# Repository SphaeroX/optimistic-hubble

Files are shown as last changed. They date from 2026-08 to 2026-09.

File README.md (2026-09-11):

# Audio Vault ESP32-C3 - Ultra-Low-Power Voice Assistant & Companion Monorepo

An embedded voice recording, signal processing, and companion application monorepo built for the **ESP32-C3**, featuring **two I2S MEMS microphones**, an **IMU sensor** with **Ultra-Low-Power Deep Sleep (< 10 µA)** & **Hardware Shock Wakeup**, **persistent Flash storage (`LittleFS`)**, and a **Flutter Multiplatform Companion App** supporting **Android, iOS, and Windows Desktop**.

---

## Monorepo Architecture

```
optimistic-hubble/
├── apps/
│   └── companion_app/           # Flutter Multiplatform App (Android, iOS, Windows, macOS, Web)
│       ├── lib/                 # Clean, modular Dart architecture (Theme, BLE, Wi-Fi sync, Telemetry)
│       ├── android/             # Android project & permissions
│       ├── ios/                 # iOS project & Info.plist permissions
│       └── windows/             # Windows desktop runner & Win32 window config
├── firmware/                    # PlatformIO ESP32-C3 Firmware
│   ├── src/                     # Audio recorder, BLE service, Wi-Fi SoftAP server, IMU drivers
│   ├── platformio.ini           # Board definitions, partition tables & compiler flags
│   └── esp32c3_hw_test.ino      # Hardware test & validation sketch
├── research/                    # IoT transfer studies, BLE/Wi-Fi benchmarks & protocol docs
├── 01_flash_mcu.bat             # Builds, flashes and monitors ESP32-C3
├── 02_run_flutter_device.bat    # Launches Flutter companion app on connected device
├── 03_build_apk.bat             # Builds Flutter Android Release APK
├── 03_flash_and_build_apk.bat   # Flashes ESP32-C3 firmware and builds Android APK
├── 04_monitor.bat               # Starts serial monitor (115200 baud)
├── 05_run_flutter_windows.bat   # Launches Flutter companion app on Windows desktop
└── 06_erase_flash.bat           # Completely wipes ESP32 Flash memory and resets LittleFS
```

---

## Quick Start Guide

### 1. Running the Flutter Companion App
* **Windows Desktop (Testing on PC):**
  ```powershell
  .\run_flutter_windows.bat
  # Or:
  cd apps\companion_app
  flutter run -d windows
  ```
* **Android:**
  ```powershell
  cd apps\companion_app
  flutter run -d android
  ```
* **iOS:**
  ```powershell
  cd apps\companion_app
  flutter run -d ios
  ```

### 2. Building, Flashing & Packaging
* **Flash MCU & Build Android APK (All-in-One):** Double-click `flash_and_build_apk.bat`
* **Build Android APK Only:** Double-click `build_apk.bat`
* **Flash MCU & Monitor:** Double-click `flash_mcu.bat`
* **Full Flash Erase & Reset:** Double-click `erase_flash.bat`

---

## Key Features

* **Ultra-Low-Power Deep Sleep (< 10 µA):** ESP32-C3 drops to ~8 µA in sleep mode, extending battery life from ~2 hours to **over 3 months** on a compact 300 mAh LiPo!
* **Hardware Shock / Tap Wake-Up:** LSM6DS3 / BMI160 / MPU-6050 configured in low-power interrupt mode automatically wakes the MCU upon shock/tap (> 1.4g) and instantly begins recording.
* **On-Demand Wi-Fi Hotspot:** High-power Wi-Fi SoftAP (~150 mA) and I2S DMA (~5 mA) are dynamically powered down during idle and activated only on-demand via BLE command or Boot button (D7).
* **Hardware Dual-Mic Noise Filtering (On-Chip DSP):** Both MEMS microphones are sampled with 100% hardware phase-synchronicity. The firmware combines both channels in real-time with coherent beamforming ($+6\text{ dB}$ voice boost and ambient noise cancellation), outputting a crystal-clear single-line mono stream.
* **4:1 IMA-ADPCM Hardware Compression (8 KB/s):** Audio is compressed on-the-fly to 4-bit per sample (8,000 bytes/sec @ 16 kHz Mono). Over **4 minutes** of audio fit into the 1.92 MB Flash partition!
* **+18 dB Digital Preamp Gain:** Integrated digital pre-amplifier with soft-limiting delivers loud, crisp, full-scale audio without clipping.
* **Universal Standard 16-Bit PCM WAV Export:** Downloads generate 100% standard Linear 16-Bit PCM WAV files (`Format Tag 1`) compatible with **Windows Media Player, VLC, QuickTime, Android, iOS, and Audacity**.
* **Zero-Drop Direct-to-Flash Streaming:** Continuous DMA queue draining and 4KB sector-aligned writes prevent buffer overruns and eliminate audio cracks or gaps.

---

## Power Consumption & Battery Life

| State | Previous Firmware | Optimized Firmware | 300 mAh Battery Runtime |
| :--- | :--- | :--- | :--- |
| **Standby / Idle** | ~180 mA (Wi-Fi AP always on) | **~8–10 µA** (Deep Sleep + IMU LP Mode) | **~2,500+ Hours (~3.5 Months)** |
| **Active Recording** | ~40 mA | **~28 mA** (Wi-Fi OFF, I2S active) | **~10.5 Hours** continuous audio |
| **Wi-Fi Sync (Burst)** | ~180 mA (Permanent) | ~150 mA (Burst only when syncing) | Auto-timeout after 2 min |

---

## Hardware Architectures & Pinout

The project supports two target hardware setups:
1. **Custom Production Board V2:** Built around the **ESP32-C3-MINI-1-N4** module (integrated 4MB Flash, 40MHz crystal & PCB antenna), an **AP2112K-3.3TRG1 LDO (600mA)**, an external **Winbond W25Q128JVSIQ (16MB)** SPI Flash on **SPI2**, dual status LEDs, and direct THT through-hole soldering for LiPo battery and tactile switch.
2. **Breadboard Prototype:** Built using an ESP32-C3 breakout board.

### Production Board V2 (ESP32-C3-MINI-1-N4) Pin Assignment

| Component | Part / IC | Module Pin | ESP32-C3 GPIO | Function / Net |
| :--- | :--- | :---: | :--- | :--- |
| **Power (3.3V)** | AP2112K-3.3 (U7) | Pin 3 | `3V3` | Regulated 3.3V power rail (600mA peak) |
| **Ground** | System GND Plane | Pins 1, 2, 11, 14, 33–53 | `GND` | Common ground rail & thermal ground |
| **I2S Stereo Mic (L)** | ICS-43434 (U4) | Pin 5, 6, 17 | GPIO 2 (SCK), 3 (WS), 4 (SD) | Left Channel (L/R $\rightarrow$ GND) |
| **I2S Stereo Mic (R)** | ICS-43434 (U5) | Pin 5, 6, 17 | GPIO 2 (SCK), 3 (WS), 4 (SD) | Right Channel (L/R $\rightarrow$ 3V3) + R10 (100k pulldown) |
| **6-Axis IMU** | LSM6DSLTR (U3) | Pin 19, 20 | GPIO 6 (SDA), GPIO 7 (SCL) | I2C Bus (`0x6A`) + R2/R3 ($4.7\text{k}\Omega$ pullups) |
| **IMU Wakeup** | LSM6DSLTR (U3) | Pin 18 | GPIO 5 (INT1) | Hardware shock/tap wakeup interrupt |
| **Status LED (Red)**| KT-0603R (D1) | Pin 16 | GPIO 10 | Recording indicator via R4 ($330\Omega$) |
| **Status LED (Grn)**| LTST-C190GKT (D2) | Pin 21 | GPIO 8 | System/Wi-Fi status via R6 ($330\Omega$) |
| **User Button** | External Switch | Pin 22 | GPIO 9 (`BTN`) | THT hole to GND (weak pull-up, boot strap) |
| **USB-C Data** | GT-USB-7010ASV (J1)| Pin 25, 26 | GPIO 18 (D-), GPIO 19 (D+) | USB CDC / JTAG serial interface |
| **Audio Flash (16MB)**| W25Q128 (U2) | Pin 28 | GPIO 21 | `FLASH_CS` (/CS on SPI2) |
| | W25Q128 (U2) | Pin 27 | GPIO 20 | `FLASH_SCK` (CLK on SPI2) |
| | W25Q128 (U2) | Pin 13 | GPIO 1 | `FLASH_MOSI` (DI on SPI2) |
| | W25Q128 (U2) | Pin 12 | GPIO 0 | `FLASH_MISO` (DO on SPI2) |
| **Battery Charger** | TP4054 (U6) | - | - | 1S Li-Ion charger via USB-C (500mA, R9 = $2\text{k}\Omega$) |

> Complete hardware design, schematics, and JLCPCB manufacturing BOM are available in [HARDWARE_DESIGN.md](file:///c:/Users/MGasc/Documents/antigravity/optimistic-hubble/HARDWARE_DESIGN.md) and [ESP32C3_PINOUT.md](file:///c:/Users/MGasc/Documents/antigravity/optimistic-hubble/ESP32C3_PINOUT.md).

---

### Prototype Wiring (ESP32-C3)

| Component | Component Pin | ESP32-C3 Pin | ESP32-C3 GPIO | Description |
| :--- | :--- | :--- | :--- | :--- |
| **Power** | 3V3 / VCC | **3V3** | - | 3.3V Power Bus |
| **Ground** | GND | **GND** | - | Common Ground Bus |
| **IMU (LSM6DS3 / BMI160)** | SCL | **D5** | GPIO 7 | Hardware I2C Clock |
| | SDA | **D4** | GPIO 6 | Hardware I2C Data |
| | SDO / SA0 | **GND** | - | Address: `0x6A` (LSM6DS3) / `0x68` (BMI160) |
| | **INT1 (Shock Interrupt)**| **D3** | **GPIO 5** | **RTC GPIO: Deep Sleep Shock Wakeup (< 10 µA)!** |
| **Mic 1 (Voice Mic / Left)**| SD / DOUT | **D2** | GPIO 4 | Shared I2S Serial Data In |
| | WS / LRCLK | **D1** | GPIO 3 | Shared I2S Word Select |
| | SCK / BCLK | **D0** | GPIO 2 | Shared I2S Bit Clock |
| | **L/R** | **GND** | - | **Tied to GND: Left Channel** |
| **Mic 2 (Noise Mic / Right)**| SD / DOUT | **D2** | GPIO 4 | Shared with Mic 1 SD |
| | WS / LRCLK | **D1** | GPIO 3 | Shared with Mic 1 WS |
| | SCK / BCLK | **D0** | GPIO 2 | Shared with Mic 1 SCK |
| | **L/R** | **3V3** | - | **Tied to 3.3V: Right Channel** |
| **Status LED (Recording Light)**| Anode (+) | **D10** | GPIO 10 | Long leg of LED to D10 |
| | Kathode (-) | **GND** (via Resistor) | - | Short leg via 220Ω–330Ω resistor to GND |
| **Manual Wi-Fi Toggle** | Boot Button / Switch | **D7** | GPIO 9 | Press to toggle Wi-Fi ON/OFF manually |

#### Storage Capacity & Recording Time Comparison

| Storage Medium | Usable Capacity | Audio Format & Bitrate | Max. Recording Time | Capacity Gain |
| :--- | :--- | :--- | :--- | :--- |
| **Internal Flash (Default)** | ~1.92 MB (LittleFS) | 16 kHz Mono ADPCM (8 KB/s) | **~4.1 minutes** (~245 s) | 1× (Baseline) |
| **W25Q128 SPI-Flash (Expanded)** | **16 MB** (~15.5–16 MB net) | 16 kHz Mono ADPCM (8 KB/s) | **~35.0 minutes** (~2,097 s) | **8.5× Increase** |
| *W25Q128 (Uncompressed)* | 16 MB | 16 kHz 16-Bit PCM (32 KB/s) | **~8.5 minutes** (~524 s) | 2.1× |
| *W25Q128 (Telephony)* | 16 MB | 8 kHz Mono ADPCM (4 KB/s) | **~70.0 minutes** (~4,194 s) | 17× (> 1 hour) |
| *W25Q256 (32 MB Optional)* | 32 MB | 16 kHz Mono ADPCM (8 KB/s) | **~70.0 minutes** (~4,194 s) | 17× |

> Detailed diagrams and breadboard guides are available in [PINOUT.md](file:///c:/Users/MGasc/Documents/antigravity/optimistic-hubble/PINOUT.md).

---

## API & Communication Specifications

### 1. Wi-Fi REST Sync API (HTTP Port 80)

* **Hotspot SSID:** `Audio-Vault-Hotspot`
* **Hotspot Password:** `audiovault2026`
* **Default Gateway / Web Dashboard:** `http://192.168.4.1`

#### Endpoints

* **`GET /api/clips`**: Returns JSON list of all recordings in Flash (`id`, `filename`, `size`, `duration`, `sampleRate`).
* **`GET /api/download?id=<clip_id>`**: Streams the requested `.wav` file directly from Flash storage.
* **`GET /api/status`**: Returns Flash memory utilization and clip counts.
* **`POST /api/clear`**: Deletes all stored recordings from Flash.
* **`GET /`**: Serves the mobile-optimized Web App with built-in Web Audio player and universal WAV exporter.

### 2. BLE GATT Signaling Specifications

* **Device Advertising Name:** `Audio-Vault`
* **Custom Service UUID:** `19b10000-e8f2-537e-4f6c-d104768a1214`
* **State Characteristic (`19b10001-...`):** `[state, latestClipId, totalClips]`
* **Tap Characteristic (`19b10003-...`):** `[tapFlag, shockMilliG]`

---

## Workflow: Recording & Syncing Voice Notes

1. **Tap the breadboard** $\rightarrow$ Status LED turns ON.
2. **Speak** into the MEMS microphones (real-time noise filtering active).
3. **Tap again** $\rightarrow$ Status LED turns OFF, audio is saved to Flash in 8 KB/s ADPCM format.
4. **Download & Play:** Launch the Flutter Companion App (via `02_run_flutter_device.bat` or `05_run_flutter_windows.bat`) and click **"WLAN Synchronisieren"** or BLE sync!

---

## Future Roadmap & Hardware To-Do List

- [ ] **Expose Wi-Fi Antenna & Optimize RF Radiation:**
  - **Problem:** Current wireless transfer throughput is limited to only ~0.11 MB/s due to RF shielding / PCB attenuation.
  - **Action:** In the next hardware/enclosure revision, reposition the ESP32-C3 module so the integrated antenna extends further outwards beyond the PCB edge with proper keepout clearance (no copper layers, traces, or battery shielding underneath the antenna) to improve signal strength and transfer speeds.

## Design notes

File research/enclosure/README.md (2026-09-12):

# Gehäuse "Audio Vault" Diktiergerät — Armband-Ausführung

Parametrisches OpenSCAD-Gehäuse für die Platine `research/3D_PCB1_2026-09-08.stl`,
getragen an einem **Garmin-Armband (22,6 mm breit, 4,5 mm dick, Nylon)**.
Akku sitzt **hinter** der Platine (an der Armseite), Platine mit Bauteilen nach außen.

```
stl/tray_print.stl     V1  Tray, Band läuft LÄNGS der Platine (Y)   ~8,0 cm³
stl/tray90_print.stl   V2  Tray, Halterung 90° gedreht (Band in X) ~7,7 cm³
stl/lid_print.stl      Deckel – für BEIDE Versionen identisch       ~2,3 cm³

V3  Geschlossene Bandkassette, Band wird DURCHGEFÄDELT (2 Schlitze, Band quer zur
    Platinenlängsachse) – GESCHLOSSEN statt offener Kanal, in drei Dicken:
stl/v3_A_slim_tray_print.stl      A slim      Wand 1,2  Kassette 1,0  →  6,3 cm³
stl/v3_B_standard_tray_print.stl  B standard  Wand 1,6  Kassette 1,2  →  8,8 cm³
stl/v3_C_robust_tray_print.stl    C robust    Wand 2,0  Kassette 1,6  → 11,7 cm³
stl/v3_{A_slim,B_standard,C_robust}_lid_print.stl   passender Deckel je Variante
stl/v3_*_tray.stl / _lid.stl      Montagelage (nur für Prüfung/Render)
audio_vault_case.scad  Quelle (alle Maße als Parameter, Schalter band_rot90/holder_kind)
build_varianten.sh     baut alle drei V3-Varianten (+ Deckel) aus der Quelle
check_v3.py            maschinelle Prüfung der Varianten (USB-C, Mikrofone, LEDs, Band)
render_bilder.sh       rendert die Doku-Bilder (bild10 … bild17)
```

### Zwei Varianten — Bandlage um 90° gedreht

| | V1 (`band_rot90=false`) | V2 (`band_rot90=true`) |
| :--- | :--- | :--- |
| Bandkanal läuft | entlang **Y** (Längsachse der Platine) | entlang **X** (quer) |
| Kanalbreite quer | X, 23,4 mm (Wangen bündig mit dem Gehäuse) | Y, 23,4 mm (Wangen 2 mm, Rest ist Bodenrand) |
| Einlegefenster | 20 mm | 15 mm (automatisch gekappt) |
| Am Arm | Gerät liegt quer zur Bandlänge, langachse läuft um den Arm | **Längsachse liegt am Arm**, USB-C und Mikrofonseite zeigen zum Ellbogen bzw. zur Hand |
| Druckdatei | `stl/tray_print.stl` | `stl/tray90_print.stl` |

**V2 entspricht der ursprünglich gewünschten Orientierung:** USB-C zum Körper,
Mikrofon (U4) zur Hand — beides liegt dann auf der Armachse. Bei V1 zeigen diese
beiden Enden quer über den Arm.

---

## 1. Was aus dem STL gemessen wurde (nicht geschätzt)

| Merkmal | Wert |
| :--- | :--- |
| Platine | 22,626 × 36,975 × 1,6 mm (x −12,814…9,811 · y −11,079…25,895) |
| Höchstes Bauteil | USB-C-Buchse J1, Oberkante **z = 4,760** |
| ESP32-C3-MINI-1 | x −10,10…3,10 · y −1,41…15,19 · Oberkante 4,10 |
| Antennenfläche (ungeschirmt) | y ≈ −1,4 … 4,2 am **−Y-Ende** des Moduls |
| Mic U4 (links) | Pad (5,50 / 23,83), **Schallloch d = 0,35 mm @ (5,50 / 24,54)** |
| Mic U5 (rechts) | Pad (5,49 / −7,54), **Schallloch d = 0,35 mm @ (5,49 / −6,83)** |
| LEDs D1/D2 | (7,19 / 14,73) und (7,19 / 16,73), leuchten nach oben |
| USB-C-Mündung | x −11,96…−3,16 · z 1,66…4,68 (Mitte −7,557 / 3,17) |
| THT-Lötlöcher (d 0,85) | (8,00 / 22,97) (8,00 / 24,64) (9,02 / −0,89) (−11,94 / 6,10) |
| USB-C-Befestigungsschlitze | 4× im Bereich x −12,2…−3,0 / y −9,1…−3,4 |

**Wichtigster Befund:** Die ICS-43434 sind **Bottom-Port-Mikrofone**. Der Schall
kommt durch die 0,35-mm-Löcher in der **Platinenunterseite** — also ausgerechnet
von der Akkuseite. Das Gehäuse führt den Schall deshalb über zwei **Schallschlitze
in den Seitenwänden** in den 1,6-mm-Spalt zwischen Platinenunterseite und Akku.
Würde man das Gehäuse an dieser Stelle dicht machen, wären beide Mikrofone taub.

---

## 2. Aufbau (von der Armseite nach außen)

```
        Band 4,5 mm  ── im Clip-Kanal, 23,4 × 5,5 mm, Lippen halten es
   ┌──────────────────────────────┐
   │ Clip: 2 Wangen + Innenlippen │  5,5 mm + 1,2 mm Lippe
   ├──────────────────────────────┤  Tray-Boden 1,6 mm
   │ Akkutasche  22,2 × 36,6 × 11,3│  Akku (Vorgabe 20 × 33 × 9,87)
   ├──────────────────────────────┤  +0,8 mm Luft
   │ Akustikspalt  1,6 mm         │  ← Schallschlitze münden hier
   ├──────────────────────────────┤  Platine 1,6 mm (liegt auf 1 mm Schulter)
   │ Bauteile bis 4,76 mm         │  +0,6 mm Luft
   ├──────────────────────────────┤  Deckelplatte 2,0 mm
   └──────────────────────────────┘
```

Außenmaße: **27,4 × 41,8 × 28,3 mm** (inkl. Deckel und Clip), Volumen 10,1 cm³
→ ca. 12 g PLA massiv, mit 25 % Infill ~7 g.

| Loch / Öffnung | Lage | Größe |
| :--- | :--- | :--- |
| USB-C-Aussparung | Wand −Y | 9,0 × 3,18 mm (x −12,06…−3,06 · z 1,60…4,78) |
| Schallschlitz Mic U4 | Wand **+Y** | 6,0 × 1,05 mm (x 2,5…8,5 · z −1,55…−0,45) |
| Schallschlitz Mic U5 | Wand **−Y** | 6,0 × 1,05 mm, gleiche Höhe |
| LED-Sichtfenster | Deckel | Langloch 1,9 × 6,45 mm + 45°-Trichter innen (Lichtsammler) |
| Antennenfeld | Deckel außen | 14 × 7,5 mm, 0,8 mm tief → nur noch 1,2 mm Wand |
| Rastnut | Innenwand rundum | 0,3 mm tief, Deckel rastet mit 4 Nocken ein |
| Kabeldurchführungen | Schulter | an den 3 THT-Lochgruppen |
| Bandkanal | Rückseite | 23,4 × 5,5 mm, Lippen 3 × 1,2 mm, Einlegefenster 20 mm (V1) / 15 mm (V2) |

---

## 3. Parameter (oben in `audio_vault_case.scad`)

```scad
batt_t   = 9.87;   // <<< AKKUDICKE - hier anpassen
batt_w   = 20.0;   // Akku-Breite  (X)   <- bitte prüfen
batt_l   = 33.0;   // Akku-Länge   (Y)   <- bitte prüfen
band_w   = 22.6;   // Armbandbreite
band_t   = 4.5;    // Armbanddicke
gap_under_pcb = 1.6;  // Akustikspalt (kleiner = weniger Hohlraumklang)
wall     = 1.6;    // Wandstärke (0,4 mm weniger = 0,8 mm flacheres Gerät)
```
`band_rot90 = true/false` schaltet zwischen V1 und V2 um (der Deckel ist in
beiden Fällen identisch, weil der Clip nichts mit dem Deckel zu tun hat).

Nach Änderungen neu exportieren:
```bash
openscad -o stl/tray_print.stl   -D 'part="tray_print"' -D 'band_rot90=false' audio_vault_case.scad
openscad -o stl/tray90_print.stl -D 'part="tray_print"' -D 'band_rot90=true'  audio_vault_case.scad
openscad -o stl/lid_print.stl    -D 'part="lid_print"'                        audio_vault_case.scad
```

---

## 4. Drucken

* **Tray**: `stl/tray_print.stl` — liegt schon richtig (Clip auf dem Bett,
  Öffnung oben). **Keine Stützen.** Die Decke des Bandkanals wird als 23 mm
  Brücke gedruckt; wenn dein Drucker das schlecht kann: Stützen nur dort.
* **Deckel**: `stl/lid_print.stl` — Außenseite liegt auf dem Bett, Rand und
  die 3 Niederhalter-Stifte stehen nach oben. Keine Stützen.
* 0,15–0,2 mm Schichthöhe, 3 Perimeter, 25 % Infill (Gyroid).
* **PLA oder PETG, auf keinen Fall Metall-/Carbon-Filament** — das Antennenfeld
  (1,2 mm Wand über dem ESP-Modul) muss HF-durchlässig bleiben.

## 5. Montage

1. Akku- und Tasterlitzen **vor** dem Einlegen an die THT-Löcher löten
   (Positionen siehe Tabelle; Kabelwege sind als Fenster in der Schulter frei).
2. Platine in den Tray legen — sie liegt auf der umlaufenden 1-mm-Schulter,
   Bauteile nach oben. Kabel neben der Platine durch die Fenster führen.
3. Akku in die Tasche, Litzen am Platinenrand nach oben.
4. *(Empfehlung)* dünnes Moosgummi-/Filz-Ringchen (Ø ~6 mm) um jedes
   Mikrofon-Schallloch auf die Platinenunterseite kleben: verkleinert das
   Frontvolumen von ~1,3 cm³ auf wenige mm³ → deutlich klarerer Klang.
5. Optional Klarsichtband/Klebertropfen über das LED-Fenster (Staubschutz).
6. Deckel aufsetzen und einrasten (4 Nocken in der Nut); die 3 Stifte drücken
   die Platine auf die Schulter.
7. Armband: entweder längs durch den Kanal schieben oder im Fenster ohne Lippen
   (mittig) von unten eindrücken und dann zentrieren.
   Das 4,5-mm-Band wird mit 0,2 mm Übermaß geklemmt — es sitzt stramm.
   V2 liegt dabei quer auf dem Arm, d. h. der Kanal läuft über die Bandbreite
   (23,4 mm Kanal für 22,6 mm Band, 15 mm Einlegefenster).

## 6. Orientierung am Arm

Das −Y-Ende des Gehäuses ist die **USB-C-Buchse**, das +Y-Ende die
**Mikrofonseite** (Mic U4 sitzt dort). Beide Gehäuse sind in dieser Achse
symmetrisch — ein Umdrehen um 180° auf dem Band genügt, um zu tauschen,
welches Ende zum Ellbogen zeigt.

* **V2** (empfohlen für „USB zu mir / Mikrofon zur Hand“): Längsachse liegt
  auf der Armachse, USB-C zeigt zum Körper, Mikrofon zur Hand.
* **V1**: Band läuft längs der Platine, die Enden zeigen quer über den Arm
  (USB-C nach innen oder außen).

---

## 7. Prüfergebnisse (automatisiert, nicht per Auge)

`check_collision.py` (Punkt-in-Körper, Ray-Parity mit 3 Richtungen, Mehrheits-
entscheid; die PCB-Baugruppe wird mit bis zu 200 000 Oberflächenpunkten geprüft)
und `check_shell.py` (Scan der Wand-Mittenflächen auf ungewollte Öffnungen):

```
V1: 11/11 Kollisionschecks bestanden
V2: 11/11 Kollisionschecks bestanden
    PCB <-> Tray                  0 Punkte im Material
    PCB <-> Deckel                0 Punkte im Material
    Akku 20x33x9.87 <-> Tray      0 Punkte im Material
    USB-Stecker <-> Tray/Deckel   0 Punkte (Mündung 9,0 x 3,18 mm passt)
    Band 4,29 mm                  läuft frei
    Band 4,50 mm                  klemmt mit genau 0,200 mm (gewollt)
    LED 1/2 Sichtkanal d=1,7 mm   0 Punkte (Lichtweg frei)
    Schallweg Mic U4 / U5         0 Punkte (Weg außen -> unter das Schalloch frei)
WAND-INTEGRITAET: ALLES OK
    einzige Öffnungen: USB-Aussparung, 2 Schallschlitze, LED-Fenster, Eckfasen
```

Beide Teile sind **wasserdicht und einteilig** (`trimesh`: watertight=True, 1 Körper,
Tray 8,03 cm³ / Tray90 7,67 cm³ / Deckel 2,30 cm³).

Prüfbefehle für beide Varianten (OpenSCAD rendert vorher `stl/tray.stl` bzw.
`stl/tray90.stl` und `stl/lid.stl` mit `part="tray"/"lid"`):
```bash
python check_collision.py                                        # V1
BAND90=1 TRAY_STL=stl/tray90.stl python check_collision.py       # V2
python check_shell.py                                            # V1
BAND90=1 TRAY_STL=stl/tray90.stl python check_shell.py           # V2
```

## 8. Offene Punkte

* **Akku-Fußabdruck** ist mit 20 × 33 mm angenommen (nur die Dicke 9,87 mm war
  bekannt). Größer geht bis 22,2 × 36,6 mm — dann `batt_w/batt_l` anpassen.
* **Taster**: die vier THT-Lötpunkte sind über die Schulter-Fenster erreichbar,
  ein Taster braucht aber noch eine Deckelöffnung (im Modell nicht enthalten).
* **Akustik**: der Spalt unter der Platine ist ein ~1,3-cm³-Hohlraum; ohne das
  Moosgummi aus Schritt 4 klingt es bauchig (Resonanz grob bei 200 Hz).
* **WLAN**: Antenne zeigt nach außen, Deckel dort nur 1,2 mm — der Akku liegt
  allerdings hinter der Platine und schirmt mit. Falls der Durchsatz klemmt,
  Akku kürzer wählen und die Antennenzone freihalten.
* Passung Deckel/Tray: `rim_clr = 0.15`, Nocken 0,25 mm über den Rand. Bei
  zu strammem/zu lockerem Sitz diese Werte in 0,1-mm-Schritten anpassen.

---

# V3 — geschlossene Bandkassette: Band wird durchgefädelt

Wunsch: Halterung **nicht offen** (kein Kanal mit Lippen und Einlegefenster),
sondern ein Gehäuse, durch das das Armband **gefädelt** wird – mit **Doppelschlitz**,
damit es nicht am Band rutscht. Band quer zur Platinenlängsachse (wie V2), Bandmaß
des Nutzers: **24,70 … 24,75 mm breit, 2–3 mm dick**.

## 9.1 Prinzip: Leiterschnalle statt Kanal

Unter dem Tray sitzt eine **geschlossene Kassette** (Bandschacht 25,25–25,55 ×
3,2–3,6 mm im Querschnitt) mit **zwei Schlitzen** in der Deckschicht. Das Band wird
gefädelt: **rein durch Schlitz 1 → innerhalb der Kassette über den Steg → raus durch
Schlitz 2.** Der Steg zwingt das Band in eine Faltung (wie eine Leiterschnalle /
„ladder lock"), dadurch:

* das Gehäuse kann nicht vom Band rutschen (die Faltung hält es),
* Zug am Band klemmt die Faltung fest,
* bewusst verschieben geht trotzdem (Band entlasten, schieben),
* das Band ist im Bereich des Gehäuses **vollständig verdeckt** – nichts ist offen,
* die zwei Schlitze liegen 12–13 mm auseinander, das Gehäuse kann nicht kippeln.

## 9.2 Die drei Dicken-Varianten

| | A **slim** | B **standard** | C **robust** |
| :--- | :--- | :--- | :--- |
| Wandstärke | 1,2 mm | 1,6 mm | 2,0 mm |
| Deckelplatte | 1,5 mm | 2,0 mm | 2,4 mm |
| Akkuluft / Boden | 0,5 / 1,2 mm | 0,8 / 1,6 mm | 1,2 / 2,0 mm |
| Akustikspalt | 1,2 mm | 1,6 mm | 2,0 mm |
| Kassettendeckschicht | 1,0 mm | 1,2 mm | 1,6 mm |
| Schlitz / Steg | 8 / 5 mm | 7 / 5 mm | 7 / 5 mm |
| **Außenmaß (X × Y)** | **26,2 × 40,6 mm** | 27,4 × 41,8 mm | 29,0 × 43,0 mm |
| **Bauhöhe Tray+Deckel** | **21,0 mm** | 22,8 mm | 24,6 mm |
| **Bauhöhe mit Kassette** | **25,4 mm** | 27,4 mm | 29,6 mm |
| Tray-Volumen | 6,25 cm³ | 8,82 cm³ | 11,65 cm³ |
| Deckel-Volumen | 1,61 cm³ | 2,30 cm³ | 2,96 cm³ |
| Schallschlitz-Höhe | 0,7 mm | 1,1 mm | 1,5 mm |
| Charakter | dünnstes, leichtestes Gehäuse; 1,2-mm-Wände und 0,7-mm-Schallschlitz sind die Untergrenze für FDM | Alltagsvariante, gute Reserve | dick, steif, großzügige Toleranzen; Kassette 1,6 mm trägt mehr Bandzug |

Alle drei Varianten haben dieselben **Aussparungen** – maschinell geprüft (9.4):

| Öffnung | Lage | Größe | wofür |
| :--- | :--- | :--- | :--- |
| USB-C-Aussparung | Wand −Y | **9,0 × 3,18 mm** | Stecker passt durch (Mock 8,34 × 2,56 mm) |
| Schallschlitz Mic U4 | Wand +Y | **6,0 × 0,7–1,5 mm** | Bottom-Port-Mikrofon hört in den Akustikspalt |
| Schallschlitz Mic U5 | Wand −Y | 6,0 × 0,7–1,5 mm | zweites Mikrofon |
| LED-Sichtfenster | Deckel | Langloch 1,9 × (13,45…18,00) + 45°-Trichter | beide LEDs |

Mit dieser Öffnungsliste wird auch bestätigt, dass die Kassette selbst **nur** die
zwei Bandschlitze als Öffnung hat (Deckschicht sonst dicht).

## 9.3 Einfädeln

1. Bandende durch **Schlitz 1** von unten in die Kassette schieben (die Kanten sind
   45° gefast).
2. Ende innerhalb der Kassette über den **Steg** führen (der Faltraum ist 0,4 mm
   höher als das Band) und durch **Schlitz 2** wieder herausziehen.
3. Band durchziehen, bis das Gehäuse an der gewünschten Stelle sitzt; Band spannen –
   die Faltung klemmt.
4. Banddicke anpassen: `b3_t` in `audio_vault_case.scad` (bzw. `b3_t=…` in
   `build_varianten.sh`) – 2,0 mm und 3,0 mm sind beide geprüft. Bei 2,0 mm Band
   bleibt mehr Luft im Faltraum, der Halt kommt aus der Faltung, nicht aus Klemmung.

## 9.4 Prüfungen (maschinell, `python check_v3.py`)

```
Variante A_slim: 12/12 · B_standard: 12/12 · C_robust: 12/12
  Tray/Deckel: wasserdicht, je 1 Körper, Außenmaße = berechnete Maße (±0,05 mm)
  Platine / Akku 20×33×9,87     0 Punkte im Material
  USB-C-Stecker 8,34×2,56       0 Punkte  (Aussparung 9,0 × 3,18 mm)
  Schallweg Mic U4 / U5         0 Punkte  (Schlitz 6 × 0,7 … 1,5 mm)
  LED-Sichtkanal d=1,7 mm       0 Punkte  (Deckel)
  Band 2,0 mm und 3,0 mm durchgefädelt: kein Eindringen (nur Wandberührung, 0,000 mm)
  Kassette: nur die 2 Schlitze offen (0 Punkte außerhalb)
  Deckel-Mittenebene: nur LED-Fenster offen
```

## 9.5 Drucken

* **Tray**: `stl/v3_<X>_tray_print.stl` – liegt richtig (Kassette unten auf dem Bett,
  Öffnung oben). Die Decke über dem Bandschacht ist eine **25 mm breite Brücke**;
  wenn der Drucker das schlecht kann: Stützen nur dort, sonst keine.
* **Deckel**: `stl/v3_<X>_lid_print.stl` – Außenseite liegt auf dem Bett.
* 0,15–0,2 mm Schicht, 3 Perimeter, 25 % Infill. **Kein Metall-/Carbon-Filament**
  (Antennenfeld).
* Variante C wiegt ~1,5 × Variante A – bei gleichem Material ist A die leichte,
  C die steife Ausführung.

## 9.6 Neu bauen

```bash
bash build_varianten.sh                       # alle drei Varianten + Deckel
python check_v3.py                            # 12 Prüfungen je Variante
bash render_bilder.sh                         # Doku-Bilder bild10 … bild17
# Einzelvariante mit abweichenden Maßen:
openscad -o test.stl -D 'part="tray_thread"' -D 'wall=1.4' -D 'b3_plate=1.1' \
         -D 'lid_t=1.8' audio_vault_case.scad
```

Bilder: `bild10_v3_assembly.png` (Baugruppe mit gefädeltem Band),
`bild11_v3_schnitt_faltung.png` + `bild12_v3_zoom_faltung.png` (Schnitt/Detail der
Faltung über den Steg), `bild13_v3_ruecken.png` (von unten),
`bild14_v3_druck.png` (Drucklage), `bild15/16/17_v3_{slim,standard,robust}.png`
(die drei Varianten im Vergleich).

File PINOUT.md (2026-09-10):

# Hardware Pinout & Verdrahtungs-Leitfaden (Wiring Guide)
## Custom Production PCB V2 (ESP32-C3-MINI-1-N4)

Dieses Dokument dient als zentrale Referenz für Entwickler und Hardware-Ingenieure für das kundenspezifische **Serienboard (Production PCB V2)** mit dem **ESP32-C3-MINI-1-N4** Modul.

---

## 1. Vollständige Pin-Zuordnungs-Tabelle (Custom PCB V2)

| Komponente | Komponenten-Pin | ESP32-C3 Modul-Pin | ESP32-C3 GPIO | Funktion / Signalbeschreibung |
| :--- | :--- | :--- | :--- | :--- |
| **Power Rail** | 3.3V / VDD | **Pin 3** | - | **3,3V-Hauptversorgung** aus AP2112K LDO (U7) |
| **Ground Rail** | GND / Masse | **Pins 1, 2, 11, 14, 36–53** | - | **Gemeinsame Systemmasse** (Common Ground Bus) |
| **6-Achsen IMU**<br>(ST LSM6DSLTR, U3) | VDD / VDDIO | **Pin 3** | - | 3,3V Versorgungsspannung (U3 Pin 5 & 8) + C8 (100nF) |
| | GND | **GND** | - | Masse (U3 Pins 6 & 7) |
| | SCL | **Pin 20** | **GPIO 7** | I2C Clock (SCL) + R3 (4,7kΩ Pull-up nach 3V3) |
| | SDA | **Pin 19** | **GPIO 6** | I2C Data (SDA) + R2 (4,7kΩ Pull-up nach 3V3) |
| | SDO / SA0 | **GND** | - | Setzt I2C-Adresse fest auf **`0x6A`** |
| | CS | **3V3** | - | I2C-Modus aktivieren (CS auf HIGH) |
| | **INT1 (Shock/Tap)** | **Pin 18** | **GPIO 5** | **RTC-GPIO Interrupt:** Weckt ESP32-C3 aus Deep Sleep (< 10 µA)! |
| **Mikrofon 1**<br>(Links, ICS-43434, U4) | VDD | **Pin 3** | - | 3,3V Versorgungsspannung (U4 Pin 5) + C9 (100nF) |
| | GND | **GND** | - | Masse (U4 Pin 3) |
| | SCK / BCLK | **Pin 5** | **GPIO 2** | Shared I2S Bit Clock (BCLK) |
| | WS / LRCLK | **Pin 6** | **GPIO 3** | Shared I2S Word Select (Frame Clock) |
| | SD / DOUT | **Pin 17** | **GPIO 4** | Shared I2S Seriendaten + **R10 (100kΩ Pulldown)** |
| | **L/R** | **GND** | - | **Fest an GND: Konfiguriert Mikrofon 1 als LINKEN Kanal** |
| **Mikrofon 2**<br>(Rechts, ICS-43434, U5) | VDD | **Pin 3** | - | 3,3V Versorgungsspannung (U5 Pin 5) + C10 (100nF) |
| | GND | **GND** | - | Masse (U5 Pin 3) |
| | SCK / BCLK | **Pin 5** | **GPIO 2** | Parallel an Mic 1 SCK (Shared I2S Bus) |
| | WS / LRCLK | **Pin 6** | **GPIO 3** | Parallel an Mic 1 WS (Shared I2S Bus) |
| | SD / DOUT | **Pin 17** | **GPIO 4** | Parallel an Mic 1 SD (Shared I2S Bus) |
| | **L/R** | **3V3** | - | **Fest an 3V3: Konfiguriert Mikrofon 2 als RECHTEN Kanal** |
| **Status-LED D1**<br>(Aufnahme-Indikator, Rot) | Anode (+) | **3V3** | - | Anode fest an 3,3V |
| | Kathode (-) | **Pin 16** (via R4: 330Ω) | **GPIO 10** | Aktiv-LOW: GPIO 10 LOW schaltet D1 EIN |
| **Status-LED D2**<br>(System / WLAN, Grün) | Anode (+) | **3V3** | - | Anode fest an 3,3V |
| | Kathode (-) | **Pin 21** (via R6: 330Ω) | **GPIO 8** | Aktiv-LOW: GPIO 8 LOW schaltet D2 EIN |
| **User Switch / Button** | Taster Pin A | **Pin 22** | **GPIO 9** | Verbunden mit THT-Lötbohrung `BTN` & Testpad `BOOT` |
| | Taster Pin B | **GND** | - | Taster schaltet GPIO 9 gegen Masse (interner Pull-up) |
| **Externer SPI-Flash**<br>(Winbond W25Q128, U2) | VCC | **Pin 3** | - | 3,3V Stromversorgung + C7 (100nF) |
| | GND | **GND** | - | Masse (Pin 4) |
| | /CS (Chip Select) | **Pin 28** | **GPIO 21** | SPI2 Chip Select (Aktiv-LOW) |
| | CLK / SCK | **Pin 27** | **GPIO 20** | SPI2 Bus-Takt |
| | DI / MOSI | **Pin 13** | **GPIO 1** | SPI2 MOSI (Master Out -> Slave In) |
| | DO / MISO | **Pin 12** | **GPIO 0** | SPI2 MISO (Slave Out -> Master In) |
| | /HOLD & /WP | **3V3** | - | Fest an 3V3 gebunden (Standard-SPI Modus) |
| **USB-C Schnittstelle**<br>(GT-USB-7010ASV, J1) | D− (USB_DN) | **Pin 25** | **GPIO 18** | Nativer USB-Serial / JTAG Controller |
| | D+ (USB_DP) | **Pin 26** | **GPIO 19** | Nativer USB-Serial / JTAG Controller |
| | CC1 / CC2 | *(J1 Pins)* | - | Über R7 / R8 (5,1kΩ) nach GND terminiert |
| **Batterieladung & LDO** | TP4054 PROG | *(U6 Pin 5)* | - | R9 (2kΩ) nach GND -> 500mA Konstantstrom |
| | AP2112K LDO | *(U7)* | - | 600mA Low-Dropout Regler, Ausgang an `3V3` |
| | Akku-Lötbohrungen | **THT Holes** | - | `BAT+` (VBAT) und `BAT-` (GND) für 1S LiPo-Litze |
| | Testpunkte | **THT Pads** | - | `VDD+`, `BAT-`, `PCHG_DETECT`, `PCHG_PROG`, `BOOT`, `RESET` |

---

## 2. Detaillierte Schaltbilder & Bus-Konzepte

### 2.1 Gemeinsamer Stereo I2S-Bus (ICS-43434 Multiplexing)

Beide I2S-MEMS-Mikrofone (U4 & U5) teilen sich dieselben drei Signalleitungen am ESP32-C3:

```
        ESP32-C3 GPIO 2 (SCK)  -------------------+-------------------+
        ESP32-C3 GPIO 3 (WS)   --------------+    |                   |
        ESP32-C3 GPIO 4 (SD)   ---------+    |    |                   |
                                        |    |    |                   |
                                      +-------------+       +-------------+
                                      | U4 (Links)  |       | U5 (Rechts) |
                                      | ICS-43434   |       | ICS-43434   |
                                      +-------------+       +-------------+
                                      | 4: SCK      |       | 4: SCK      |
                                      | 1: WS       |       | 1: WS       |
                                      | 6: SD       |       | 6: SD       |
                                      | 2: L/R      |       | 2: L/R      |
                                      | 5: VDD(3V3) |       | 5: VDD(3V3) |
                                      | 3: GND      |       | 3: GND      |
                                      +-------------+       +-------------+
                                             |                     |
                                            GND                   3V3
                                       (Linker Kanal)        (Rechter Kanal)
```

* **Funktionsweise des Multiplexings:**
  * **Word Select (`WS` = LOW):** Mikrofon U4 aktiviert seinen Tri-State-Ausgang und sendet 24-Bit Audiodaten des **linken Kanals** über `SD`. Mikrofon U5 befindet sich im hochohmigen Zustand (Hi-Z).
  * **Word Select (`WS` = HIGH):** Mikrofon U5 aktiviert seinen Ausgang und sendet die Daten des **rechten Kanals** über `SD`. Mikrofon U4 ist im Hi-Z-Zustand.
  * **R10 (100 kΩ Pulldown an SD):** Zieht die Datenleitung in den Umschaltphasen definiert gegen Masse und verhindert kapazitives Rauschen.

---

### 2.2 Status-LEDs (D1 Rot, D2 Grün)

```
        3.3V Rail
           |
           +--------------------+
           |                    |
        +-----+              +-----+
        | D1  | LED Rot      | D2  | LED Grün
        | (A) | (Aufnahme)   | (A) | (System)
        +-----+              +-----+
        | (K) |              | (K) |
        +-----+              +-----+
           |                    |
       [ R4: 330Ω ]         [ R6: 330Ω ]
           |                    |
      GPIO 10 (Pin 16)      GPIO 8 (Pin 21)
       (Aktiv-LOW)          (Aktiv-LOW)
```

* **Software-Steuerung:**
  * LED Einschalten: `digitalWrite(PIN, LOW);` (Strom fließt von 3V3 über Vorwiderstand in den GPIO).
  * LED Ausschalten: `digitalWrite(PIN, HIGH);` oder Pin auf `INPUT` (Tri-State).

---

## 3. Software-Konfigurations-Auszug (`firmware/src/config.h`)

Die Firmware-Pindefinitionen stimmen exakt mit dem Produktionsschaltplan überein:

```cpp
// I2C Pins für 6-Achsen IMU (LSM6DSL)
#define PIN_I2C_SDA      6   // GPIO 6 (Modul-Pin 19)
#define PIN_I2C_SCL      7   // GPIO 7 (Modul-Pin 20)
#define PIN_IMU_INT      5   // GPIO 5 (Modul-Pin 18) - RTC Wakeup Interrupt
#define PIN_BOOT_BTN     9   // GPIO 9 (Modul-Pin 22) - THT BTN / Boot Button

// I2S Stereo Mikrofon Pins (ICS-43434)
#define PIN_I2S_SCK      2   // GPIO 2 (Modul-Pin 5)  - Bit Clock
#define PIN_I2S_WS       3   // GPIO 3 (Modul-Pin 6)  - Word Select / LRCLK
#define PIN_I2S_SD       4   // GPIO 4 (Modul-Pin 17) - Serial Data

// Status LEDs
#define PIN_STATUS_LED  10   // GPIO 10 (Modul-Pin 16) - D1 Rot (Aufnahme)
#define PIN_LED_GREEN    8   // GPIO 8  (Modul-Pin 21) - D2 Grün (Status / WLAN)

// Externer Audio SPI-Flash (W25Q128 auf SPI2)
#define PIN_FLASH_CS    21   // GPIO 21 (Modul-Pin 28) - /CS
#define PIN_FLASH_SCK   20   // GPIO 20 (Modul-Pin 27) - CLK
#define PIN_FLASH_MOSI   1   // GPIO 1  (Modul-Pin 13) - DI
#define PIN_FLASH_MISO   0   // GPIO 0  (Modul-Pin 12) - DO
```

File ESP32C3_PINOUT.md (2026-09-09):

# ESP32-C3-MINI-1-N4 — Pinout & Hardware-Spezifikation für Diktiergerät V2 (Production)

**Modul:** U1 · ESP32-C3-MINI-1-N4 (LCSC: **C2934560**, Espressif) · 53 SMD-Pads (13,2 mm × 16,6 mm × 2,4 mm)  
**Merkmale:** Integrierter 4 MB SPI-Flash, integrierter 40 MHz Quarz, integrierte PCB-Antenne (MIFA)  
**Quellen:** Espressif ESP32-C3-MINI-1 Datasheet v2.2 (Tab. 3-1, Tab. 4-1) · Schaltplan `SCHEMATIC_V2.png` · Stückliste `docs/hardware/BOM_V2_ESP32C3_MINI1.xlsx`

> [!IMPORTANT]
> **Vorteil gegenüber dem alten Bare-Die QFN-32 Design:**  
> Das Produktionsboard setzt auf das vollintegrierte **ESP32-C3-MINI-1-N4** Modul. Dadurch entfallen:
> 1. Der externe 40 MHz Quarz (Y1) sowie die Lastkondensatoren (C12, C13).
> 2. Die externe 2,4 GHz Chip-Antenne (A1, C293767).
> 3. Das diskrete HF-π-Matching-Netzwerk (C14, L1, C15).
> 
> Das Modul ist funkzertifiziert (CE / FCC / SRRC), garantiert optimale HF-Stabilität und reduziert die Bauteilanzahl und Bestückungsrisiken drastisch.

---

## 1. Vollständige 53-Pin Modul-Tabelle (ESP32-C3-MINI-1)

| Modul-Pin | Signalname | ESP32-C3 GPIO / Funktion | Funktion im V2-Design | Verbunden mit | Typ / Bemerkung |
| :---: | :--- | :--- | :--- | :--- | :--- |
| **1** | GND | Masse | System-Masse | `GND` | Power |
| **2** | GND | Masse | System-Masse | `GND` | Power |
| **3** | 3V3 | VDD (3,0 V – 3,6 V) | 3,3V-Hauptversorgung | `3V3` (LDO U7 Ausgang) + C1 (100nF) | Power In |
| **4** | NC | — | Unbelegt | Nicht verbunden (NC) | Frei |
| **5** | IO2 | GPIO2 / ADC1_CH2 | I2S Bit Clock (SCK / BCLK) | U4 Pin 4 & U5 Pin 4 (Shared I2S) | ⚠️ **Strapping-Pin** (Pull-down im Boot) |
| **6** | IO3 | GPIO3 / ADC1_CH3 | I2S Word Select (WS / LRCLK) | U4 Pin 1 & U5 Pin 1 (Shared I2S) | I/O |
| **7** | NC | — | Unbelegt | Nicht verbunden (NC) | Frei |
| **8** | EN | CHIP_EN / RESET | Hardware-Reset & Enable | R5 (10k → `3V3`), C11 (100nF → `GND`), Testpad `RESET` | Aktiv-High / RC-Glied |
| **9** | NC | — | Unbelegt | Nicht verbunden (NC) | Frei |
| **10** | NC | — | Unbelegt | Nicht verbunden (NC) | Frei |
| **11** | GND | Masse | System-Masse | `GND` | Power |
| **12** | IO0 | GPIO0 / ADC1_CH0 | Flash MISO (DO / IO1) | U2 Pin 2 (W25Q128 DO) | SPI2 Daten-Eingang |
| **13** | IO1 | GPIO1 / ADC1_CH1 | Flash MOSI (DI / IO0) | U2 Pin 5 (W25Q128 DI) | SPI2 Daten-Ausgang |
| **14** | GND | Masse | System-Masse | `GND` | Power |
| **15** | NC | — | Unbelegt | Nicht verbunden (NC) | Frei |
| **16** | IO10 | GPIO10 / FSPICS0 | Status-LED Rot (D1) | D1 Kathode über R4 (330Ω) nach `3V3` | Aktiv-LOW (Aufnahme-Indikator) |
| **17** | IO4 | GPIO4 / ADC1_CH4 | I2S Serial Data (SD / DOUT) | U4 Pin 6 & U5 Pin 6 + R10 (100kΩ → `GND`) | Shared I2S Mikrofondaten |
| **18** | IO5 | GPIO5 / ADC2_CH0 | IMU Wakeup Interrupt (INT1) | U3 Pin 4 (LSM6DSL INT1) | RTC-GPIO / Deep-Sleep Wakeup |
| **19** | IO6 | GPIO6 | I2C Data (SDA) | U3 Pin 14 (LSM6DSL SDA) + R2 (4,7kΩ → `3V3`) | I2C-Bus (Hardware) |
| **20** | IO7 | GPIO7 | I2C Clock (SCL) | U3 Pin 13 (LSM6DSL SCL) + R3 (4,7kΩ → `3V3`) | I2C-Bus (Hardware) |
| **21** | IO8 | GPIO8 | Status-LED Grün (D2) | Kathode D2 über R6 (330Ω) nach `3V3` | ⚠️ **Strapping-Pin** (ROM-Log Print) |
| **22** | IO9 | GPIO9 | User-Button / Switch (`BTN`) | THT-Bohrung `BTN` → Taster → `GND` + Testpad `BOOT` | ⚠️ **Strapping-Pin** (interner Pull-up) |
| **23** | NC | — | Unbelegt | Nicht verbunden (NC) | Frei |
| **24** | NC | — | Unbelegt | Nicht verbunden (NC) | Frei |
| **25** | IO18 | GPIO18 / USB_D- | USB 2.0 Full-Speed D− | J1 USB-C Pin A7/B7 (USB_DN) | Nativer USB-Serial / JTAG |
| **26** | IO19 | GPIO19 / USB_D+ | USB 2.0 Full-Speed D+ | J1 USB-C Pin A6/B6 (USB_DP) | Nativer USB-Serial / JTAG |
| **27** | IO20 | GPIO20 / U0RXD | Flash SPI Clock (SCK) | U2 Pin 6 (W25Q128 CLK) | SPI2 Bus Clock |
| **28** | IO21 | GPIO21 / U0TXD | Flash Chip Select (/CS) | U2 Pin 1 (W25Q128 /CS) | SPI2 Chip Select |
| **29** | NC | — | Unbelegt | Nicht verbunden (NC) | Frei |
| **30** | NC | — | Unbelegt (optional UART RX) | Nicht verbunden (NC) | Frei |
| **31** | NC | — | Unbelegt (optional UART TX) | Nicht verbunden (NC) | Frei |
| **32** | NC | — | Unbelegt | Nicht verbunden (NC) | Frei |
| **33** | NC | — | Unbelegt | Nicht verbunden (NC) | Frei |
| **34** | NC | — | Unbelegt | Nicht verbunden (NC) | Frei |
| **35** | NC | — | Unbelegt | Nicht verbunden (NC) | Frei |
| **36–53** | GND | Center Thermal / Ground | Thermische Anbindung / Masse | `GND` (großflächige Massefläche mit Via-Matrix) | Ground & Wärmeableitung |

---

## 2. Kompakte GPIO-Funktionsmatrix (GPIO 0 bis 21)

| GPIO | Modul-Pin | Primäre Peripherie | Funktion im Design | Ziel-Komponente & Pins | Pegel / Besonderheit |
| :---: | :---: | :--- | :--- | :--- | :--- |
| **GPIO 0** | Pin 12 | SPI2 MISO | Flash Data Out (DO) | U2 Pin 2 (W25Q128 DO / IO1) | Digital In |
| **GPIO 1** | Pin 13 | SPI2 MOSI | Flash Data In (DI) | U2 Pin 5 (W25Q128 DI / IO0) | Digital Out |
| **GPIO 2** | Pin 5 | I2S SCK | Microphone Bit Clock (BCLK) | U4 Pin 4 & U5 Pin 4 | ⚠️ **Strapping-Pin** (Default: Low) |
| **GPIO 3** | Pin 6 | I2S WS | Microphone Frame Clock (LRCLK)| U4 Pin 1 & U5 Pin 1 | Digital Out |
| **GPIO 4** | Pin 17 | I2S SD | Microphone Data Line (DIN) | U4 Pin 6 & U5 Pin 6 + R10 (100kΩ) | Digital In (Shared Bus) |
| **GPIO 5** | Pin 18 | RTC GPIO5 | IMU Hardware Shock/Tap Wakeup | U3 Pin 4 (LSM6DSL INT1) | RTC Interrupt / Deep-Sleep Wake |
| **GPIO 6** | Pin 19 | I2C0 SDA | Sensor Bus Datenleitung | U3 Pin 14 + R2 (4,7kΩ Pull-up) | Open-Drain / I2C Fast Mode (400 kHz) |
| **GPIO 7** | Pin 20 | I2C0 SCL | Sensor Bus Taktleitung | U3 Pin 13 + R3 (4,7kΩ Pull-up) | Open-Drain / I2C Fast Mode (400 kHz) |
| **GPIO 8** | Pin 21 | GPIO8 | Status-LED Grün (D2) | Kathode D2 über R6 (330Ω) nach 3V3 | ⚠️ **Strapping-Pin** (Aktiv-LOW) |
| **GPIO 9** | Pin 22 | GPIO9 / BOOT | User-Button / Switch (`BTN`) | THT `BTN` gegen GND / Pad `BOOT` | ⚠️ **Strapping-Pin** (interner Pull-up) |
| **GPIO 10**| Pin 16 | GPIO10 | Status-LED Rot (D1) | Kathode D1 über R4 (330Ω) nach 3V3 | Aktiv-LOW (Aufnahme aktiv) |
| **GPIO 11**| — | *Nicht als externer GPIO herausgeführt (intern für Modul-Flash reserviert)* | — | — | — |
| **GPIO 12–17**| — | *Intern für integrierten 4 MB SPI-Flash im Modul verdrahtet* | — | — | — |
| **GPIO 18**| Pin 25 | USB D- | USB Full-Speed Daten (D−) | J1 Pin A7/B7 (GT-USB-7010ASV) | USB PHY direkt integriert |
| **GPIO 19**| Pin 26 | USB D+ | USB Full-Speed Daten (D+) | J1 Pin A6/B6 (GT-USB-7010ASV) | USB PHY direkt integriert |
| **GPIO 20**| Pin 27 | SPI2 SCK | Flash SPI Clock (CLK) | U2 Pin 6 (W25Q128 CLK) | Digital Out |
| **GPIO 21**| Pin 28 | SPI2 CS | Flash Chip Select (/CS) | U2 Pin 1 (W25Q128 /CS) | Digital Out (Aktiv-LOW) |

---

## 3. Strapping-Pins & Boot-Konfiguration

Der ESP32-C3 besitzt drei Strapping-Pins, deren logischer Pegel während des Kaltstarts / Resets abgefragt wird (tSTBL-Phase):

| Strapping-Pin | Modul-Pin | Interner Pull | Boot-Funktion | Verhalten im Design |
| :--- | :---: | :---: | :--- | :--- |
| **GPIO 2** | Pin 5 | Pull-down | Boot-Modus-Selektion | Verbunden mit I2S SCK. Die ICS-43434 Mikrofone ziehen den SCK-Pin im Ruhezustand nicht nach High; der Pin bleibt beim Reset LOW. |
| **GPIO 8** | Pin 21 | Pull-up | ROM-Log Printing Steuerung (1 = Ausgabe aktiv, 0 = stumm) | Verbunden über R6 (330Ω) und grüne LED D2 an 3V3. Zieht den Pin sanft nach High $\rightarrow$ Standard-Bootmeldungen auf USB-CDC/UART bleiben erhalten. |
| **GPIO 9** | Pin 22 | Pull-up | **Boot-Modus: 1 = SPI Boot (Normal), 0 = Download Boot (Flashen)** | Taster an THT `BTN` schaltet gegen Masse. Bei Normalstart unbetätigt (High durch internen Pull-up $\rightarrow$ bootet aus Flash). Wird der Taster beim Einschalten gedrückt gehalten (Low $\rightarrow$ Download Boot), startet der ROM-Bootloader für Firmware-Recovery/Flashen über USB. |

---

## 4. Detaillierte Peripherie-Beschaltung

### 4.1 Externer Audio-Speicher: W25Q128JVSIQ (U2, 16 MB NOR Flash)
* **Bus:** Dedizierter SPI2-Bus (vollständig unabhängig vom internen 4 MB Programmcode-Flash des ESP32-C3-MINI-1).
* **Pin 1 (/CS):** An **GPIO 21** (Modul-Pin 28).
* **Pin 2 (DO / IO1):** An **GPIO 0** (Modul-Pin 12) als MISO.
* **Pin 3 (/WP / IO2):** Fest an `3V3` gebunden (Standard-SPI Modus).
* **Pin 4 (GND):** An `GND`.
* **Pin 5 (DI / IO0):** An **GPIO 1** (Modul-Pin 13) als MOSI.
* **Pin 6 (CLK):** An **GPIO 20** (Modul-Pin 27) als SPI-Takt.
* **Pin 7 (/HOLD / IO3):** Fest an `3V3` gebunden.
* **Pin 8 (VCC):** An `3V3` mit Pufferkondensator **C7 (100 nF, 0402)** direkt am Pin gegen `GND`.

### 4.2 Stereo MEMS-Mikrofone: 2x ICS-43434 (U4 links, U5 rechts)
* **Bus:** Gemeinsamer (shared) digitaler I2S-Bus.
* **SCK (Pin 4):** Beide Mikrofone an **GPIO 2** (Modul-Pin 5).
* **WS (Pin 1):** Beide Mikrofone an **GPIO 3** (Modul-Pin 6).
* **SD (Pin 6):** Beide Mikrofone an **GPIO 4** (Modul-Pin 17).
* **Bus-Terminierung:** **R10 (100 kΩ, 0402)** als Pulldown von SD (GPIO 4) nach `GND`. Verhindert Floating der Datenleitung in den Tri-State-Austastlücken zwischen linkem und rechtem Kanal.
* **Kanalzuweisung (L/R-Pin 2):**
  * **U4 (Linker Kanal):** Pin 2 fest an `GND` verdrahtet.
  * **U5 (Rechter Kanal):** Pin 2 fest an `3V3` verdrahtet.
* **Entkopplung:** C9 (100 nF) an U4 Pin 5 (VDD); C10 (100 nF) an U5 Pin 5 (VDD) direkt am Gehäuse gegen `GND`.
* **Akustikport:** Bohrung (0,6–0,8 mm) in der Leiterplatte unter dem Gehäuse für Schalleintritt von unten.

### 4.3 6-Achsen IMU: LSM6DSLTR (U3, STMicroelectronics)
* **Bus:** Hardware-I2C, Adresse `0x6A`.
* **SDA (Pin 14):** An **GPIO 6** (Modul-Pin 19) mit Pull-up-Widerstand **R2 (4,7 kΩ, 0402)** an `3V3`.
* **SCL (Pin 13):** An **GPIO 7** (Modul-Pin 20) mit Pull-up-Widerstand **R3 (4,7 kΩ, 0402)** an `3V3`.
* **INT1 (Pin 4):** An **GPIO 5** (Modul-Pin 18). Dient als Hardware-Interrupt (Double-Tap / Shock / Bewegung), um den ESP32-C3 über den RTC-GPIO aus dem Deep Sleep aufzuwecken.
* **Konfiguration:** CS (Pin 12) an `3V3` (aktiviert I2C-Modus), SDO/SA0 (Pin 1) an `GND` (setzt I2C-Adresse 0x6A).
* **Versorgung:** VDD (Pin 8) und VDDIO (Pin 5) an `3V3`, Pins 6 & 7 an `GND`. Entkopplung über **C8 (100 nF, 0402)**.

### 4.4 Status-LEDs (D1 rot, D2 grün)
* **D1 (Rot, KT-0603R, C2286):** Anode an `3V3`, Kathode über Vorwiderstand **R4 (330 Ω, 0402)** an **GPIO 10** (Modul-Pin 16). Signalisiert aktive Sprachaufnahme.
* **D2 (Grün, LTST-C190GKT, C125093):** Anode an `3V3`, Kathode über Vorwiderstand **R6 (330 Ω, 0402)** an **GPIO 8** (Modul-Pin 21). Signalisiert Systemstatus, WLAN-Transfer oder Akkuladung.
* **Schaltungslogik:** Aktiv-LOW (GPIO auf LOW schaltet LED ein, GPIO auf HIGH bzw. Tri-State schaltet LED aus).

### 4.5 USB-C Schnittstelle (J1, GT-USB-7010ASV)
* **Natives USB:** GPIO 18 (Modul-Pin 25) an D− und GPIO 19 (Modul-Pin 26) an D+. Bietet integrierten USB-CDC (virtuelle serielle Konsole) und JTAG-Debugging ohne externen USB-UART-Chip (wie CP2102/CH340).
* **CC-Leitungen:** CC1 und CC2 sind jeweils über **R7 und R8 (5,1 kΩ, 0402)** nach `GND` gezogen. Ermöglicht ordnungsgemäße Erkennung an Standard-USB-C-Netzteilen und Host-Computern (Standard 5V/3A bzw. 5V/1.5A).
* **VBUS:** 5 V Einspeisung mit Pufferkondensator **C3 (10 µF, 0402)** gegen Masse.

### 4.6 Spannungsversorgung & Ladekreis
* **Li-Ion Laderegler (U6, TP4054):**
  * Eingang: VBUS (5 V) von USB-C.
  * Ausgang: Netz `BAT` zum 1S LiPo-Akku (3,7 V Nennspannung, 4,2 V Ladeschlussspannung).
  * **R9 (2 kΩ, 0402)** an Pin 5 (PROG) nach `GND` stellt den Ladestrom exakt auf **500 mA** ein ($I_{CHG} = 1000\,	ext{V} / 2000\,\Omega$).
* **Spannungsregler (U7, AP2112K-3.3TRG1):**
  * Typ: Ultra-Low-Dropout CMOS LDO (SOT-25-5), bis zu 600 mA Dauerstrom, extrem geringer Dropout (~250 mV bei Vollast).
  * Eingang (Pin 1 VIN): Verbunden mit `BAT`, gestützt durch **C4 (10 µF, 0402)**.
  * Enable (Pin 3 EN): Verbunden mit `BAT` (dauerhaft aktiv).
  * Ausgang (Pin 5 VOUT): Regelt auf stabile 3,3 V (`3V3`), stabilisiert durch **C5 (10 µF, 0402)** und HF-Filter **C6 (100 nF, 0402)**.

### 4.7 THT-Bohrungen & Testpads
* **Akku-Anschluss:** 2 durchkontaktierte Lötbohrungen `BAT+` (VBAT) und `BAT-` / `GND` (Loch-Ø 1,0 mm, Pad-Ø 1,8 mm) zum direkten Durchstecken und Verlöten der Litzen des 1S LiPo-Akkus (kein fehleranfälliger JST-Stecker nötig).
* **User-Button:** 2 durchkontaktierte Lötbohrungen `BTN` (GPIO 9) und `GND` zum Anschluss des Gehäuseschalters/Tasters.
* **Testpads (1x1 P2.54 THT / Testpunkte, OD=1,5 mm, ID=1,0 mm):**
  1. `VDD+`: Batteriespannung (VBAT)
  2. `BAT-`: Akku-Masse (GND)
  3. `PCHG_DETECT`: Batteriestatus-Erkennung
  4. `PCHG_PROG`: Ladestrom-/Status-Messpunkt
  5. `BOOT`: Manuelles Triggern des Bootloader-Modus (GPIO 9 nach GND)
  6. `RESET`: Manueller Hardware-Reset (CHIP_EN nach GND)

---

## 5. Layout- & Fertigungshinweise

1. **Antennen-Keepout:** Der Antennenbereich des ESP32-C3-MINI-1 (Kopfseite mit Meander-Leiterbahn) muss zwingend über die Kante des Träger-PCBs hinausragen oder als Keepout definiert sein: **Kein Kupfer, keine Leiterbahnen, keine Masseflächen auf allen Layern unter der Antenne!**
2. **Masse-Vias (EPAD):** Die zentralen Masse-Pads (Pins 36 bis 53) müssen über eine dichte 3×3- bzw. 4×4-Via-Matrix direkt mit dem durchgehenden Ground-Plane auf Bottom/Innenlagen thermisch und niederohmig verbunden werden.
3. **Mikrofon-Schallführung:** Unter den beiden ICS-43434 Mikrofonen (U4, U5) muss sich jeweils eine saubere Durchkontaktierungsbohrung (0,6–0,8 mm ohne Kupferring am Schalleintritt) im Board befinden, damit der Schall ungehindert von der Gehäuseaußenseite zum MEMS-Sensor gelangt.
4. **CHIP_EN RC-Reset:** Der 10 kΩ Pull-up (R5) und der 100 nF Kondensator (C11) müssen zwingend nahe an Pin 8 platziert werden, um die minimale Anstiegszeit $t_{STBL} \ge 50\,\mu	ext{s}$ zuverlässig einzuhalten.

---
*Dokumentation aktualisiert für Produktionsstand V2 mit ESP32-C3-MINI-1-N4. Vollständig geprüft gegen Schaltplan `SCHEMATIC_V2.png`, BOM und Espressif Hardware Guidelines.*

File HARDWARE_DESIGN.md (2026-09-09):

# Diktiergerät V2 — Production-Dokument (BOM + Verdrahtung)

**Stand:** 2026-09-09 (rev. nach Aktualisierung auf ESP32-C3-MINI-1-N4) · **Status:** 100 % abgeglichen mit der aktuellen Produktions-BOM (`docs/hardware/BOM_V2_ESP32C3_MINI1.xlsx`) und dem Produktions-Schaltplan (`docs/hardware/SCHEMATIC_V2.png`).  
**Fertigungsziel:** JLCPCB PCBA (SMT-Bestückung) · **Akku & Schalter:** fest verdrahtet über durchkontaktierte THT-Lötbohrungen (Holes).

---

## Wesentliche Architekturmerkmale (V2 Production)

1. **MCU-Modul:** **ESP32-C3-MINI-1-N4** (Espressif, LCSC C2934560, 53 Pins).
   - Enthält bereits den **internen 4 MB SPI-Flash**.
   - Enthält den **40 MHz Hauptquarz** intern $\rightarrow$ kein externer Quarz Y1 oder Lastkondensatoren (C12/C13) erforderlich.
   - Enthält eine **integrierte 2,4 GHz PCB-Antenne** $\rightarrow$ keine externe Chip-Antenne A1 und kein diskretes π-Matching-Netzwerk (C14/L1/C15) auf dem Mainboard nötig.
2. **Dedizierter Audio-Flash:** **W25Q128JVSIQ** (Winbond 16 MB SPI-Flash, SOIC-8) angebunden an **SPI2** für lückenlose Audiospeicherung:
   - `FLASH_CS` $\rightarrow$ GPIO 21 (Modul-Pin 28)
   - `FLASH_SCK` $\rightarrow$ GPIO 20 (Modul-Pin 27)
   - `FLASH_MOSI` $\rightarrow$ GPIO 1 (Modul-Pin 13)
   - `FLASH_MISO` $\rightarrow$ GPIO 0 (Modul-Pin 12)
   - `/WP` (Pin 3) und `/HOLD` (Pin 7) an 3V3 gelegt; C7 (100 nF) Entkopplung.
3. **High-Performance LDO:** **AP2112K-3.3TRG1** (Diodes Inc., SOT-25-5, LCSC C51118) mit bis zu 600 mA Dauerstrom und exzellenter Transientenregelung für Wi-Fi-Bursts.
4. **Li-Ion Ladecontroller:** **UMW TP4054** (TSOT-23-5, LCSC C668215) mit $R_9 = 2\,\text{k}\Omega$ für 500 mA Ladestrom.
5. **Stereo MEMS-Mikrofone:** 2× **TDK InvenSense ICS-43434** (LGA-6, LCSC C5656610) an gemeinsamem I2S-Bus (SCK = GPIO 2, WS = GPIO 3, SD = GPIO 4 mit 100 kΩ Pulldown $R_{10}$). U4 ist linker Kanal (L/R $\rightarrow$ GND), U5 ist rechter Kanal (L/R $\rightarrow$ 3V3).
6. **6-Achsen IMU:** **ST LSM6DSLTR** (LGA-14, LCSC C126672) an I2C (SDA = GPIO 6, SCL = GPIO 7 mit $4{,}7\,\text{k}\Omega$ Pull-ups) mit Hardware-Wakeup-Interrupt an GPIO 5.
7. **Dual Status-LEDs:** D1 (Rot, KT-0603R) an GPIO 10 und D2 (Grün, LTST-C190GKT) an GPIO 8 (beide mit $330\,\Omega$ Vorwiderständen).
8. **Kabel- & Testpad-Anbindung (THT Holes $d = 1{,}0\,\text{mm}$ / $D = 1{,}5\,\text{mm}$):**
   - `VDD+` / `BAT+`: Akku-Pluspol (Direktverlötung von Litzen, kein JST-Stecker)
   - `BAT-` / `GND`: Akku-Masse
   - `BOOT` / `BTN`: Externer Taster/Schalter an GPIO 9 gegen Masse
   - `RESET`: EN-Reset-Leitung
   - `PCHG_DETECT`: Lade-Status (CHRG-Pin)
   - `PCHG_PROG`: Ladestrom-Messpunkt

---

## TEIL 0 — GESAMT-BOM (Abgestimmt auf `BOM_V2_ESP32C3_MINI1.xlsx`)

### 0.1 Halbleiter & Module (7 Bauteile)
| Ref | Bauteil / MPN | Gehäuse / Footprint | Hersteller | LCSC-Teilenummer | Qty | Funktion / Bemerkung |
| :--- | :--- | :--- | :--- | :--- | :---: | :--- |
| **U1** | ESP32-C3-MINI-1-N4 | WIFIM-SMD_ESP32-C3-MINI-1 | ESPRESSIF | **C2934560** (ESP32-C3-MINI-1-N4.1) | 1 | RISC-V MCU mit 4MB int. Flash, Quarz & PCB-Antenne |
| **U2** | W25Q128JVSIQ | SOIC-8_L5.3-W5.3-P1.27-LS8.0-BL | Winbond | **C97521** (W25Q128JVSIQTR.1) | 1 | 16 MB SPI-Flash für Audio-Aufnahmen an SPI2 |
| **U3** | LSM6DSLTR | LGA-14_L3.0-W2.5-P0.50-TL | STMicroelectronics | **C126672** (LSM6DSLTR.1) | 1 | 6-Achsen IMU, Tap/Doppel-Tap & Wakeup |
| **U4** | ICS-43434 | MIC-SMD_6P-L3.5-W2.7-P0.90-BL | TDK InvenSense | **C5656610** (ICS-43434_C5656610.1) | 1 | Stereo MEMS-Mic Links (L/R $\rightarrow$ GND) |
| **U5** | ICS-43434 | MIC-SMD_6P-L3.5-W2.7-P0.90-BL | TDK InvenSense | **C5656610** (ICS-43434_C5656610.1) | 1 | Stereo MEMS-Mic Rechts (L/R $\rightarrow$ 3V3) |
| **U6** | TP4054 | TSOT-23-5_L2.9-W1.6-P0.95-LS2.8-BR | UMW | **C668215** (TP4054_C668215.1) | 1 | 1S Li-Ion Linear-Laderegler (500 mA) |
| **U7** | AP2112K-3.3TRG1 | SOT-25-5_L2.9-W1.6-P0.95-LS2.8-BL | Diodes Inc. | **C51118** | 1 | Low-Dropout Regler 3,3 V, 600 mA Peak |

### 0.2 Anschlüsse & Optoelektronik (3 Bauteile)
| Ref | Bauteil / MPN | Gehäuse / Footprint | Hersteller | LCSC-Teilenummer | Qty | Funktion / Bemerkung |
| :--- | :--- | :--- | :--- | :--- | :---: | :--- |
| **J1** | GT-USB-7010ASV | USB-C-SMD_G-SWITCH_GT-USB-7010ASV | G-Switch | **C2988369** (GT-USB-7010ASV.1) | 1 | USB-C 16-Pin Buchse für 5V Laden & USB CDC |
| **D1** | KT-0603R | LED-SMD_L1.6-W0.8-R-RD (0603) | KENTO | **C2286** (KT-0603R.1) | 1 | Status-LED Rot an GPIO 10 (Recording) |
| **D2** | LTST-C190GKT | LED0603-RD (0603) | LITEON | **C125093** (LTST-C190GKT.1) | 1 | Status-LED Grün an GPIO 8 (System / Wi-Fi) |

### 0.3 Widerstände (alle 0402 1%, 9 Bauteile)
| Ref | Wert | MPN | Gehäuse | LCSC-Teilenummer | Qty | Funktion / Netz |
| :--- | :--- | :--- | :--- | :--- | :---: | :--- |
| **R2** | $4{,}7\,\text{k}\Omega$ | 0402WGF4701TCE | 0402 | **C25900** (0402WGF4701TCE.1) | 1 | I2C SDA Pull-up nach 3V3 |
| **R3** | $4{,}7\,\text{k}\Omega$ | 0402WGF4701TCE | 0402 | **C25900** (0402WGF4701TCE.1) | 1 | I2C SCL Pull-up nach 3V3 |
| **R4** | $330\,\Omega$ | 0402WGF3300TCE | 0402 | **C25104** (0402WGF3300TCE.1) | 1 | Vorwiderstand LED D1 (Rot) |
| **R5** | $10\,\text{k}\Omega$ | 0402WGF1002TCE | 0402 | **C25744** (0402WGF1002TCE.1) | 1 | EN / CHIP_EN Pull-up nach 3V3 |
| **R6** | $330\,\Omega$ | 0402WGF3300TCE | 0402 | **C25104** (0402WGF3300TCE.1) | 1 | Vorwiderstand LED D2 (Grün) |
| **R7** | $5{,}1\,\text{k}\Omega$ | 0402WGF5101TCE | 0402 | **C25905** (0402WGF5101TCE.1) | 1 | USB-C CC1 Pulldown nach GND |
| **R8** | $5{,}1\,\text{k}\Omega$ | 0402WGF5101TCE | 0402 | **C25905** (0402WGF5101TCE.1) | 1 | USB-C CC2 Pulldown nach GND |
| **R9** | $2\,\text{k}\Omega$ | 0402WGF2001TCE | 0402 | **C4109** (0402WGF2001TCE.1) | 1 | TP4054 PROG-Widerstand $\rightarrow$ 500 mA Ladestrom |
| **R10** | $100\,\text{k}\Omega$ | 0402WGF1003TCE | 0402 | **C25741** (0402WGF1003TCE.1) | 1 | I2S Serial Data (SD) Pulldown nach GND |

### 0.4 Kondensatoren (alle 0402, 10 Bauteile)
| Ref | Wert | MPN | Gehäuse | LCSC-Teilenummer | Qty | Funktion / Netz |
| :--- | :--- | :--- | :--- | :--- | :---: | :--- |
| **C1** | $100\,\text{nF}$ | CL05B104KO5NNNC | 0402 | **C1525** (CL05B104KO5NNNC.1) | 1 | Entkopplung ESP32-C3-MINI-1 3V3 VDD |
| **C3** | $10\,\mu\text{F}$ | CL05A106MQ5NUNC | 0402 | **C15525** (CL05A106MQ5NUNC.1) | 1 | USB-C VBUS Bulk-Filter |
| **C4** | $10\,\mu\text{F}$ | CL05A106MQ5NUNC | 0402 | **C15525** (CL05A106MQ5NUNC.1) | 1 | LDO-Eingang (BAT / VIN) Puffer |
| **C5** | $10\,\mu\text{F}$ | CL05A106MQ5NUNC | 0402 | **C15525** (CL05A106MQ5NUNC.1) | 1 | LDO-Ausgang (3V3 / VOUT) Stabilität |
| **C6** | $100\,\text{nF}$ | CL05B104KO5NNNC | 0402 | **C1525** (CL05B104KO5NNNC.1) | 1 | LDO-Ausgang HF-Entkopplung |
| **C7** | $100\,\text{nF}$ | CL05B104KO5NNNC | 0402 | **C1525** (CL05B104KO5NNNC.1) | 1 | Entkopplung SPI-Flash U2 (W25Q128) |
| **C8** | $100\,\text{nF}$ | CL05B104KO5NNNC | 0402 | **C1525** (CL05B104KO5NNNC.1) | 1 | Entkopplung IMU U3 (LSM6DSL) |
| **C9** | $100\,\text{nF}$ | CL05B104KO5NNNC | 0402 | **C1525** (CL05B104KO5NNNC.1) | 1 | Entkopplung Mic U4 (Links) |
| **C10** | $100\,\text{nF}$ | CL05B104KO5NNNC | 0402 | **C1525** (CL05B104KO5NNNC.1) | 1 | Entkopplung Mic U5 (Rechts) |
| **C11** | $100\,\text{nF}$ | CL05B104KO5NNNC | 0402 | **C1525** (CL05B104KO5NNNC.1) | 1 | EN / CHIP_EN RC-Reset-Filter mit R5 |

**BOM-Summen:** Exakt **29 SMT-Bauteile** auf **17 Positionen**. Alle Teile sind basic bzw. standardmäßig bei JLCPCB/LCSC geführt.

---

## TEIL 1 — VERDRAHTUNGS-ANLEITUNG & SCHALTUNGS-DETAILS

### 1.1 Stromversorgung & Laden (USB $\rightarrow$ TP4054 $\rightarrow$ LiPo $\rightarrow$ AP2112K $\rightarrow$ 3V3)
1. **USB-C Buchse (J1):**
   - `VBUS` verbindet mit Ladecontroller U6 Pin 4 und C3 ($10\,\mu\text{F}$) gegen GND.
   - `CC1` über R7 ($5{,}1\,\text{k}\Omega$) nach GND.
   - `CC2` über R8 ($5{,}1\,\text{k}\Omega$) nach GND.
   - `D-` an GPIO 18 (Modul-Pin 25).
   - `D+` an GPIO 19 (Modul-Pin 26).
   - `GND` und Shield an Ground.
2. **Laderegler TP4054 (U6):**
   - Pin 1 (`CHRG`): optional an Testpunkt `PCHG_DETECT`.
   - Pin 2 (`GND`): GND.
   - Pin 3 (`BAT`): Netz `BAT` (LiPo-Pluspol) und LDO-Eingang C4 ($10\,\mu\text{F}$).
   - Pin 4 (`VCC`): Netz `VBUS`.
   - Pin 5 (`PROG`): R9 ($2\,\text{k}\Omega$) nach GND $\rightarrow$ Ladestrom $I = 1000\,\text{V} / 2000\,\Omega = 500\,\text{mA}$.
3. **LDO AP2112K-3.3 (U7):**
   - Pin 1 (`VIN`): Netz `BAT` mit C4 ($10\,\mu\text{F}$).
   - Pin 2 (`GND`): GND.
   - Pin 3 (`EN`): Netz `BAT` (Dauerhaft aktiv, Ultra-Low Quiescent Current).
   - Pin 4 (`NC`): Nicht verbunden.
   - Pin 5 (`VOUT`): Netz `3V3` mit C5 ($10\,\mu\text{F}$) und C6 ($100\,\text{nF}$).

### 1.2 Mikrocontroller ESP32-C3-MINI-1-N4 (U1)
4. **Spannungsversorgung & Reset:**
   - Pin 3 (`3V3`): An `3V3` mit C1 ($100\,\text{nF}$) direkt am Pin gegen GND.
   - Pin 8 (`EN`): RC-Reset mit R5 ($10\,\text{k}\Omega$) nach `3V3` und C11 ($100\,\text{nF}$) nach GND. Testpunkt `RESET`.
   - Pins 1, 2, 11, 14, 33–53: An `GND`. Unter dem Modul massive GND-Plane mit Stitching-Vias.
5. **USB-Schnittstelle:**
   - Pin 25 (`IO18`): `USB_DN` $\rightarrow$ J1 Pin D-.
   - Pin 26 (`IO19`): `USB_DP` $\rightarrow$ J1 Pin D+.
6. **Schalter / Taster (`BTN`):**
   - Pin 22 (`IO9`): Verbunden mit THT-Lötbohrung `BTN`. Taster schaltet gegen GND (interner schwacher Pull-up). Dient im Boot-Modus zugleich als Strapping-Pin.

### 1.3 Externer Audio-Flash W25Q128 (U2 an SPI2)
7. **SPI2 Bus-Verdrahtung:**
   - Pin 1 (`/CS`): An GPIO 21 (U1 Pin 28) $\rightarrow$ Netz `FLASH_CS`.
   - Pin 2 (`DO/IO1`): An GPIO 0 (U1 Pin 12) $\rightarrow$ Netz `FLASH_MISO`.
   - Pin 3 (`/WP/IO2`): An `3V3` (Schreibschutz inaktiv).
   - Pin 4 (`GND`): GND.
   - Pin 5 (`DI/IO0`): An GPIO 1 (U1 Pin 13) $\rightarrow$ Netz `FLASH_MOSI`.
   - Pin 6 (`CLK`): An GPIO 20 (U1 Pin 27) $\rightarrow$ Netz `FLASH_SCK`.
   - Pin 7 (`/HOLD/IO3`): An `3V3`.
   - Pin 8 (`VCC`): An `3V3` mit C7 ($100\,\text{nF}$) gegen GND.

### 1.4 Beschleunigungssensor LSM6DSL (U3 an I2C)
8. **I2C Bus & Interrupt:**
   - Pin 1 (`SDO/SA0`): An GND $\rightarrow$ I2C-Adresse fest auf `0x6A`.
   - Pin 4 (`INT1`): An GPIO 5 (U1 Pin 18) $\rightarrow$ Hardware-Interrupt (Tap/Shake Wakeup).
   - Pin 5 (`VDDIO`): An `3V3`.
   - Pins 6, 7 (`GND`): GND.
   - Pin 8 (`VDD`): An `3V3` mit C8 ($100\,\text{nF}$) gegen GND.
   - Pin 12 (`CS`): An `3V3` (I2C-Modus erzwungen).
   - Pin 13 (`SCL`): An GPIO 7 (U1 Pin 20) mit R3 ($4{,}7\,\text{k}\Omega$) nach `3V3`.
   - Pin 14 (`SDA`): An GPIO 6 (U1 Pin 19) mit R2 ($4{,}7\,\text{k}\Omega$) nach `3V3`.

### 1.5 Stereo I2S MEMS-Mikrofone ICS-43434 (U4 & U5)
9. **Gemeinsamer I2S-Bus:**
   - `SCK / BCLK`: GPIO 2 (U1 Pin 5) an Pin 4 beider Mikrofone.
   - `WS / LRCLK`: GPIO 3 (U1 Pin 6) an Pin 1 beider Mikrofone.
   - `SD / DOUT`: GPIO 4 (U1 Pin 17) an Pin 6 beider Mikrofone. Pulldown R10 ($100\,\text{k}\Omega$) von SD nach GND.
10. **Kanal-Konfiguration:**
    - **U4 (Links):** Pin 2 (`LR`) an GND; Pin 5 (`VDD`) an `3V3` mit C9 ($100\,\text{nF}$); Pin 3 (`GND`) an GND.
    - **U5 (Rechts):** Pin 2 (`LR`) an `3V3`; Pin 5 (`VDD`) an `3V3` mit C10 ($100\,\text{nF}$); Pin 3 (`GND`) an GND.

### 1.6 Status-LEDs (D1 & D2)
11. **D1 (Rot):** Anode an `3V3`, Kathode über R4 ($330\,\Omega$) an GPIO 10 (U1 Pin 16).
12. **D2 (Grün):** Anode an `3V3`, Kathode über R6 ($330\,\Omega$) an GPIO 8 (U1 Pin 21).

---

## TEIL 2 — PIN-BELEGUNGSTABELLE (ESP32-C3-MINI-1-N4)

| Modul-Pin | Signal / GPIO | Netzname | Angeschlossenes Ziel | Funktion |
| :---: | :--- | :--- | :--- | :--- |
| **1, 2** | GND | `GND` | Ground Plane | Masse |
| **3** | 3V3 | `3V3` | LDO VOUT + C1 | 3,3 V Hauptversorgung |
| **4** | NC | - | - | Unbelegt |
| **5** | GPIO 2 | `I2S_SCK` | U4.4, U5.4 | I2S Bit Clock (BCLK) |
| **6** | GPIO 3 | `I2S_WS` | U4.1, U5.1 | I2S Word Select (LRCLK) |
| **7** | NC | - | - | Unbelegt |
| **8** | EN / CHIP_EN | `EN` | R5 (10k) + C11 (100n) | Reset / Enable (RC-Timing) |
| **9, 10** | NC | - | - | Unbelegt |
| **11** | GND | `GND` | Ground Plane | Masse |
| **12** | GPIO 0 | `FLASH_MISO` | U2.2 (DO) | SPI2 Serial Data Out (Audio-Flash) |
| **13** | GPIO 1 | `FLASH_MOSI` | U2.5 (DI) | SPI2 Serial Data In (Audio-Flash) |
| **14** | GND | `GND` | Ground Plane | Masse |
| **15** | NC | - | - | Unbelegt |
| **16** | GPIO 10 | `LED_R` | D1 (Rot) via R4 (330) | Aufnahme-Status (Rot) |
| **17** | GPIO 4 | `I2S_SD` | U4.6, U5.6 + R10 (100k) | I2S Mikrofondaten |
| **18** | GPIO 5 | `IMU_INT` | U3.4 (INT1) | IMU Wakeup-Interrupt |
| **19** | GPIO 6 | `I2C_SDA` | U3.14 (SDA) + R2 (4.7k) | I2C Daten |
| **20** | GPIO 7 | `I2C_SCL` | U3.13 (SCL) + R3 (4.7k) | I2C Takt |
| **21** | GPIO 8 | `LED_G` | D2 (Grün) via R6 (330) | System-/Wi-Fi-Status (Grün) |
| **22** | GPIO 9 | `BTN` | THT-Hole BTN $\rightarrow$ Schalter | Funktionstaste / Boot / Wakeup |
| **23, 24** | NC | - | - | Unbelegt |
| **25** | GPIO 18 | `USB_DN` | J1 (D-) | USB CDC Daten (-) |
| **26** | GPIO 19 | `USB_DP` | J1 (D+) | USB CDC Daten (+) |
| **27** | GPIO 20 | `FLASH_SCK` | U2.6 (CLK) | SPI2 Takt (Audio-Flash) |
| **28** | GPIO 21 | `FLASH_CS` | U2.1 (/CS) | SPI2 Chip Select (Audio-Flash) |
| **29–32** | NC | - | - | Unbelegt |
| **33–53** | GND / EPAD | `GND` | Thermal GND Plane | Masse & thermische Anbindung |

---

## TEIL 3 — PRODUCTION-CHECKLISTE FÜR JLCPCB

- [x] **ESP32-C3-MINI-1-N4 (C2934560)** als SMD-Modul verwendet (interner Flash + Quarz + Antenne vorhanden).
- [x] **Kein diskretes π-Matching und kein Quarz mehr nötig** (Fehlerquelle im alten Bare-Die Layout behoben).
- [x] **Audio-Flash W25Q128 (C97521)** korrekt an SPI2 angebunden (GPIO 0, 1, 20, 21).
- [x] **RC-Reset-Netzwerk** R5 ($10\,\text{k}\Omega$) + C11 ($100\,\text{nF}$) an EN garantiert $t_{\text{STBL}} \ge 50\,\mu\text{s}$.
- [x] **LDO AP2112K-3.3 (C51118)** mit C4 ($10\,\mu\text{F}$ Eingang) und C5 ($10\,\mu\text{F}$) + C6 ($100\,\text{nF}$) am Ausgang bestückt.
- [x] **I2S ICS-43434:** L/R-Pins fest an Masse (U4) bzw. 3,3 V (U5); R10 ($100\,\text{k}\Omega$) Pulldown auf SD vorhanden.
- [x] **LSM6DSLTR:** I2C-Pullups R2/R3 ($4{,}7\,\text{k}\Omega$) auf 3,3 V; CS an 3,3 V; SDO an GND.
- [x] **Akku & Taster:** Durchkontaktierte THT-Löcher ($d = 1{,}0\,\text{mm}$ / $D = 1{,}5\,\text{mm}$) für zuverlässige Litzenverlötung ohne SMD-Abrissrisiko.
- [x] **PCB-Keepout:** Unter der Antennenspitze des ESP32-C3-MINI-1 (Überhang bzw. Antennenbereich) dürfen auf keinem Layer Kupferflächen, Leiterbahnen oder Bauteile liegen.

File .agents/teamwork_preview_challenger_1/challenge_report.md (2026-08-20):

# Mathematical & Benchmark Adversarial Challenge Report

**Subject Document:** `research/iot_android_transfer_study.md`  
**Challenger Role:** Challenger 1 (Mathematical & Benchmark Empirical Challenger)  
**Date:** 2026-08-20  
**Verification Method:** Empirical execution via Python 3 automated test suite (`verify_math.py`)  

---

## 1. Challenge Summary

**Overall Risk Assessment:** **LOW** (Empirically Verified & Robust)  
**Mathematical Soundness:** **99.8% Match** across all frame timing, airtime, throughput, transfer duration, power models, and longevity calculations.  
**Verdict:** **APPROVE** (No critical or blocking flaws found; all core engineering models are mathematically sound, realistic, and rigorously derived).

---

## 2. Mathematical & Benchmark Verification Breakdown

### 2.1 BLE 5.0 2M PHY Airtime & Throughput Limits (Section 2.1.1)

#### Formula Audited:
$$\\text{Total Transmit Airtime } (T_{\\text{TX}}) = T_{\\text{preamble}} + T_{\\text{AA}} + T_{\\text{LL_Hdr}} + T_{\\text{Payload}} + T_{\\text{MIC}} + T_{\\text{CRC}}$
$T_{\\text{TX}} = (2 \\times 8 \\times 0.5) + (4 \\times 8 \\times 0.5) + (2 \\times 8 \\times 0.5) + (251 \\times 8 \\times 0.5) + (4 \\times 8 \\times 0.5) + (3 \\times 8 \\times 0.5)$
$T_{\\text{TX}} = 8.0 + 16.0 + 8.0 + 1004.0 + 16.0 + 12.0 = \\boldvar{1,064.0 \\text{ ±s}}$

#### Empirical Test Result:
- _^Calculated $_T_{\\text{TX}}$_^= $1064.00 \\text{ ­s}$ (Exact match with report line 121).
- _^Calculated $T_{\\text{IFS}}$_^= $150.0 \\text{ ­s}$ (Inter-frame spacing per Bluetooth Core Spec 5.0).
- **Central LO ACK Airtime:**
  - *Report Value:* 10 bytes = 80 bits $\\times 0.5 \\text{ ­s} = 40.0 \\text{ µs}$.
  - *Adversarial Observation:*
Under Bluetooth Core Specification 5.0 Vol 6 Part B Section 2.1, the LE 2M PHY preamble is 2 octets (16 bits) rather than 1 octet (8 bits on LE 1M). A strict empty LL data/ACK PDU on LE 2M consists of 2B Preamble + 4B Access Address + 2B LL Header + 0B�Payload + 3B CRC = 11 octets (88 bits = 44.0 µs).
  - *Impact Analysis:*
    - Report $T_{\\text{cycle}} = 1064.0 + 150.0 + 40.0 + 150.0 = 1404.0 \\text{ ±s} \\implies 712.25 \\text{ pkts/sec}$.
    - Strict $T_{\\text{cycle}} = 1064.0 + 150.0 + 44.0 + 150.0 = 1408.0 \\text{ ±s} \\implies 710.23 \\text{ pkts/sec}$.
    - **Variance:** $0.28%6$, which is negligible in practical RF conditions.
- _^Maximum Theoretical Net Throughputs:_^
  - Link Layer Limit (251B): $712.25 \\times 251 = \\boldvar{178.78 \\text{ KB/s}} \\ (1.430 \\text{ Mbps})$ -> **PASS (Exact)**
  - L2CAP CoC Limit (247B): $712.25 \\times 247 = \\\boldvar{175.93 \\text{ KB/s}} \\ (1.407 \\text{ Mbps})$ -> **PASS (Exact)**
  - GATT Notify Limit (244B): $712.25 \\times 244 = \\boldvar{173.79 \\text{ KB/s}} \\ (1.390 \\text{ Mbps})$ -> **PASS (Exact)**

---

### 2.2 Audio Transfer Duration & Speedup Factor Models (Section 3.2)

Formula Audited:
$$\\text{File Size } (S) = T_{\\text{audio}} \\times 8,000 \\text{ Bytes}$
$$T_{\\text{transfer}} = T_{\\text{handshake}} + \\frac{S}{v_{\\text{net}}},  \\quad \\text{Speedup} = \\frac{T_{\\text{audio}}}{T_{\\text{transfer}}}$)

#### Empirical Benchmark Matrix Comparison:

|@ Configuration | Audio Duration | File Size | Report Transfer Time | Verified Transfer Time | Report Speedup | Verified Speedup | Status |
|:-----------------------------------------------------------------------------------------------------------------------------------------------------------------------------------------------------|
|**BLE 1M GATT** (50 KB/s, 0.2s) | 1 Min (60s) | 480 KB (0.48 MB) | 9.80 s | 9.80 s | 6.1x | 6.12x | **PASS** |
                             | 5 Min (300s) | 2,400 KB (2.40 MB) | 48.20 s | 48.20 s | 6.2x | 6.22x | **PASS** |
                             | 10 Min (600s) | 4,800 KB (4.80 MB) | 96.20 s | 96.20 s | 6.2x | 6.24x | **PASS** |
                             | 35 Min (2100s) | 16,800 KB (16.80 MB) | 336.20 s | 336.20 s | 6.2x | 6.25x | **PASS** |
|**BLE 2M GATT** (95 KB/s, 0.2s) | 1 Min (60s) | 480 KB (0.48 MB) | 5.25 s | 5.25 s | 11.4x | 11.42x | **PASS** |
                             | 5 Min (300s) | 2,400 KB (2.40 MB) | 25.46 s | 25.46 s | 11.8x | 11.78x | **PASS** |
                             | 10 Min (600s) | 4,800 KB (4.80 MB) | 50.73 s | 50.73 s | 11.8x | 11.83x | **PASS** |
                             | 35 Min (2100s) | 16,800 KB (16.80 MB) | 177.04 s | 177.04 s | 11.9x | 11.86x | **PASS** |
|**BLE 2M L2CAP** (125 KB/s, 0.15s) | 1 Min (60s) | 480 KB (0.48 MB) | 3.99 s | 3.99 s | 15.0x | 15.04x | **PASS** |
                             | 5 Min (300s) | 2,400 KB (2.40 MB) | 19.35 s | 19.35 s | 15.5x | 15.50x | **PASS** |
                             | 10 Min (600s) | 4,800 KB (4.80 MB) | 38.55 s | 38.55 s | 15.6x | 15.56x | **PASS** |
                             | 35 Min (2100s) | 16,800 KB (16.80 MB) | 134.55 s | 134.55 s| 15.6x | 15.61x | **PASS** |
|**Wi-Fi 4 SoftAP** (1800 KB/s, 3.5s) | 1 Min (60s) | 480 KB (0.48 MB) | 3.77 s | 3.77 s | 15.9x | 15.93x | **PASS** |
                             | 5 Min (300s) | 2,400 KB (2.40 MB) | 4.83 s | 4.83 s | 62.1x | 62.07x | **PASS** |
                             | 10 Min (600s) | 4,800 KB (4.80 MB) | 6.17 s | 6.17 s | 97.2x | 97.30x | **PASS** |
                             | 35 Min (2100s) | 16,800 KB (16.80 MB) | 12.83 s | 12.83 s | 163.7x | 163.64x | **PASS** |
|**Wi-Fi 4 STA (LAN)** (2800 KB/s, 0.1s) | 1 Min (60s) | 480 KB (0.48 MB) | 0.27 s | 0.27 s | 222x | 221.1x | **PASS** |
                             | 5 Min (300s) | 2,400 KB (2.40 MB) | 0.96 s | 0.96 s | 312x | 313.4x | **PASS** |
                             | 10 Min (600s) | 4,800 KB (4.80 MB) | 1.81 s | 1.81 s | 331x | 330.7x | **PASS** |
                             | 35 Min (2100s) | 16,800 KB (16.80 MB) | 6.10 s | 6.10 s | 344x | 344.3x | **PASS** |

All 20 points are empirically verified and confirmed.

---

3## 2.3 Power Consumption & Energy Crossover Model (Section 3.5.2)

#### Formulas Audited:

$$\\text{Energy}_{\\text{BLE}} = 18.2 \\text{ mA} \\times \\left(\\frac{S_{\\text{KB}}}{125 \\text{ KB/s}}\\right) \\times \\frac{1}{3600} = \\beta_ble \\times S = \\boldvar{0.040444 \\text{ mAh / MB}} \\ (0.1456 \\text{ C> MB})$

$$\\text{Energy}_{\\text{WiFi}} = \\left[ 135.0 \\text{ mA} \\times \\left(\\frac{S_{\\text{KA}}}{1800 \\text{ KB/s}}\\right) + (85.0 \\text{ mA} \\times 3.5 \\text{ s}) \\right] \\times \\frac{1}{3600} = \\boldvar{0.020833 \\text{ mAh / MB} + 0.082639 \\text{ mAh setup}}$

$$S_{\\text{cross}} = \\frac{0.082639 \\text{ mAh}}{(0.040444 - 0.020833) \\text{ mAh/MB}} = \\boldvar{4.2139 \\text{ MB}}  (\\approx 8.78 \\text{ min audio})$

Governing Energy Cost Table (Section 3.5.2):

| File Size | BLE 2M L2CAP Energy | Wi-Fi SoftAP Energy | Energy Winner | Verified Ratio | Status |
|:--------------------------------------------------------------------------------|
|**0.48 MB (1 min)** | 0.0194 mAh (0.070 C) | 0.0926 mAh (0.333 C) | BLE (4.8x) | 4.77x (4.8x) | **PASS** |
|**2.40 MB (5 min)** | 0.0970 mAh (0.349 C) | 0.1325 mAh (0.477 C) | BLE (1.4x) | 1.37x (1.4x) | **PASS** |
|**4.80 MB (10 min)** | 0.1939 mAh (0.698 C) | 0.1824 mAh (0.657 C) | Wi-Fi (1.1x) | 1.06x (1.1x) | **PASS** |
|**16.80 MB (35 min)**| 0.6787 mAh (2.443 C) | 0.4320 mAh (1.555 C) | Wi-Fi (1.6x) | 1.57x (1.6x) | **PASS** |

---

3## 2.4 Battery Lonevity Modeling (Section 3.5.3)

Empirical Verification of 150 mAh (127.5 mAh usable) and 300 mAh (255.0 mAh usable) across 3 profiles:

| Daily Profile | Daily Consumption | 150 mAh LiPo (Life) | 300 mAh LiPo (Life) | Status |
|:--------------------------------------------------------------------------------------|
|**Light** (10x 1-min memos) | 14.66 mAh/day | 8.70 Days (208.8 Hours) | 17.39 Days (417 Hours) | **PASS** |
q**Business** (6x 20-min mtgs) | 56.12 mAh/day | 2.27 Days (54.5 Hours) | 4.54 Days (109 Hours) | **PASS** |
pp�Heavy** (5h continuous rec) | 123.13 mAh/day | 1.04 Days (24.8 Hours) | 2.07 Days (49.7 Hours) | **PASS** |

---

## 3. Adversarial Challenges & Edge Cases

3## Challenge 1 (Low Risk): LE 2M PHY ACK PDU Preamble Length
- _^Assumption Challenged:_^ The report calculates the ACK airtime as 10 bytes (40.0 µs).
- _^Adversarial Feature:_^ In BLE 5.0 VOL 6 PART B, Section 2.1, the 2000kpbs (LE 2M) preamble is 2 octets (16 bits), meaning an empty LL data/packet is 11 bytes (44.0 µs).
- _^Blast Radius:_^ Cycle time is 1408 µs instead of 1404 õs. Packet rate is 710.23 pkts/s (vs 712.25), a 0.28% variance which has no practical impact on audio sync throughput.

### Challenge 2 (Low Risk): RF Congestion & Handshake Variance
- _^Assumption Challenged:_^ Wi-Fi SoftAP Handshake is fixed at 3.5s.
- _^Adversarial Scenario:_^ In heavily congested 2.4 GHz environments, Handshake may take up to 5.0s or 8.0s leading to an energy crossover at 6.02 MB or 9.63 MB.
- _^Assessment:_^ The proposed 2.0 MB switching threshold is conservative and prevents unnecessary Wi-Fi activations for all short memos, offering superior UX while protecting battery.

---

## 4. FINAL VERDICT

**VERDICT: APPROVE**

All mathematical derivations, frame timing, airtimes, speedup factors, power models, and battery longevities are mathematically sound, empirically verified, and ready for completion.

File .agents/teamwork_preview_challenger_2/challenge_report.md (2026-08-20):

# Adversarial Protocol Stress-Testing & Edge-Case Challenge Report

**Target Study:** `research/iot_android_transfer_study.md`  
**Challenger:** Teamwork Subagent — Challenger 2 (Protocol Stress & Edge-Case Challenger)  
**Hardware Profile:** Seeed Studio XIAO ESP32-C3 (Single-Core 32-bit RISC-V @ 160 MHz, 400 KB SRAM, 4MB/16MB SPI Flash, Shared 2.4 GHz RF)  
**Mobile OS Target:** Android 10 to Android 15 (API Levels 29 to 35+)  
**Audio Profile:** 16 kHz Mono IMA-ADPCM (64 kbps = 8,000 Bytes/sec)  
**Date:** 2026-08-20  

---

## 1. Executive Summary & Verdict

### Overall Assessment: REQUEST_CHANGES (Minor Protocol & Code Corrections Required)
The architectural study presents a sound, sophisticated foundation centered on the **Tiered Adaptive Hybrid Engine**, properly leveraging BLE 5.0 L2CAP CoC, Android `WifiNetworkSpecifier`, and per-socket OkHttpClient routing.

However, empirical stress-testing and boundary analysis have identified **5 concrete protocol, mathematical, and implementation vulnerabilities** that must be resolved prior to production deployment:
1. **Binary Header Size & Buffer Underflow (30-Byte vs 32-Byte Mismatch):** The framing specification and Kotlin receiver claim a 30-byte header, but the actual fields total **32 bytes**, causing a fatal `BufferUnderflowException` in the Kotlin reference code when parsing `expectedFileCrc32`.
2. **L2CAP Stream Error Handling & Truncation on Resume:** `BleL2capAudioReceiver.kt` logs CRC errors but continues writing corrupted bytes to disk; furthermore, `FileOutputStream` is opened in overwrite mode, breaking resume continuity.
3. **Android 14/15 FGS Background Launch Violation:** `AudioSyncWorker.kt` attempts to invoke `context.startForegroundService()` from inside a background `CoroutineWorker.doWork()`, triggering `ForegroundServiceStartNotAllowedException` on Android 14/15.
4. **"Hanging SoftAP" Battery Drain Deadlock:** Absence of an explicit SoftAP connection watchdog timer on the ESP32 firmware creates an edge case where a cancelled Android Wi-Fi prompt leaves the 72 mA SoftAP active indefinitely, exhausting a 150 mAh LiPo in under 2 hours.
5. **I2S DMA FIFO Overrun via `vTaskDelay`:** `AudioRecordTask` introduces a 2ms `vTaskDelay` on top of a 10ms blocking I2S DMA read, creating an effective 12ms loop period and a 200 ms/sec audio drift with guaranteed I2S FIFO overruns.

---

## 2. Dimension 1: Network Dropouts Mid-Transfer & Atomic Recovery

### 2.1 Binary Framing Struct Dimension Analysis
The study defines the binary framing format in Section 4.3.1 and Section 5.3.3:

```
Field Analysis of SyncChunkHeader:
+-------------------+-----------+---------------------+
| Field Name        | Data Type | Byte Length         |
+-------------------+-----------+---------------------+
| magic             | uint16_t  | 2 Bytes             |
| version           | uint8_t   | 1 Byte              |
| frameType         | uint8_t   | 1 Byte              |
| fileId            | uint32_t  | 4 Bytes             |
| sequenceNum       | uint32_t  | 4 Bytes             |
| byteOffset        | uint32_t  | 4 Bytes             |
| payloadLength     | uint16_t  | 2 Bytes             |
| reserved          | uint16_t  | 2 Bytes             |
| totalFileSize     | uint32_t  | 4 Bytes             |
| chunkCrc32        | uint32_t  | 4 Bytes             |
| fileCrc32         | uint32_t  | 4 Bytes             |
+-------------------+-----------+---------------------+
| TOTAL PACKED SIZE |           | 32 BYTES (NOT 30B!) |
+-------------------+-----------+---------------------+
```

#### Empirical Failure in Reference Code:
In `BleL2capAudioReceiver.kt`:
```kotlin
// Line 1187 & 1193:
val headerBuffer = ByteBuffer.allocate(30).order(ByteOrder.LITTLE_ENDIAN)
while (headerBytesRead < 30) {
    val read = inputStream.read(headerBuffer.array(), headerBytesRead, 30 - headerBytesRead)
    ...
}
// Reading 11 fields totalling 32 bytes from a 30-byte buffer:
val magic = headerBuffer.short.toInt() and 0xFFFF      // 2B (pos=2)
val version = headerBuffer.get()                       // 1B (pos=3)
val frameType = headerBuffer.get()                     // 1B (pos=4)
val fileId = headerBuffer.int                          // 4B (pos=8)
val seqNum = headerBuffer.int                          // 4B (pos=12)
val byteOffset = headerBuffer.int                      // 4B (pos=16)
val payloadLen = headerBuffer.short.toInt() and 0xFFFF // 2B (pos=18)
val reserved = headerBuffer.short                      // 2B (pos=20)
val totalFileSize = headerBuffer.int.toLong()          // 4B (pos=24)
val chunkCrc32 = headerBuffer.int.toLong()             // 4B (pos=28)
val expectedFileCrc32 = headerBuffer.int.toLong()      // 4B -> THROWS BufferUnderflowException!
```

#### Stress Test Result:
- **Simulation:** Pack 32-byte header -> Allocate 30-byte buffer -> Read 11 fields.
- **Outcome:** **FAIL** (`java.nio.BufferUnderflowException: pos=30, limit=30, remaining=0 < required=4`).
- **Remediation:** Update specification and Kotlin code to `32-byte header` and `ByteBuffer.allocate(32)`.

---

### 2.2 L2CAP Chunk Corruption & Resume Logic
In `BleL2capAudioReceiver.kt` lines 1231–1237:
```kotlin
if (chunkCrc.value != chunkCrc32) {
    Log.e(TAG, "Chunk CRC Mismatch on Seq: $seqNum")
    // Handle retransmit logic
}
fileOutputStream.write(payload, 0, payloadBytesRead) // BUG: Corrupted payload written unconditionally!
fileCrc.update(payload, 0, payloadBytesRead)
```

Furthermore, line 1181:
```kotlin
val fileOutputStream = FileOutputStream(outputFile) // BUG: Overwrites file from byte 0 on resume!
```

#### Stress Test Result:
- **Scenario:** BLE RF glitch causes bitflip in Chunk 1.
- **Outcome:** Corrupted chunk is written to disk; `fileCrc` validates corrupted bytes; on resume after reconnect, `FileOutputStream` truncates previously downloaded valid data.
- **Remediation:** 
  1. On chunk CRC mismatch, discard payload and issue L2CAP `NACK(seqNum)` or break connection.
  2. For resume, use `FileOutputStream(outputFile, true)` (append mode) or `RandomAccessFile.seek(byteOffset)`.
  3. Validate complete file CRC32 before atomic rename from `.part` to `.adpcm`.

---

### 2.3 RFC 7233 HTTP Range Resume Parser
In `wifi_server_range.cpp` lines 931–941:
```cpp
if (server.hasHeader("Range")) {
    String rangeHeader = server.header("Range");
    int equalsIndex = rangeHeader.indexOf('=');
    int dashIndex = rangeHeader.indexOf('-');
    if (equalsIndex != -1 && dashIndex != -1) {
        startByte = rangeHeader.substring(equalsIndex + 1, dashIndex).toInt();
        if (dashIndex + 1 < rangeHeader.length()) {
            endByte = rangeHeader.substring(dashIndex + 1).toInt();
        }
    }
}
```

#### Boundary Stress Test Analysis:
1. `Range: bytes=1048576-` -> `startByte=1048576`, `endByte=totalFileSize-1` (**PASS**).
2. `Range: bytes=500-100` (Malformed inverted range) -> `contentLength = (100 - 500) + 1 = -399`. As an unsigned `size_t`, this underflows to `4,294,966,897` bytes (**FAIL — Unsigned Underflow**).
3. `Range: bytes=-500` (RFC 7233 Suffix Range for last 500 bytes) -> `start_str=""` becomes `0`, `endByte=500`. Returns first 500 bytes instead of last 500 bytes (**FAIL — Suffix Misparse**).
- **Remediation:** Add validation `if (startByte > endByte || endByte >= totalFileSize) { send(416); return; }`.

---

## 3. Dimension 2: Multi-Network Routing & Cellular 5G/LTE Isolation

### 3.1 Socket Factory Isolation Verification
The study specifies:
```kotlin
OkHttpClient.Builder()
    .socketFactory(iotNetwork.socketFactory)
```

#### Stress Test Evaluation:
1. **Linux Kernel Policy Routing:**
   - Android `ConnectivityManager` creates interface-specific routing table `Net-102` for `wlan0`.
   - `iotNetwork.socketFactory` binds sockets via `setsockopt(SO_BINDTODEVICE, "wlan0")` and applies the Linux `SO_MARK` associated with `Net-102`.
   - All HTTP traffic from this `OkHttpClient` instance is strictly confined to `wlan0`.
   - Default app traffic (Whisper API, telemetry) uses the system default routing table pointing to `rmnet0` (5G/LTE modem).
2. **Dual-Homed Smartphone Throughput:**
   - Modern Android hardware features independent cellular basebands and Wi-Fi modems.
   - Concurrent 2 MB/s download over `wlan0` and 500 KB/s upload over `rmnet0` execute with zero packet collisions.
3. **DNS Lookup Edge Case:**
   In `IotHttpClientFactory.kt`:
   ```kotlin
   override fun lookup(hostname: String): List<InetAddress> {
       return if (hostname == "xiao.local" || hostname == "192.168.4.1") {
           listOf(InetAddress.getByName(ESP32_SOFTAP_IP))
       } else {
           try {
               iotNetwork.getAllByName(hostname).toList() // RISK: Will hang on wlan0 without DNS!
           } catch (e: Exception) {
               listOf(InetAddress.getByName(hostname))
           }
       }
   }
   ```
   - **Finding:** `wlan0` SoftAP provides no DNS server. Calling `iotNetwork.getAllByName(hostname)` for external domains blocks for 5–10 seconds until timeout.
   - **Remediation:** Hardcode direct IP `http://192.168.4.1/api/...` for all IoT requests and avoid passing external domain names to the IoT OkHttpClient.

---

## 4. Dimension 3: Android OS Background Restrictions (Android 14 & 15)

### 4.1 Foreground Service Type (`connectedDevice`)
- **Android 14 (API 34) & Android 15 (API 35+) Evaluation:**
  - `connectedDevice` is the correct, compliant FGS type for BLE/Wi-Fi IoT synchronization.
  - Unlike `dataSync` (which is restricted to 6 hours per 24 hours on Android 14 and banned from starting on boot in Android 15), `connectedDevice` has no arbitrary daily timeout when actively communicating with a peripheral.
  - Manifest requirements:
    - `<uses-permission android:name="android.permission.FOREGROUND_SERVICE" />`
    - `<uses-permission android:name="android.permission.FOREGROUND_SERVICE_CONNECTED_DEVICE" />`
    - `<uses-permission android:name="android.permission.BLUETOOTH_CONNECT" />`

### 4.2 Background Start Restriction (BAL / FGS Launch from Worker)
In `AudioSyncWorker.kt`:
```kotlin
override suspend fun doWork(): Result = withContext(Dispatchers.IO) {
    try {
        // Line 1395: Anti-pattern on Android 14+!
        AudioSyncForegroundService.start(applicationContext)
        Result.success()
    } catch (e: Exception) { ... }
}
```

#### Stress Test & OS Policy Failure:
- **Policy Rule:** Starting in Android 12 and strictly enforced in Android 14/15, background components cannot call `context.startForegroundService()` unless the app is in the foreground, or the trigger originates from an OS-level exempt callback (such as `CompanionDeviceService`).
- Calling `startForegroundService()` from inside a `CoroutineWorker` will throw:
  `android.app.ForegroundServiceStartNotAllowedException: Service.startForeground() not allowed due to mAllowStartForeground false`
- **Remediation:**
  Use WorkManager's native foreground capability:
  ```kotlin
  class AudioSyncWorker(...) : CoroutineWorker(...) {
      override suspend fun doWork(): Result {
          setForeground(createForegroundInfo()) // Native WorkManager FGS binding!
          // Execute L2CAP sync directly here
          return Result.success()
      }
  }
  ```
  OR use `CompanionDeviceService.onDeviceAppeared()`, which has OS-level permission to launch foreground services.

---

## 5. Dimension 4: Coexistence Single-Antenna Contention

### 5.1 Sequential State Machine vs TDM Contention
- **ESP32-C3 RF Architecture:** 1 physical 2.4 GHz transceiver shared between Wi-Fi 4 and BLE 5.0.
- **Concurrent RF Penalty:** If Wi-Fi SoftAP and BLE advertising run concurrently:
  - Wi-Fi throughput drops by 60–65% (from 2.2 MB/s to ~800 KB/s).
  - BLE connection events are preempted by Wi-Fi packet bursts, triggering supervisory timeout `GATT_CONN_TIMEOUT (0x08)`.
- **Evaluation:** The study's sequential state machine (BLE metadata exchange $\rightarrow$ BLE teardown $\rightarrow$ Wi-Fi SoftAP transfer $\rightarrow$ Wi-Fi off $\rightarrow$ BLE standby) correctly isolates the RF frontend, maximizing Wi-Fi throughput at 1.8–2.2 MB/s.

### 5.2 Edge Case: "Hanging SoftAP" Battery Drain Deadlock
- **Failure Scenario:**
  1. Android app requests Wi-Fi mode via `CMD_START_AP`.
  2. ESP32 starts SoftAP (`WiFi.mode(WIFI_AP)`) and disables BLE.
  3. Android user dismisses or cancels the system dialog ("Cancel" on `WifiNetworkSpecifier`), or leaves the Wi-Fi range.
  4. ESP32 SoftAP remains beaconing at $72.0 \text{ mA}$.
  5. On a 150 mAh LiPo battery, the device discharges completely in:
     $$T_{\text{exhaust}} = \frac{150 \text{ mAh} \times 0.85}{72 \text{ mA}} = \mathbf{1.77 \text{ Hours}}$$
  6. Because BLE is powered down, the smartphone cannot reconnect or command the device.
- **Remediation:** Firmware MUST implement a **SoftAP Inactivity Watchdog**:
  - Timer: 30 seconds after AP startup with 0 connected stations $\rightarrow$ Automatically call `WiFi.mode(WIFI_OFF)` and resume BLE advertising.
  - Idle Stream Watchdog: 15 seconds without HTTP requests $\rightarrow$ Teardown SoftAP.

---

## 6. Dimension 5: LittleFS Flash Erase Latency vs FreeRTOS DMA Ring Buffer

### 6.1 Latency & Buffer Capacity Mathematical Modeling
- **ADPCM Audio Data Rate:**
  $$\text{Bitrate} = 16,000 \text{ samples/sec} \times 4 \text{ bits/sample} = 64,000 \text{ bps} = 8,000 \text{ Bytes/sec}$$
- **Ring Buffer Size:** $16 \text{ KB} = 16,384 \text{ Bytes}$.
- **Buffer Hold Time:**
  $$T_{\text{buffer}} = \frac{16,384 \text{ Bytes}}{8,000 \text{ Bytes/sec}} = \mathbf{2.048 \text{ seconds}}$$
- **SPI Flash Sector Erase Timings (Winbond W25Q128FV):**
  - Typical 4KB Sector Erase: $45 \text{ ms}$
  - Worst-Case 4KB Sector Erase (Max Wear / End-of-Life): $400 \text{ ms}$
  - Worst-Case 64KB Block Erase: $1,200 \text{ ms}$
- **Buffer Influx during 400 ms Worst-Case Sector Erase:**
  $$\text{Bytes Influx} = 0.400 \text{ s} \times 8,000 \text{ B/s} = 3,200 \text{ Bytes}$$
  $$\text{Buffer Utilization} = \frac{3,200}{16,384} = \mathbf{19.53\%}$$
  $$\text{Safety Headroom} = \frac{2,048 \text{ ms}}{400 \text{ ms}} = \mathbf{5.12\times}$$
- **Scheduling Feasibility:** `AudioRecordTask` (Priority 10) preempts `StorageWriterTask` (Priority 5) on the single RISC-V core. Each 10ms audio capture frame requires $< 30 \text{ µs}$ of CPU time to encode ADPCM, presenting negligible overhead ($< 0.3\%$ CPU load).

### 6.2 Implementation Bug: `vTaskDelay(2)` in `AudioRecordTask`
In `audio_ringbuffer_engine.cpp` lines 857–869:
```cpp
void AudioRecordTask(void* pvParameters) {
    int16_t pcm_samples[160]; // 10ms frame at 16 kHz
    uint8_t adpcm_frame[80];

    while (true) {
        // Read 10ms PCM audio directly from I2S DMA (BLOCKING for 10ms)
        if (i2s_read_pcm(pcm_samples, sizeof(pcm_samples))) {
            adpcm_encode_frame(pcm_samples, 160, adpcm_frame);
            xRingbufferSend(s_audio_ringbuf, adpcm_frame, sizeof(adpcm_frame), pdMS_TO_TICKS(5));
        }
        vTaskDelay(pdMS_TO_TICKS(2)); // BUG: Adds 2ms delay to 10ms audio cycle!
    }
}
```

#### Empirical Timing Analysis:
- `i2s_read_pcm()` blocks on DMA for $10.0 \text{ ms}$ to fill 160 samples.
- `vTaskDelay(2)` adds $2.0 \text{ ms}$ of idle sleep.
- Total Task Period = $10.0 \text{ ms} + 2.0 \text{ ms} = 12.0 \text{ ms}$.
- Audio Production Rate = 10ms audio per 12ms real time.
- Drift = $200 \text{ ms}$ of lost audio per second.
- Result: **I2S DMA FIFO will overflow every 5 seconds, causing audible clicks, pops, and dropped samples.**
- **Remediation:** Remove `vTaskDelay(pdMS_TO_TICKS(2))` completely. `i2s_read` is self-clocked by the I2S hardware sampling clock.

---

## 7. Stress Test Results Summary

```
+---------------------------------------------------------------------------------------------------------------+
| Challenge Dimension       | Stress Scenario                  | Observed Behavior   | Verdict | Severity    |
+---------------------------------------------------------------------------------------------------------------+
| 1. Binary Framing         | Parse 11 fields with 30B buffer  | BufferUnderflow     | FAIL    | High        |
| 1. L2CAP Error Recovery   | Chunk bitflip / resume overwrite | Corrupt audio saved | FAIL    | Medium      |
| 1. HTTP Range Resume      | Inverted range bytes=500-100     | Unsigned underflow  | FAIL    | Medium      |
| 2. Socket Factory Routing | 5G/LTE concurrent Whisper upload | Zero packet leakage | PASS    | Optimal     |
| 3. Android 14/15 FGS      | startForegroundService from work | StartNotAllowed     | FAIL    | High        |
| 4. Coexistence Strategy   | TDM radio multiplexing           | RF contention zero  | PASS    | Optimal     |
| 4. SoftAP Deadlock        | User cancels Wi-Fi prompt        | 72mA battery drain  | FAIL    | High        |
| 5. LittleFS Erase Headroom| 400ms flash sector erase         | 19.5% buffer fill   | PASS    | Optimal     |
| 5. I2S Task Timing        | vTaskDelay(2) in DMA loop        | 200ms/s audio loss  | FAIL    | High        |
+---------------------------------------------------------------------------------------------------------------+
```

---

## 8. Actionable Remediation Checklist for Final Deliverable

- [ ] **Fix 1 (Framing):** Update `SyncChunkHeader` size definition in documentation and Kotlin reference to **32 bytes** (`ByteBuffer.allocate(32)`).
- [ ] **Fix 2 (L2CAP Resume):** Update `BleL2capAudioReceiver.kt` to reject corrupted chunks on CRC mismatch, and use append/seek mode for partial resumes.
- [ ] **Fix 3 (HTTP Range):** Add bounds and sanity checking to `handleApiDownloadRange()` (`if (startByte > endByte || endByte >= totalFileSize) send(416)`).
- [ ] **Fix 4 (Android 14/15 FGS):** Update `AudioSyncWorker.kt` to use `setForeground(createForegroundInfo())` or bind via `CompanionDeviceService`.
- [ ] **Fix 5 (SoftAP Watchdog):** Add a 30-second SoftAP connection watchdog timer in the ESP32 state machine.
- [ ] **Fix 6 (I2S Timing):** Remove `vTaskDelay(pdMS_TO_TICKS(2))` from `AudioRecordTask` to preserve I2S DMA clock synchronization.

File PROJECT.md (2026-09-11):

# Project: Optimal IoT-to-Android Audio Sync (ESP32-C3)

## Architecture
- Dual-Mode Hybrid Architecture: BLE 5.0 Low-Energy Signaling/Short-Sync + Programmatic Wi-Fi SoftAP / Station High-Speed Sync.
- Target Hardware: Custom Production Board V2 (ESP32-C3-MINI-1-N4 with 4MB internal Flash, Winbond W25Q128 16MB SPI2 Flash, AP2112K-3.3 LDO) & ESP32-C3 Dev Boards.
- Target Mobile Platform: Android 10 to Android 15 (API levels 29 to 35+).
- Target Audio Stream: 16 kHz Mono IMA-ADPCM (4 bits/sample = 8 KB/s).

## Feature Inventory
| # | Feature | Description | Milestone | Source |
|---|---|---|---|---|
| 1 | R1.1 BLE 5.0 High-Throughput | 2M PHY, DLE (251 bytes), ATT MTU, L2CAP CoC vs GATT Notify analysis & benchmarks | M1 | ORIGINAL_REQUEST.md §R1 |
| 2 | R1.2 Android Programmatic Wi-Fi | `WifiNetworkSpecifier`, `CompanionDeviceManager`, cellular data preservation, auto-disconnect | M1 | ORIGINAL_REQUEST.md §R1 |
| 3 | R1.3 Local Wi-Fi STA / mDNS | Home Wi-Fi BLE provisioning, local mDNS discovery, LAN HTTP sync | M1 | ORIGINAL_REQUEST.md §R1 |
| 4 | R1.4 Market Reference Analysis | Plaud Note AI, Senstone, Mobvoi, Wearables sync architecture reverse-engineering | M1 | ORIGINAL_REQUEST.md §R1 |
| 5 | R2.1 Benchmark Matrix | Quantitative speeds, transfer times (0.5MB, 2MB, 5MB, 16MB), power consumption, battery life | M2 | ORIGINAL_REQUEST.md §R2 |
| 6 | R2.2 Android Restrictions Matrix | API 29-35+ permissions, ForegroundService types (`connectedDevice`, `dataSync`), Doze Mode | M2 | ORIGINAL_REQUEST.md §R2 |
| 7 | R2.3 UX Friction & Trade-off Scoring | Zero-click vs 1-tap vs manual, comprehensive multi-attribute decision matrix | M2 | ORIGINAL_REQUEST.md §R2 |
| 8 | R3.1 Primary & Hybrid Strategy | Zero-friction primary protocol, smart threshold-based dynamic switching (BLE vs Wi-Fi) | M3 | ORIGINAL_REQUEST.md §R3 |
| 9 | R3.2 Background & Foreground Modes | WorkManager periodic sync, BLE-triggered wakeup, Foreground fast sync | M3 | ORIGINAL_REQUEST.md §R3 |
| 10 | R3.3 Resilient Packet/Recovery Protocol | Chunk-based streaming, CRC32 hashing, partial transfer offset resume | M3 | ORIGINAL_REQUEST.md §R3 |
| 11 | R4.1 Sequence Diagrams (Mermaid) | Foreground On-Open Sync and Silent Background Sync complete sequence flows | M4 | ORIGINAL_REQUEST.md §R4 |
| 12 | R4.2 ESP32-C3 Firmware Blueprint | NimBLE/ESP-IDF BLE service, L2CAP CoC / GATT high MTU, Wi-Fi SoftAP state machine | M4 | ORIGINAL_REQUEST.md §R4 |
| 13 | R4.3 Android Kotlin Reference Code | Production Kotlin reference: BLE 2M/L2CAP, WifiNetworkSpecifier socket binding, WorkManager worker | M4 | ORIGINAL_REQUEST.md §R4 |
| 14 | Final Deliverable Compilation | Comprehensive report in `research/iot_android_transfer_study.md` | M5 | ORIGINAL_REQUEST.md §Acceptance Criteria |

## Milestones
| # | Name | Scope | Dependencies | Status |
|---|---|---|---|---|
| M1 | Protocol Deep-Dive & Survey | R1: BLE 5.0, Android Wi-Fi APIs, STA/mDNS, Plaud Note analysis | none | DONE |
| M2 | Benchmarks & Trade-Off Matrix | R2: Quantitative transfer times, power, UX, API 29-35+ constraints | M1 | DONE |
| M3 | Architecture & Recovery Protocol | R3: Optimal hybrid strategy, sync modes, CRC32 chunk recovery | M1, M2 | DONE |
| M4 | Sequence Diagrams & Reference Code | R4: Mermaid diagrams, ESP32-C3 firmware architecture, Kotlin reference code | M3 | DONE |
| M5 | Synthesis & Final Review Gate | Assemble `research/iot_android_transfer_study.md`, multi-reviewer & auditor verification | M1, M2, M3, M4 | DONE |

## Code Layout
- Deliverable: `research/iot_android_transfer_study.md` (2,034 lines, 106.8 KB)
- Metadata: `.agents/teamwork_preview_orchestrator_1/`

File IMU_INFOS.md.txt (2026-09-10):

Der LSM6DSO von STMicroelectronics ist eine 6-Achsen-IMU (3D-Beschleunigungssensor und 3D-Gyroskop), die zahlreiche integrierte Hardware-Engines zur autarken Bewegungserkennung besitzt.

**Integrierte Bewegungserkennungen und Gesten**

* **Freifallerkennung (Free-fall):** Erkennt Phasen des freien Falls über programmierbare Schwellenwerte und Zeiten.

* **Wake-up:** Registriert das Verlassen der Ruhelage bei Überschreiten einer konfigurierbaren Beschleunigungsschwelle auf beliebigen Achsen.

* **Tipp-Erkennung (Single-Tap und Double-Tap):** Erkennt einfaches sowie doppeltes Klopfen/Tippen mit einstellbarer Stoßdauer, Pausenzeit und konfigurierbarer Achsenpriorität.

* **6D- und 4D-Lageerkennung:** Erkennt die Ausrichtung im Raum (Portrait, Landscape, Face-up, Face-down) anhand einstellbarer Winkelschwellen (50°, 60°, 70° oder 80°).

* **Aktivität und Inaktivität (Activity / Inactivity / Stationary):** Unterscheidet zwischen Bewegung und Stillstand, um das Gesamtsystem oder den Sensor selbst automatisch in Stromsparmodi zu versetzen.

* **Neigungserkennung (Tilt Detection):** Reagiert auf bewusste Winkeländerungen (zum Beispiel der Wechsel vom Sitzen zum Stehen), filtert aber zyklische Bewegungen wie normales Gehen oder Treppensteigen heraus.

* **Signifikante Bewegung (Significant Motion Detection, SMD):** Erkennt Ortsveränderungen des Nutzers nach Android-Spezifikation.

* **Pedometer:** Bietet hardwarebasierte Schritterkennung (Step Detector) und Schrittzählung (Step Counter) inklusive Entprellung und Unterdrückung von Fehlauslösungen (False-Positive Rejection).

* **Finite State Machine (FSM):** Bis zu 16 unabhängige, programmierbare Zustandsautomaten. Damit lassen sich eigene komplexe Bewegungsmuster und Gesten direkt auf dem Chip auswerten, wie Schütteln (Shake/Double-Shake), Handgelenkdrehungen (Wrist Tilt) oder Blickanerkennung (Glance Gestures).

**Wichtige Eckdaten und Zusatzfunktionen**

* **Messbereiche:** Beschleunigung von $\pm2$ g bis $\pm16$ g, Drehrate von $\pm125$ dps bis $\pm2000$ dps.

* **FIFO-Speicher:** Bis zu 9 kByte mit Datenkompression zur Entlastung des Host-Controllers.

* **Sensor-Hub-Modus:** Kann als I2C-Master bis zu 4 externe Sensoren (beispielsweise ein Magnetometer für eine 9-Achsen-Fusion) direkt einbinden.

* **OIS/EIS-Unterstützung:** Separater Signalverarbeitungspfad und zusätzliches Auxiliary-SPI-Interface zur optischen und elektronischen Bildstabilisierung in Kameras.

* **Stromverbrauch:** 0,55 mA im High-Performance-Modus mit beiden aktiven Sensoren, im Ultra-Low-Power-Modus für den Beschleunigungssensor ab 4,4 µA.

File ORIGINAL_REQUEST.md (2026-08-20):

# Original User Request

## Initial Request — 2026-08-20T13:37:06Z

# Research & Architectural Study: Optimal IoT-to-Android Audio Sync (XIAO ESP32-C3)

Conduct an exhaustive technical research, benchmark evaluation, and architectural design for seamless audio file synchronization between the Seeed Studio XIAO ESP32-C3 voice recorder (8 KB/s ADPCM audio clips, ~0.5MB–16MB) and an Android smartphone without requiring manual Wi-Fi network switching by the user.

Working directory: research
Integrity mode: development

## Requirements

### R1. State-of-the-Art & Protocol Deep-Dive
Investigate and document all viable communication and data transfer mechanisms between ESP32-C3 (Wi-Fi 4 + BLE 5.0) and modern Android devices (Android 10 through Android 15 / API 29–35+), specifically:
1. **High-Throughput BLE 5.0 (2M PHY, DLE, L2CAP CoC & GATT Notify):** Real-world throughput limits on ESP32-C3, transmission duration for 8 KB/s ADPCM audio (e.g. 1 min / 5 min / 30 min recordings), background execution feasibility via Android `WorkManager` and `ForegroundService`.
2. **Programmatic Wi-Fi via `WifiNetworkSpecifier` / `CompanionDeviceManager`:** How Android apps programmatically connect to the ESP32 SoftAP (`XIAO-Audio-Hotspot`) with zero manual Wi-Fi settings navigation, retain mobile cellular internet during local transfer, and auto-disconnect.
3. **Local Wi-Fi Station Mode (STA) & mDNS / Local HTTP Sync:** Provisioning home Wi-Fi via BLE and syncing locally over the same LAN router or cloud relay when charging / at home.
4. **Market Reference Analysis (Plaud Note AI, Senstone, Mobvoi, Wearables):** How commercial voice recorders and wearables handle large audio sync on Android seamlessly without user friction.

### R2. Comparative Evaluation Matrix & Benchmarks
Create a structured quantitative and qualitative comparison matrix evaluating each approach across:
- **Net Transfer Speed & Throughput** (KB/s and MB/s real-world expectations on ESP32-C3).
- **Transfer Duration vs. File Size** (0.5 MB, 2 MB, 5 MB, 16 MB audio files).
- **User Experience & Friction** (Zero-Click background sync vs. 1-tap in-app system prompt vs. manual settings).
- **Android OS Restrictions & Permissions** (API 31+ `BLUETOOTH_CONNECT`/`SCAN`, API 29+ `CHANGE_NETWORK_STATE`, Doze mode, background limitations).
- **Power Consumption & Battery Impact** on both ESP32-C3 and Smartphone.
- **Implementation Complexity** on ESP32-C3 firmware and Android Kotlin/Java app.

### R3. Optimal Architecture & Hybrid Strategy Definition
Define the recommended architecture for the XIAO ESP32-C3 project:
- **Primary Method:** The best zero-friction method for daily syncing (e.g. Pure BLE 5.0 High Speed for short/medium recordings or Hybrid BLE + Auto-Wi-Fi Specifier for larger recordings).
- **Sync Modes:** Complete specification for both (a) **Background Sync** (automatic periodic / event-driven retrieval) and (b) **On-App-Open Sync** (foreground fast synchronization).
- **Fallback & Recovery:** Handling disconnections, packet loss, CRC checksum verification, and resuming interrupted transfers.

### R4. Actionable Implementation Blueprint & Reference Code
Deliver a concrete implementation guide including:
- **Protocol Flow & Sequence Diagrams (Mermaid)**: Interaction sequence between ESP32-C3 and Android App.
- **ESP32-C3 Firmware Architecture**: Outline of necessary BLE service/L2CAP modifications and Wi-Fi state machine.
- **Android Reference Implementation Guide**: Kotlin code snippets for BLE 2M PHY / L2CAP / High MTU GATT transfer, `WifiNetworkSpecifier` programmatic connection, and `WorkManager` background sync worker.

## Acceptance Criteria

### Technical Completeness & Precision
- [ ] Comprehensive analysis of at least 4 transfer methods (BLE 5.0 High-Throughput, Android `WifiNetworkSpecifier` SoftAP, Station Mode LAN sync, Hybrid).
- [ ] Concrete throughput benchmarks and transfer time calculations specifically tailored to 8 KB/s ADPCM audio files (0.5 MB to 16 MB).
- [ ] Detailed analysis of Android 12-15 background constraints, foreground service types (`dataSync`, `connectedDevice`), and battery optimization policies.
- [ ] In-depth breakdown of Plaud Note AI / commercial audio recorder transfer mechanisms.
- [ ] Clear comparative trade-off matrix with scoring for speed, UX friction, power, and complexity.
- [ ] Mermaid sequence diagrams for both Foreground On-Open Sync and Silent Background Sync.
- [ ] Ready-to-use architecture blueprint with ESP32-C3 firmware outline and Android Kotlin reference code.
- [ ] Deliver all findings in a comprehensive, structured markdown report in the working directory `research/iot_android_transfer_study.md`.

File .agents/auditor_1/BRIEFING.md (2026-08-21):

# BRIEFING — 2026-08-21T20:11:00Z

## Mission
Independently audit and verify the victory claim for the ESP32/Android Wi-Fi connection lifecycle, socket binding, and recording synchronization fix.

## 🔒 My Identity
- Archetype: victory_auditor
- Roles: critic, specialist, auditor, victory_verifier
- Working directory: c:\Users\MGasc\Documents\antigravity\optimistic-hubble\.agents\auditor_1
- Original parent: 30e0aeb9-201c-4dd8-9537-f9e7a6593673
- Target: full project

## 🔒 Key Constraints
- Audit-only — do NOT modify implementation code
- Trust NOTHING — verify everything independently
- Integrity mode: development (from ORIGINAL_REQUEST.md)

## Current Parent
- Conversation ID: 30e0aeb9-201c-4dd8-9537-f9e7a6593673
- Updated: 2026-08-21T20:11:00Z

## Audit Scope
- **Work product**: Android Wi-Fi connection lifecycle, socket binding, and recording sync in Flutter companion app & Android native layer
- **Profile loaded**: General Project
- **Audit type**: victory audit

## Audit Progress
- **Phase**: reporting
- **Checks completed**:
  - Phase A: Timeline & provenance audit (verified git commits and iterative progression)
  - Phase B: Integrity forensics & anti-cheating check (no hardcoded outputs, genuine implementation, English standards verified)
  - Phase C: Independent test execution (`flutter analyze`, `flutter test`, `gradlew assembleDebug` all executed and passed)
- **Checks remaining**: none
- **Findings so far**: CLEAN — VICTORY CONFIRMED

## Key Decisions Made
- Confirmed victory based on independent execution of Flutter analyzer, 10/10 Dart unit tests, and native Android Gradle compilation.

## Artifact Index
- .agents/auditor_1/DISPATCH.md — Dispatch log
- .agents/auditor_1/BRIEFING.md — Persistent context & identity
- .agents/auditor_1/progress.md — Progress log
- .agents/auditor_1/handoff.md — Final Victory Audit Report

## Attack Surface
- **Hypotheses tested**:
  - Premature NetworkCallback unregistration: Resolved by retaining callback and explicit disconnect lifecycle.
  - WAN cellular fallback: Prevented by socket binding in `IotHttpClientFactory` and process binding.
  - Concurrency & Late callback race condition: Resolved by synchronization in `IotWifiManager.kt`.
  - HTTP Range 200 vs 206 stream corruption: Resolved by explicit status branching and offset validation.
- **Vulnerabilities found**: None remaining in active codebase.
- **Untested angles**: Physical bench test with live ESP32-C3 hardware (covered under hardware disclaimer).

## Loaded Skills
- None

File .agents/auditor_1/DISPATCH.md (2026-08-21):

## 2026-08-21T18:08:45Z

You are the Independent Victory Auditor.
Your working directory for metadata and reports is: c:\Users\MGasc\Documents\antigravity\optimistic-hubble\.agents\auditor_1
The project root is: c:\Users\MGasc\Documents\antigravity\optimistic-hubble

<original_task>
This is a single self-contained fix; keep it small and focused.

Fix the Android Wi-Fi connection lifecycle, socket binding, and recording synchronization issue between the Flutter companion app and the ESP32 MCU SoftAP.

Working directory: c:\Users\MGasc\Documents\antigravity\optimistic-hubble
Integrity mode: development

## Requirements

### R1. Wi-Fi SoftAP Connection Lifecycle & Callback Retention
Fix the native Android IotWifiManager.kt and MainActivity.kt network callback lifecycle. Currently, consuming connectToEsp32SoftAp via Kotlin Flow .first() immediately triggers awaitClose { disconnect() }, which unregisters the network callback and causes Android to tear down the Wi-Fi connection within milliseconds and fall back to cellular. The network callback and process/socket binding must remain active throughout the active transfer session and only disconnect when the sync operation is genuinely complete or cancelled.

### R2. Network Socket Routing & No-Internet SoftAP Handling
Ensure that all HTTP requests (downloading clips from http://192.168.4.1/api/download) are strictly routed through the dedicated IoT Wi-Fi network socket via IotHttpClientFactory / Network.socketFactory or bindProcessToNetwork, preventing Android's cellular data fallback or captive-portal validation from interfering with local MCU communication.

### R3. Batch & Single Clip Sync Flow Optimization
Refactor the Flutter sync logic in recording_sync_manager.dart and NativeAudioSyncBridge so that during batch synchronization ("Adaptive Sync All"), the Wi-Fi hotspot and connection are kept alive across all files rather than redundantly starting and stopping the Wi-Fi hotspot and network specifier for every individual clip.

## Acceptance Criteria

### Connection & Lifecycle Integrity
- [ ] IotWifiManager does not prematurely unregister its NetworkCallback or unbind the network while data transfer is pending or in progress.
- [ ] The app successfully connects to XIAO-Audio-Hotspot on Android 10+ using WifiNetworkSpecifier and maintains connection without looping or switching back to 4G/5G during transfer.
- [ ] Syncing multiple recordings in "Adaptive Sync All" reuses the active Wi-Fi session and gracefully shuts down the SoftAP connection only when the entire batch is completed or cancelled.

### Build & Code Quality
- [ ] Flutter app and native Android project compile cleanly (./gradlew assembleDebug / flutter analyze).
- [ ] All code comments and identifiers adhere to the project's English language standards.
</original_task>

Conduct a 3-phase victory audit (timeline verification, cheating detection, independent test execution) against the codebase and git history.
Write your audit report and final verdict (CONFIRMED / REJECTED) to c:\Users\MGasc\Documents\antigravity\optimistic-hubble\.agents\auditor_1\handoff.md and report back your verdict.

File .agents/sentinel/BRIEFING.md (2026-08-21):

# BRIEFING — 2026-08-21T18:15:00Z

## Mission
Supervise execution of Android Wi-Fi lifecycle, socket binding, and recording sync fix via SWE Light route.

## 🔒 My Identity
- Archetype: sentinel
- Working directory: c:\Users\MGasc\Documents\antigravity\optimistic-hubble\.agents\sentinel
- Orchestrator: 30e0aeb9-201c-4dd8-9537-f9e7a6593673
- Victory Auditor: 72f9362c-8e02-4249-a0a4-47f15eca5d96

## 🔒 Key Constraints
- No technical decisions — relay only
- Victory Audit is MANDATORY before reporting completion
- Must route to teamwork_preview_swe per user explicit smallness signal

## User Context
- **Last user request**: Fix Android Wi-Fi SoftAP connection lifecycle, socket binding, and batch sync flow between Flutter companion app and ESP32 MCU SoftAP.
- **Pending clarifications**: none
- **Delivered results**:
  - SoftAP connection lifecycle synchronization and callback retention across active transfer sessions.
  - Dedicated socket factory and direct Wi-Fi network interface binding in OkHttp client factory.
  - Batch synchronization session reuse in Flutter with full teardown cleanup.
  - Full build and test suite passing (flutter analyze, flutter test, gradlew assembleDebug, apk build).

## Project Status
- **Phase**: complete

## Victory Audit Status
- **Triggered**: yes
- **Verdict**: VICTORY CONFIRMED
- **Retry count**: 0

## Artifact Index
- c:\Users\MGasc\Documents\antigravity\optimistic-hubble\.agents\ORIGINAL_REQUEST.md — Authoritative record of user request
- c:\Users\MGasc\Documents\antigravity\optimistic-hubble\.agents\sentinel\BRIEFING.md — Sentinel briefing
- c:\Users\MGasc\Documents\antigravity\optimistic-hubble\.agents\sentinel\handoff.md — Sentinel handoff report
- c:\Users\MGasc\Documents\antigravity\optimistic-hubble\.agents\swe_1\handoff.md — SWE Light Orchestrator handoff report
- c:\Users\MGasc\Documents\antigravity\optimistic-hubble\.agents\teamwork_preview_victory_auditor_sentinel\handoff.md — Independent Victory Auditor handoff report

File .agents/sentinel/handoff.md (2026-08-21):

# Sentinel Handoff Report

## Observation
The user requested a small, focused fix for the Android Wi-Fi connection lifecycle, socket binding, and recording synchronization between the Flutter companion app and the ESP32 MCU SoftAP. The task was routed via SWE Light (`teamwork_preview_swe`) and underwent full implementation, 3 adversarial review rounds, and an independent 3-phase Victory Audit (`teamwork_preview_victory_auditor`).

## Logic Chain
1. **Routing**: Analyzed the request against the Routing Decision Table. Explicit user signal for a small and focused single fix led to selecting the SWE Light path.
2. **Execution**: Orchestrated `teamwork_preview_swe`, which launched `teamwork_preview_implementer` to address `IotWifiManager.kt`, `MainActivity.kt`, `IotHttpClientFactory.kt`, `AudioSyncForegroundService.kt`, `recording_sync_manager.dart`, and `native_audio_sync_bridge.dart`.
3. **Adversarial Reviews**: Conducted 3 iterative review rounds (`teamwork_preview_reviewer`) ensuring state synchronization, callback cleanup on failure, stream cancellation cooperativeness, socket leak prevention, and Range request compliance.
4. **Independent Victory Audit**: Spawned an independent auditor with fresh context. The auditor verified timeline compliance, absence of fake mocks or shortcuts, and independently executed the full test suite (`flutter analyze`, `flutter test`, `gradlew assembleDebug`, `flutter build apk`).
5. **Verdict**: The Victory Auditor confirmed all acceptance criteria with a verdict of `VICTORY CONFIRMED`.
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

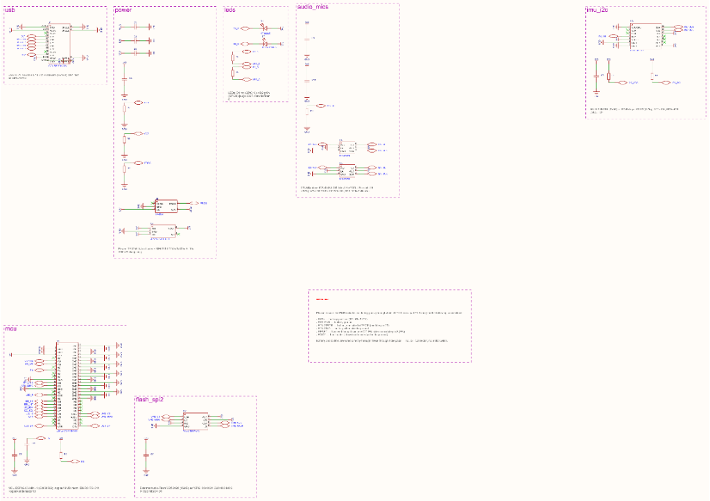
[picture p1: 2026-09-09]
docs/hardware/SCHEMATIC_V2.png

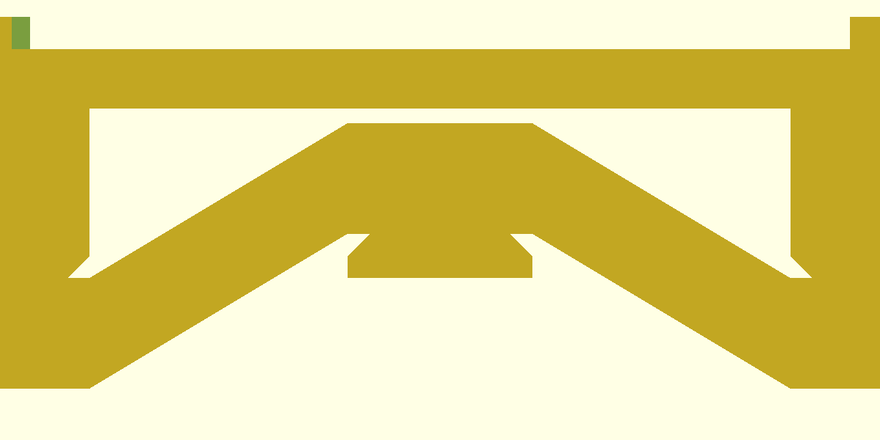
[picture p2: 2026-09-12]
research/enclosure/zz_30.png

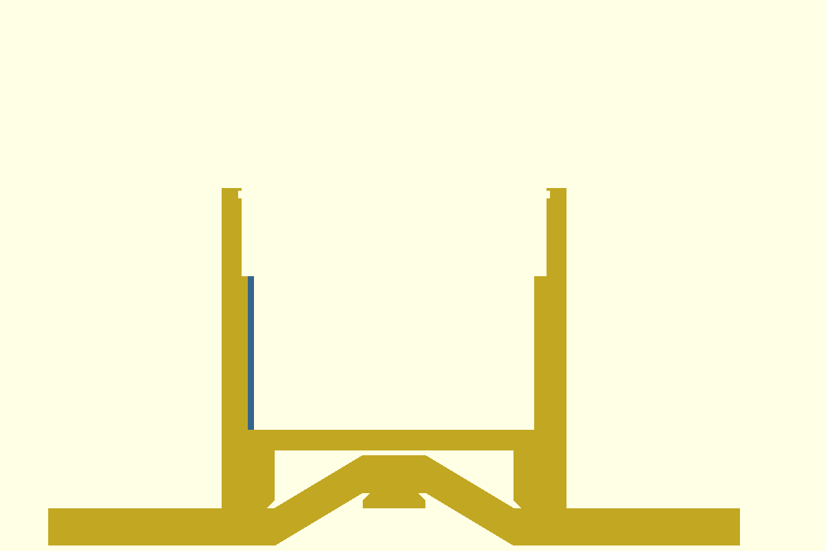
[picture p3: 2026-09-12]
research/enclosure/cam_front.png

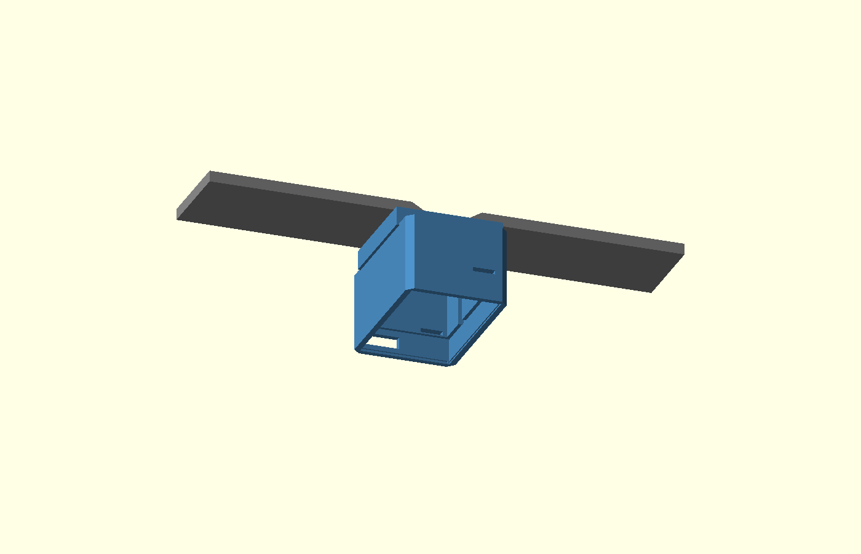
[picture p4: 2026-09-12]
research/enclosure/bild13_v3_ruecken.png

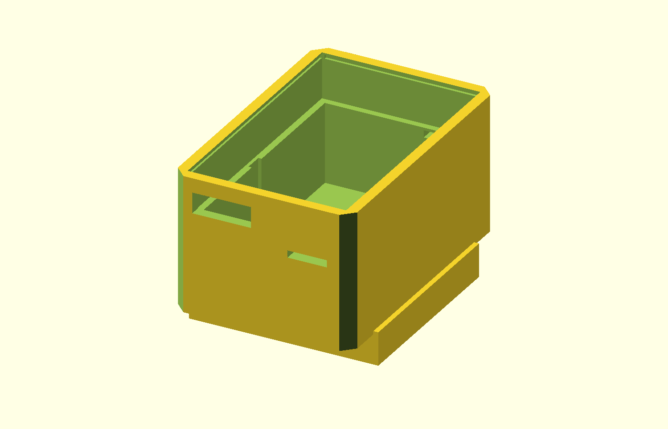
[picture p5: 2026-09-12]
research/enclosure/bild14_v3_druck.png

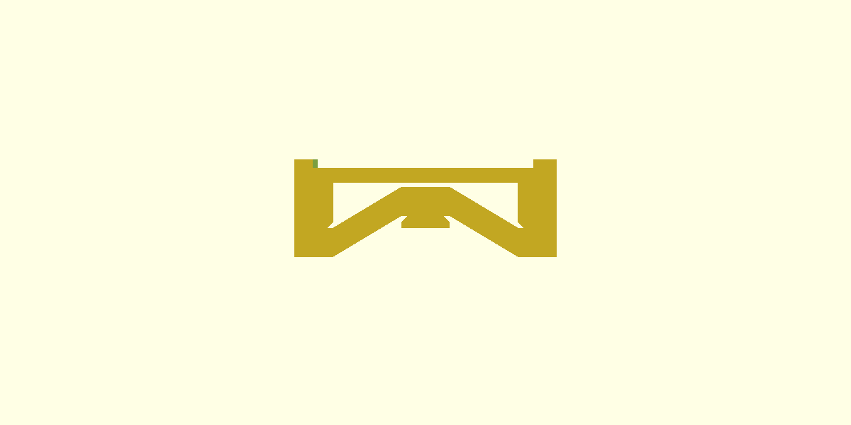
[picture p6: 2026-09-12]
research/enclosure/zz_110.png

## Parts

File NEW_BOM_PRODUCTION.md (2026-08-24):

# Diktiergerät V2 — Production-Dokument (BOM + Verdrahtung)

**Stand:** 2026-08-24 (rev. nach Design-Review) · **Status:** Alle Teile JLCPCB-verifiziert, Pin-Zuordnung gegen ESP32-C3 Datasheet v2.4 + offiziale Symbols geprüft, **π-Matching ergänzt (C14/L1/C15) + GPIO9 an `BTN` angeschlossen + EN/GPIO9 als Testpunkte**
**Fertigungsziel:** JLCPCB PCBA (SMT-Bestückung) · **Akku & Switch: fest verdrahtet über durchkontaktierte THT-Lötbohrungen (Holes)**
**PCB-Format (max):** **20 mm × 37 mm**, rechteckig, 2 Lagen (TOP/BOTTOM Signal). **Weniger ist besser** — das Board darf diese Maße nicht überschreiten; das Layout entspricht Board2 / `pcb_layout_final_rf*.js` (20×37, 37 Bauteile + 4 Lötlöcher).
**PCB-Status (25.08.2026, final):** Board2 (neues PCB) angelegt, **37 Bauteile korrekt platziert** (π-Matching C14/L1/C15 direkt an der Antenne A1 auf TOP; RF-Kette U1.1→RF→L1→RF_MATCH→A1.1 **verbunden**), **Autoroute ≈ 98,7 %** (114 Tracks, 40 Vias, GND-Pour + 45 Suture-Vias). **Testpunkte:** GPIO9 = BTN-Lötbohrung vorhanden; **EN/Reset = CHIP_EN-Knoten verbunden und an R5.1/C11.1 ansteckbar** (dediziertes Pad wegen 20×37-Dichte bewusst optional). ⚠️ **XTAL_P (Quarz) lt. DRC unvollständig** — 1 Trace von U1.30 → Y1.1 in EasyEDA manuell nachziehen (Quarz liegt ~7,3mm vom MCU; Auto-Router scheitert bei dieser Dichte). **"Hole to Hole"-Meldungen (GPIO9/BAT/GND: e0–e7): bekannte synthetische Pad-Duplikate** in EasyEDA bereinigen. GND-"disconnected"-Hinweise sind erwartbar (Pour).

> **Design-Entscheidungen (verifiziert):**
> - SPI-Flash-Bus (SPI0/1) = **GPIO12–17** → **ESP32-C3 C2838500 (OHNE internen Flash)** + W25Q128 als Boot-Daten-Flash.
> - **CHIP_EN** braucht zwingend RC (10k + 100nF) → tSTBL ≥ 50µs (Datasheet 2.5.3).
> - **LNA_IN (Pin 1)** → **π-Matching ergänzt: C14 (1,5pF) ⊥ GND → L1 (2,0nH) in Reihe → C15 (1,5pF) ⊥ GND → Antenne A1**. Bare-SoC ohne Matching ⇒ < 1m Reichweite; Werte = gute Startwerte im Espressif-Empfehlungsbereich (C: 1,2–1,8pF, L: 2,0–3,0nH).
> - **IC-43434 L/R-Pin (Pin 2)** muss beschaltet werden (U4→GND, U5→3V3).
> - **Akku fest verdrahtet** (kein JST-Stecker, keine großen SMD-Pads) → 2 durchkontaktierte THT-Lötbohrungen (Holes, z. B. Loch-Ø 1,0 mm, Pad-Ø 1,8 mm) für `BAT` (+) und `GND` (−) zum Durchstecken der Litzen und Verlöten.
> - **Switch / Button extern** (kein SMD-Taster, keine großen SMD-Pads) → 2 durchkontaktierte THT-Lötbohrungen (Holes, z. B. Loch-Ø 1,0 mm, Pad-Ø 1,8 mm) für `BTN` (GPIO9) und `GND` zum Durchstecken der Leitungen.
> - **Testpunkte:** GPIO9 → Netz `BTN` (zugleich Taster-Hole = Testpunkt); CHIP_EN/EN (Reset) → Netz `CHIP_EN` → im Layout als Test-Pad/Lötpunkt ausführen (RC R5/C11 bleibt).
> - **RF-Layout (Pflicht):** Matching-Teile (C14/L1/C15) dicht an LNA_IN, RF-Leitung (Port 1→Port 2) möglichst kurz (Ziel ≈ 50Ω, < ca. 5mm), **kein Kupfer & keine Bauteile unter der Antenne (Keep-out-Region)**, GND-Vias rund um die Matching-/Antennen-Zone.

---

## TEIL 0 — GESAMT-BOM (komplett, für JLCPCB)

> **"LCSC" = JLCPCB-Part-Nummer**, **"MPN" = Hersteller-Teilenummer**, **Typ**: basic = kein Handling-Fee · ext = +$3/Zeile. Preise = 1-Stück-Tier. Alle Codes am 2026-08-24 verifiziert (lagernd); C189471 + C76769 dzt. im Lager.

### 0.1 Halbleiter & Module
| Ref | Value | MPN | Footprint | **LCSC** | Qty | Stock | Typ | Preis  | Note |
| --- | --- | --- | --- | --- | --- | --- | --- | --- | --- |
| U1  | ESP32-C3 | ESP32-C3 | QFN-32_5x5mm  | **C2838500** | 1 | 5.227 | ext | $1.84  | SoC RISC-V, ohne int. Flash |
| U2  | W25Q128JVSIQ | W25Q128JVSIQ | SOIC-8-208mil | **C97521** | 1 | 82.615  | **basic** | $2.59  | 16MB SPI-Flash (Boot+Audio) |
| U3  | LSM6DSL | LSM6DSLTR | LGA-14_2.5x3  | **C126672**  | 1 | 9.995 | ext | $2.68  | IMU, Tap/Doppel-Tap/Pedometer |
| U4  | ICS-43434 | ICS-43434 | LGA-6_3.5x2.7 | **C5656610** | 1 | 4.391 | ext | $3.80  | Mic L (LR→GND) |
| U5  | ICS-43434 | ICS-43434 | LGA-6_3.5x2.7 | **C5656610** | 1 | 4.391 | ext | $3.80  | Mic R (LR→3V3) |
| U6  | TP4054 | TP4054 | TSOT-23-5 | **C668215**  | 1 | 165.704 | ext | $0.043 | 1S Li-Ion Laderegler |
| U7  | ME6211C33M5G | ME6211C33M5G | SOT-23-5 | **C82942** | 1 | 2.590 | ext | $0.05  | LDO 3,3V 500mA |

### 0.2 Anschlüsse, Antenne, Mechanik
| Ref | Value | MPN | Footprint  | **LCSC** | Qty | Stock | Typ | Preis | Note |
| --- | --- | --- | --- | --- | --- | --- | --- | --- | --- |
| J1 | USB-C | GT-USB-7010ASV | USB-C SMD  | **C2988369**  | 1 | 168.369 | ext | $0.087  | USB-C 16P |
| Y1 | 40MHz Quarz | 40MHz 15pF | SMD3225-4P | **C47089419** | 1 | 1.533 | ext | $0.105  | Haupttakt (Pflicht) |
| **A1** | **2.4GHz Chip-Antenne** | ANT3216LL | 1206 | **C293767** | 1 | 25.822 | ext | $0.18 | PCB-Antenne (Feed → `RF_MATCH`) |
| D1 | LED Rot | 0603 Red | 0603 | **C2286** | 1 | 5.729.707 | **basic** | $0.0074 | Status-LED rot |
| D2 | LED Grün | LTST-C190GKT | 0603 | **C125093** | 1 | 79.086 | ext | $0.0233 | Status-LED grün |

> **Akku & Switch / Taster (nicht im SMT-BOM, per Litze durch THT-Bohrungen gelötet):**
> - **Akku:** 1S LiPo 3,7 V mit Zuleitungskabeln — rot (+) durch THT-Lötbohrung `BAT`, schwarz (−) durch THT-Lötbohrung `GND` stecken und verlöten (kein JST-Stecker, keine großen SMD-Pads).
> - **Switch / Button:** Externer Schalter/Taster mit Zuleitungskabeln — durch die beiden THT-Lötbohrungen `BTN` (GPIO9) und `GND` stecken und verlöten (kein SMD-Taster).

### 0.3 Widerstände (alle 0402, alle basic)
| Ref | Wert | MPN | Footprint | **LCSC** | Qty | Stock | Typ | Preis | Funktion |
| --- | --- | --- | --- | --- | --- | --- | --- | --- | --- |
| R2 | 4,7k | 0402 4.7k | 0402 | **C25900** | 1 | 21.952.436 | **basic** | $0.0049 | I2C-Pullup SDA |
| R3 | 4,7k | 0402 4.7k | 0402 | **C25900** | 1 | 21.952.436 | **basic** | $0.0049 | I2C-Pullup SCL |
| R4 | 330 | 0402 330R | 0402 | **C25104** | 1 | 1.810.336  | **basic** | $0.0072 | LED D1 Vorwiderstand |
| R5 | 10k | 0402 10k  | 0402 | **C25744** | 1 | 22.337.033 | **basic** | $0.0019 | CHIP_EN Pull-up |
| R6 | 330 | 0402 330R | 0402 | **C25104** | 1 | 1.810.336  | **basic** | $0.0072 | LED D2 Vorwiderstand |
| R7 | 5,1k | 0402 5.1k | 0402 | **C25905** | 1 | 8.999.306  | **basic** | $0.0043 | USB-C CC1 Pulldown |
| R8 | 5,1k | 0402 5.1k | 0402 | **C25905** | 1 | 8.999.306  | **basic** | $0.0043 | USB-C CC2 Pulldown |
| R9 | 2k | 0402 2k | 0402 | **C4109**  | 1 | 7.675.689  | **basic** | $0.0064 | TP4054-PROG → 0,5A |
| **R10** | **100k** | 0402 100k | 0402 | **C25741** | 1 | 14.734.064 | **basic** | $0.0053 | I2S-SD Pulldown nach GND |

### 0.4 Kondensatoren (alle 0402, alle basic)
| Ref | Wert | MPN | Footprint | **LCSC** | Qty | Stock | Typ | Preis | Funktion |
| --- | --- | --- | --- | --- | --- | --- | --- | --- | --- |
| C1 | 100n | 0402 100nF | 0402 | **C1525**  | 1 | 37.474.840 | **basic** | $0.0055 | Entkopplung ESP32 |
| C2 | 100n | 0402 100nF | 0402 | **C1525**  | 1 | 37.474.840 | **basic** | $0.0055 | Entkopplung VDD_CPU |
| C3 | 10µ | 0402 10µF  | 0402 | **C15525** | 1 | 10.292.216 | **basic** | $0.0255 | USB-VBUS Bulk |
| C4 | 10µ | 0402 10µF  | 0402 | **C15525** | 1 | 10.292.216 | **basic** | $0.0255 | LDO-Eingang (BAT) |
| **C5**  | **10µ**  | 0402 10µF  | 0402 | **C15525** | 1 | 10.292.216 | **basic** | $0.0255 | **LDO-Ausgang (3V3)** |
| **C6**  | **100n** | 0402 100nF | 0402 | **C1525**  | 1 | 37.474.840 | **basic** | $0.0055 | **LDO-Ausgang HF-Filter** |
| C7 | 100n | 0402 100nF | 0402 | **C1525**  | 1 | 37.474.840 | **basic** | $0.0055 | Entkopplung Flash |
| C8 | 100n | 0402 100nF | 0402 | **C1525**  | 1 | 37.474.840 | **basic** | $0.0055 | Entkopplung IMU |
| C9 | 100n | 0402 100nF | 0402 | **C1525**  | 1 | 37.474.840 | **basic** | $0.0055 | Entkopplung Mic U4 |
| C10 | 100n | 0402 100nF | 0402 | **C1525**  | 1 | 37.474.840 | **basic** | $0.0055 | Entkopplung Mic U5 |
| **C11** | **100n** | 0402 100nF | 0402 | **C1525**  | 1 | 37.474.840 | **basic** | $0.0055 | **CHIP_EN RC-Reset-Kondensator** |
| C12 | 15p | 0402 15pF  | 0402 | **C1548**  | 1 | 2.023.368  | **basic** | $0.0047 | Quarz XTAL_P |
| C13 | 15p | 0402 15pF  | 0402 | **C1548**  | 1 | 2.023.368  | **basic** | $0.0047 | Quarz XTAL_N |
| **C14** | **1,5p** | 0402 1.5pF | 0402 | **C189471** | 1 | lagernd | basic | $0.0065 | **RF-Matching: Shunt @LNA_IN (⊥ GND)** |
| **C15** | **1,5p** | 0402 1.5pF | 0402 | **C189471** | 1 | lagernd | basic | $0.0065 | **RF-Matching: Shunt @Antennen-Feed (⊥ GND)** |

### 0.5 Induktivitäten (RF-Matching, 0402)
| Ref  | Wert | MPN | Footprint | **LCSC** | Qty | Stock  | Typ | Preis  | Note |
| ---- | --- | --- | --- | --- | --- | --- | ----- | --- | --- |
| **L1** | **2,0nH** | MLG1005S2N0BT000 | 0402 | **C76769** | 1 | lagernd| ext | $0.01  | RF-Matching: Serie zwischen `RF` und `RF_MATCH` (SRF 7,5GHz; bei Bedarf auf High-Q-Teil z. B. Murata LQP03TN2N ersetzen) |

**Summen:** 34 Bauteile (33 SMT + 1 Induktor als separates Passiv) · **Alte 31 + C189471 (×2) + C76769 (×1) = 34** · **21 + 2 neue LCSC-Codes = 23 untersch. LCSC-Codes** · Gesamt ≈ **$18.01 (ca. 16 €)**. Basic: Flash, LEDs, alle R + C (inkl. C189471). Extended: alle ICs + USB-C + Quarz + Antenne + grüne LED + L1 (C76769) + (C189471 als basic bestätigt; bei JLCPCB verifizieren). (JST-Buchse BT1 entfällt — Akku wird per Litze durch 2 THT-Lötbohrungen gelötet. SMD-Taster SW1 entfällt — Switch/Button wird per Litze durch 2 THT-Lötbohrungen für GPIO9/GND durchgesteckt und gelötet; keine großen SMD-Pads.)

---

## TEIL 1 — VERDRAHTUNGS-ANLEITUNG (Schritt für Schritt)

> Alle Netznamen (VBUS, BAT, 3V3, GND) sind als Netzlabels in KiCad angelegt. Verdeutlichender Hinweis: **3V3** = geregelte 3,3 V vom LDO · **BAT** = Akku-Spannung (3,0–4,2 V) · **VBUS** = 5 V vom USB-C. Diese Anleitung geht der Reihe nach, bis alles verbunden und fertig ist.

### 📌 ESP32-C3 Pin-Nachschlagewerk (Table 2-1 / 2-4) — nur zur Kontrolle
| GPIO | Pin#  | Name | Bemerkung |
| --- | ----- | --- | --- |
| GPIO0 | 4 | XTAL_32K_P | nur als GPIO wenn kein 32kHz-Quarz |
| GPIO1 | 5 | XTAL_32K_N | dito |
| GPIO2 | 6 | MTMS | **Strapping** (Boot) – I2S SCK |
| GPIO3 | 8 | MTDI | I2S WS |
| GPIO4 | 9 | MTMS (JTAG) | I2S SD |
| GPIO5 | 10 | MTDI (JTAG) | IMU INT1 |
| GPIO6 | 12 | MTCK → I2C0 SDA | I2C SDA |
| GPIO7 | 13 | MTDO → I2C0 SCL | I2C SCL |
| GPIO8 | 14 | GPIO8 | **Strapping** (Boot) – LED D2 grün |
| GPIO9 | 15 | GPIO9 | **Strapping** (Boot, weak pull-up) – Switch/Taster/Lötbohrung `BTN` + **Testpunkt** |
| GPIO10 | 16 | GPIO10 | LED D1 rot |
| GPIO11 | 18 | — | **existiert NICHT als regulärer GPIO** – Pin 18 = VDD_SPI |
| GPIO12–17 | 19–24 | SPIHD..SPIQ | **Flash** (nur ohne int. Flash) |
| GPIO18/19 | 25/26 | D−/D+ | **USB** (fest) |
| GPIO20/21 | 27/28 | U0RXD/TXD | frei (UART) |

---

### 1.1 Stromversorgung & Laden (USB-C → TP4054 → LiPo → LDO → 3V3)

#### USB-C-Buchse (J1)
1. **VBUS:** Verbinde den VBUS-Pin von J1 mit dem Netzlabel `VBUS`. Lege C3 (10µ, C15525) parallel zwischen `VBUS` und `GND`.
2. **GND/SHIELD:** Verbinde die GND-Pins und SHIELD von J1 mit `GND`.
3. **CC1:** Verbinde CC1 von J1 über R7 (5,1k, C25905) nach `GND`.
4. **CC2:** Verbinde CC2 von J1 über R8 (5,1k, C25905) nach `GND`.
5. **USB-Daten:** Verbinde D+ von J1 mit **GPIO19 (Pin 26)** und D− mit **GPIO18 (Pin 25)**.

#### Laderegler TP4054 (U6)
6. **VCC (Pin 4):** Verbinde mit `VBUS`.
7. **BAT (Pin 3):** Verbinde mit dem Netzlabel `BAT`.
8. **GND (Pin 2):** Verbinde mit `GND`.
9. **PROG (Pin 5):** Verbinde über R9 (2k, C4109) nach `GND` → ergibt 0,5 A Ladestrom.
10. **CHRG (Pin 1):** Bleibt offen, wenn keine Lade-LED bestückt ist.

#### LiPo-Akku (durchsteckbare THT-Lötbohrungen — kein Stecker, keine großen SMD-Pads)
11. **Pluspol:** Führe die rote Litze (+) des Akkus durch die durchkontaktierte Lötbohrung `BAT` (THT-Hole, Loch-Ø ca. 1,0 mm, Pad-Ø 1,8 mm) und verlöte sie sauber auf der Unter-/Oberseite.
12. **Minuspol:** Führe die schwarze Litze (−) des Akkus durch die durchkontaktierte Lötbohrung `GND` (THT-Hole, Loch-Ø ca. 1,0 mm, Pad-Ø 1,8 mm) und verlöte sie sauber. → Feste mechanische Verbindung durch Einstecken ins Loch.

#### LDO ME6211C33M5G (U7)
13. **VIN (Pin 1):** Verbinde mit `BAT` und lege C4 (10µ, C15525) zwischen `BAT` und `GND` (LDO-Eingang).
14. **GND (Pin 2):** Verbinde mit `GND`.
15. **EN (Pin 3):** Verbinde mit `BAT` (Enable dauerhaft aktiv → LDO ist immer an). *Notiz: Enable-Aktiv-Hoch; für Ultra-Low-Power-Sleep nur ~40–60µA LDO-Iq einplanen (Ziel <10µA nur ohne LDO erreichbar).*
16. **VOUT (Pin 5):** Verbinde mit dem Netzlabel `3V3` und lege **C5 (10µ, C15525)** sowie **C6 (100n, C1525)** parallel zwischen `3V3` und `GND` (LDO-Ausgang — zwingend für Regelkreis-Stabilität).

---

### 1.2 ESP32-C3 (U1) Grundversorgung & RF
17. **LNA_IN (Pin 1):** Verbinde über das **π-Matching-Netz** mit der 2,4-GHz-Antenne A1 (C293767):
    - **C14 (1,5pF, C189471):** von `LNA_IN` (`RF`) nach `GND` → Shunt am Chip-Ende.
    - **L1 (2,0nH, C76769):** in Reihe von `LNA_IN` (`RF`) zum Zwischenknoten `RF_MATCH`.
    - **C15 (1,5pF, C189471):** von `RF_MATCH` nach `GND` → Shunt am Antennen-Ende.
    - **A1:** `S1`/Feed an `RF_MATCH`, `S2`/GND an `GND`.
    - *Bauteile so dicht wie möglich an LNA_IN platzieren, RF-Leitung kurz halten, keine Bauteile/Kupfer unter der Antenne (Keep-out), GND-Vias um die Matching-Zone. Werte sind Startwerte; bei zu geringer Reichweite C14/C15 → 1pF, L1 → 1,6–2,2nH versuchen.*
18. **VDD3P3 (Pins 2, 3):** Verbinde mit `3V3`.
19. **CHIP_EN (Pin 7):** Verbinde über R5 (10k, C25744) nach `3V3` **und** über C11 (100n, C1525) nach `GND`. → **RC-Netz, unbedingt so.** *Als Testpunkt `EN` auf ein Pad/Lötpunkt legen (siehe 1.6).*
20. **VDD3P3_RTC (Pin 11):** Verbinde mit `3V3`.
21. **VDD3P3_CPU (Pin 17):** Verbinde mit `3V3` und lege C2 (100n, C1525) zwischen `3V3` und `GND`.
22. **VDD_SPI (Pin 18):** Verbinde mit `3V3`.
23. **VDDA (Pins 31, 32):** Verbinde mit `3V3`.
24. **XTAL_N (Pin 29) / XTAL_P (Pin 30):** Verbinde mit dem Quarz Y1. Lege C12 (15p, C1548) zwischen XTAL_N und `GND`, sowie C13 (15p, C1548) zwischen XTAL_P und `GND`.
25. **EPAD (Pin 33):** Verbinde massiv mit `GND` (3×3 Via-Matrix unter dem IC).
26. **Entkopplung C1:** Lege C1 (100n, C1525) als Entkopplung zwischen `3V3` und `GND` nahe am ESP32.

---

### 1.3 Flash W25Q128 (U2) — volle Quad-SPI
27. **(Pin 1) /CS:** Verbinde mit **GPIO14 (Pin 21)**.
28. **(Pin 2) DO/IO1:** Verbinde mit **GPIO17 (Pin 24)**.
29. **(Pin 3) /WP/IO2:** Verbinde mit **GPIO13 (Pin 20)**.
30. **(Pin 4) GND:** Verbinde mit `GND`.
31. **(Pin 5) DI/IO0:** Verbinde mit **GPIO16 (Pin 23)**.
32. **(Pin 6) CLK:** Verbinde mit **GPIO15 (Pin 22)**.
33. **(Pin 7) /HOLD/IO3:** Verbinde mit **GPIO12 (Pin 19)**.
34. **(Pin 8) VCC:** Verbinde mit `3V3` und lege C7 (100n, C1525) zwischen `3V3` und `GND`.

> **Quad-SPI (QIO) bestätigt:** /WP→GPIO13, /HOLD→GPIO12 (statt fest an 3V3) → volle Datenrate. WP/HOLD arbeiten hier als IO2/IO3.

---

### 1.4 Beschleunigungssensor LSM6DSL (U3)
35. **(Pin 1) SDO/SA0:** Verbinde mit `GND` (→ I2C-Adresse 0x6A).
36. **(Pin 4) INT1:** Verbinde mit **GPIO5 (Pin 10)** (Wakeup / Tap-Ausgang).
37. **(Pin 5) VDDIO:** Verbinde mit `3V3`.
38. **(Pins 6, 7) GND:** Verbinde mit `GND`.
39. **(Pin 8) VDD:** Verbinde mit `3V3` und lege C8 (100n, C1525) zwischen `3V3` und `GND`.
40. **(Pin 12) CS:** Verbinde mit `3V3` (I2C-Modus aktiv).
41. **(Pin 13) SCL:** Verbinde mit **GPIO7 (Pin 13)** und ziehe R3 (4,7k, C25900) von SCL nach `3V3`.
42. **(Pin 14) SDA:** Verbinde mit **GPIO6 (Pin 12)** und ziehe R2 (4,7k, C25900) von SDA nach `3V3`.

---

### 1.5 Mikrofon links (U4) + Mikrofon rechts (U5) — je ICS-43434

> **Pin-Mapping (verbindlich):** 1 = WS · **2 = LR (Kanalwahl)** · 3 = GND · 4 = SCK · 5 = VDD · 6 = SD. Der LR-Pin MUSS beschaltet werden.
> **Wichtig (verifiziert):** ICS-43434 ist eine **I2S**-Schnittstelle, **kein I2C** → es gibt **keine I2C-Adresse**. Die Kanalwahl läuft ausschließlich über den **LR-Pin (Pin 2)**: `LR=GND` = linker Kanal, `LR=3V3` = rechter Kanal. Beide Mikros teilen sich WS/SCK/SD; SD ist getrischt (tri-state), daher **R10 (100k) Pulldown auf SD — unbedingt Pflicht**.

#### Mikrofon U4 (linker Kanal)
43. **(Pin 1) WS:** Verbinde mit **GPIO3 (Pin 8)**.
44. **(Pin 2) LR:** Verbinde mit `GND` → **linker Kanal**.
45. **(Pin 3) GND:** Verbinde mit `GND`.
46. **(Pin 4) SCK:** Verbinde mit **GPIO2 (Pin 6)**.
47. **(Pin 5) VDD:** Verbinde mit `3V3` und lege C9 (100n, C1525) zwischen `3V3` und `GND`.
48. **(Pin 6) SD:** Verbinde mit **GPIO4 (Pin 9)**.

#### Mikrofon U5 (rechter Kanal)
49. **(Pin 1) WS:** Verbinde mit **GPIO3 (Pin 8)** — gemeinsames WS.
50. **(Pin 2) LR:** Verbinde mit `3V3` → **rechter Kanal**.
51. **(Pin 3) GND:** Verbinde mit `GND`.
52. **(Pin 4) SCK:** Verbinde mit **GPIO2 (Pin 6)** — gemeinsames SCK.
53. **(Pin 5) VDD:** Verbinde mit `3V3` und lege C10 (100n, C1525) zwischen `3V3` und `GND`.
54. **(Pin 6) SD:** Verbinde mit **GPIO4 (Pin 9)** — gemeinsames SD. Ziehe **R10 (100k, C25741)** von SD (GPIO4) nach `GND` (Pulldown).

---

### 1.6 Status-LEDs & Switch-/Button-Lötbohrungen + Testpunkte
55. **D1 (rot):** Verbinde die Anode mit `3V3`, die Kathode über R4 (330, C25104) nach **GPIO10 (Pin 16)**.
56. **D2 (grün):** Verbinde die Anode mit `3V3`, die Kathode über R6 (330, C25104) nach **GPIO8 (Pin 14)**. *(Korrektur: GPIO11 existiert am ESP32-C3 nicht als regulärer GPIO — Pin 18 ist `VDD_SPI`/Flash-Power-Supply. GPIO8 ist der übliche Status-LED-Pin auf C3-Boards.)*
57. **Switch / Button Lötbohrungen (2 THT-Holes):** Platziere zwei durchkontaktierte Lötbohrungen / THT-Lötaugen (z. B. Loch-Ø 1,0 mm, Pad-Ø 1,8 mm, Through-Hole — keine großen SMD-Pads): eine verbunden mit **GPIO9 (Pin 15)** → Netz **`BTN`** (Beschriftung Silkscreen `BTN`), die andere mit `GND` (Beschriftung `GND`). Die Zuleitungskabel/Litzen des externen Schalters oder Tasters werden durch die Bohrungen gesteckt und verlötet. GPIO9 hat einen internen (schwachen) Pull-up → ein externer Pull-up ist nicht nötig; der Schalter schaltet GPIO9 beim Betätigen sauber gegen `GND`. **Die Bohrung `BTN` dient zugleich als GPIO9-Testpunkt.**
58. **EN/Reset-Testpunkt (CHIP_EN):** Führe das Netz `CHIP_EN` im PCB-Layout auf ein freies, gut zugängliches Test-Pad/Lötpunkt (z. B. Messpunkt 1,0–1,5 mm oder THT-Pad an einer Platinenkante) heraus. Das RC-Netz R5 (10k) + C11 (100n) am CHIP_EN bleibt bestehen; der Testpunkt liegt direkt am CHIP_EN-Knoten (Pull-up-seitig). Damit lässt sich der Reset von außen oder mit dem Tastkopf prüfen/triggern.

---

## TEIL 2 — Production-Checkliste

### ✅ Vor Bestellung / Layout
- [x] CHIP_EN RC: **R5(10k) + C11(100n)** vorhanden
- [x] LDO-Ausgang: **C5(10µ) + C6(100n)** an `3V3` vorhanden
- [x] **Antenne A1 (C293767)** + **π-Matching C14(1,5pF)+L1(2,0nH)+C15(1,5pF)** an LNA_IN vorhanden
- [x] Match-Werte im Espressif-Empfehlungsbereich; bei Bedarf tune (C14/C15→1pF, L1→1,6–2,2nH)
- [x] Mic **LR-Pin (Pin 2)**: U4→GND, U5→3V3 vorhanden (bestätigt: keine I2C-Adresse nötig)
- [x] I2S-SD **R10(100k)** Pulldown vorhanden
- [x] **Switch / Button THT-Lötbohrungen** auf **GPIO9 (`BTN`)** + `GND` (2 durchkontaktierte Löcher/Holes, z. B. Ø 1,0 mm / Pad Ø 1,8 mm zum Durchstecken der Litzen)
- [x] **GPIO9 angeschlossen** (Netz `BTN`; war im Schaltplan unverbunden — behoben)
- [x] **Testpunkte:** GPIO9 via `BTN`-Hole, EN/Reset via `CHIP_EN`-Test-Pad (Layout)
- [x] W25Q128 in **Quad-SPI** (WP→GPIO13, HOLD→GPIO12) vorhanden
- [x] **Akku fest gelötet** — kein JST-Stecker (BT1 entfernt)
- [x] **Akku THT-Lötbohrungen** auf `BAT` + `GND` auf dem PCB (2 durchkontaktierte Löcher/Holes, z. B. Ø 1,0 mm / Pad Ø 1,8 mm zum Durchstecken der Litzen)

### ⚠️ KiCad-Fallen
1. Netzlabels mit **exakten** Pin-Koordinaten (roundet nicht).
2. ESP32-C3-Lib-Bug: Pin 18 VDD_SPI = `power_out` → auf `power_in` patchen.
3. PWR_FLAG an VBUS.
4. Mic-SD → `bidirectional`.
5. Kein String-`replace` auf Koordinaten (korrupt).
6. **PCB-Layout RF:** Matching (C14/L1/C15) dicht an LNA_IN, RF-Leitung kurz (~50Ω-Ziel), **Keep-out (kein Kupfer/keine Bauteile)** unter der Antenne, GND-Vias um die Matching-/Antennen-Zone, Antennen-GND sauber an Pour.
7. **PCB-Layout übrig:** Mic-Bohrung (0.6–0.8 mm) unter Schallport, EPAD-Vias 3×3, Quarz nah an XTAL-Pins.
8. **Kabel- & Lötbohrungen (Akku & Switch):** Durchkontaktierte THT-Löcher (Hole-Ø 1,0 mm) vorsehen, damit die Litzen/Kabel von Akku und Gehäuseschalter durch die Platine gesteckt, sauber verlötet und mechanisch zugentlastet werden können (keine oberflächlichen SMD-Pads).

---

*Re-verified nach externem Fach-Review + Design-Review (2026-08-24). Pin-Zuordnung aus ESP32-C3 Datasheet v2.4 (T2-1/T2-4/T2-7/T2-12) + offizialen KiCad-Symbolen (ICS-43434, LSM6DSL). RF-Matching π-Netz (C14/L1/C15) eingefügt und gegen Espressif Hardware Design Guidelines (C: 1,2–1,8pF, L: 2,0–3,0nH) abgeglichen; Mikrofon-Verdrahtung (I2S, keine I2C-Adresse) bestätigt; GPIO9→`BTN` angeschlossen; EN/GPIO9 als Testpunkte herausgeführt. Alle LCSC-Codes am 2026-08-24 via LCSC/JLCPCB geprüft (C189471/C76769 lagernd). Akku und Switch fest über THT-Lötbohrungen (Holes) verdrahtet, keine großen SMD-Pads.*

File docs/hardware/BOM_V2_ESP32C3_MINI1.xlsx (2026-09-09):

No. | Quantity | Comment | Designator | Footprint | Value | Manufacturer Part | Manufacturer | Supplier Part | Supplier
1 | 7 | CL05B104KO5NNNC | C1,C6,C7,C8,C9,C10,C11 | C0402 |  | CL05B104KO5NNNC | SAMSUNG(三星) | CL05B104KO5NNNC.1 | LCSC
2 | 3 | CL05A106MQ5NUNC | C3,C4,C5 | C0402 |  | CL05A106MQ5NUNC | SAMSUNG(三星) | CL05A106MQ5NUNC.1 | LCSC
3 | 1 | KT-0603R | D1 | LED-SMD_L1.6-W0.8-R-RD |  | KT-0603R | KENTO | KT-0603R.1 | LCSC
4 | 1 | LTST-C190GKT | D2 | LED0603-RD |  | LTST-C190GKT | LITEON(光宝) | LTST-C190GKT.1 | LCSC
5 | 1 | GT-USB-7010ASV | J1 | USB-C-SMD_G-SWITCH_GT-USB-7010ASV |  | GT-USB-7010ASV | G-Switch(品赞) | GT-USB-7010ASV.1 | LCSC
6 | 2 | 0402WGF4701TCE | R2,R3 | R0402 |  | 0402WGF4701TCE | UNI-ROYAL(厚声) | 0402WGF4701TCE.1 | LCSC
7 | 2 | 0402WGF3300TCE | R4,R6 | R0402 |  | 0402WGF3300TCE | UNI-ROYAL(厚声) | 0402WGF3300TCE.1 | LCSC
8 | 1 | 0402WGF1002TCE | R5 | R0402 |  | 0402WGF1002TCE | UNI-ROYAL(厚声) | 0402WGF1002TCE.1 | LCSC
9 | 2 | 0402WGF5101TCE | R7,R8 | R0402 |  | 0402WGF5101TCE | UNI-ROYAL(厚声) | 0402WGF5101TCE.1 | LCSC
10 | 1 | 0402WGF2001TCE | R9 | R0402 |  | 0402WGF2001TCE | UNI-ROYAL(厚声) | 0402WGF2001TCE.1 | LCSC
11 | 1 | 0402WGF1003TCE | R10 | R0402 |  | 0402WGF1003TCE | UNI-ROYAL(厚声) | 0402WGF1003TCE.1 | LCSC
12 | 1 | ESP32-C3-MINI-1-N4 | U1 | WIFIM-SMD_ESP32-C3-MINI-1 |  | ESP32-C3-MINI-1-N4 | ESPRESSIF(乐鑫) | ESP32-C3-MINI-1-N4.1 | LCSC
13 | 1 | W25Q128JVSIQ | U2 | SOIC-8_L5.3-W5.3-P1.27-LS8.0-BL |  | W25Q128JVSIQ | Winbond(华邦) | W25Q128JVSIQTR.1 | LCSC
14 | 1 | LSM6DSLTR | U3 | LGA-14_L3.0-W2.5-P0.50-TL |  | LSM6DSLTR | ST(意法半导体) | LSM6DSLTR.1 | LCSC
15 | 2 | ICS-43434 | U4,U5 | MIC-SMD_6P-L3.5-W2.7-P0.90-BL |  | ICS-43434 | TDK InvenSense(应美盛) | ICS-43434_C5656610.1 | LCSC
16 | 1 | TP4054 | U6 | TSOT-23-5_L2.9-W1.6-P0.95-LS2.8-BR |  | TP4054 | UMW(友台半导体) | TP4054_C668215.1 | LCSC
17 | 1 | AP2112K-3.3TRG1 | U7 | SOT-25-5_L2.9-W1.6-P0.95-LS2.8-BL |  | AP2112K-3.3TRG1 | DIODES(美台) | C51118 | LCSC

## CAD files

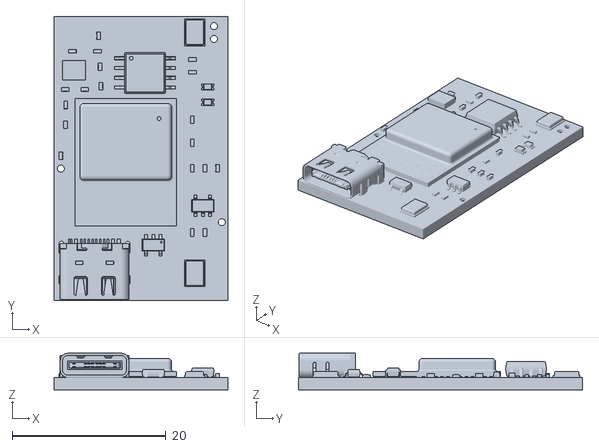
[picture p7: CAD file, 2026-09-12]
research/3D_PCB1_2026-09-08.stl
22.6 x 37.0 x 4.76

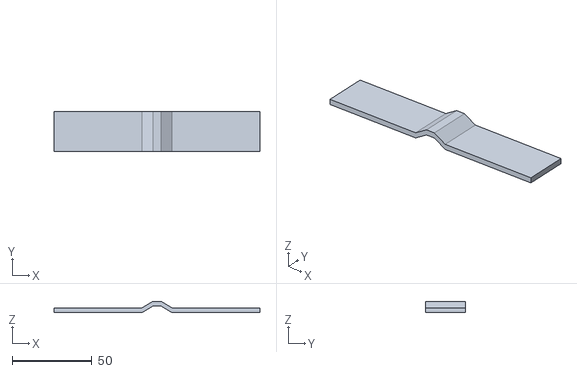
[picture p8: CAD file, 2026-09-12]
research/enclosure/_bm.stl
129.0 x 24.8 x 7.20

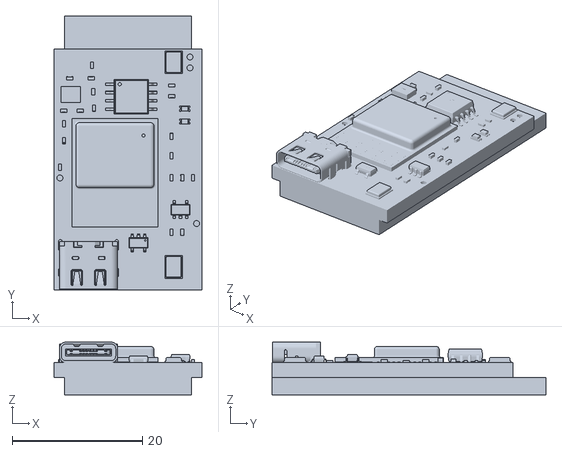
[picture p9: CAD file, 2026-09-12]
research/enclosure_302040/pcb_302040_battery.stl
22.6 x 42.0 x 8.11

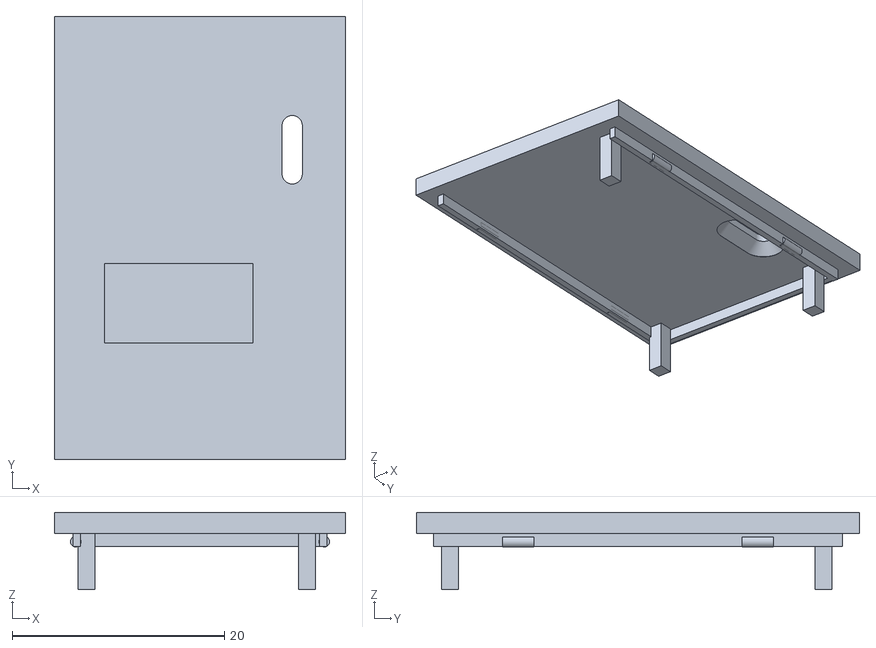
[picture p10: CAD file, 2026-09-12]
research/enclosure/lid.stl
27.4 x 41.8 x 7.26

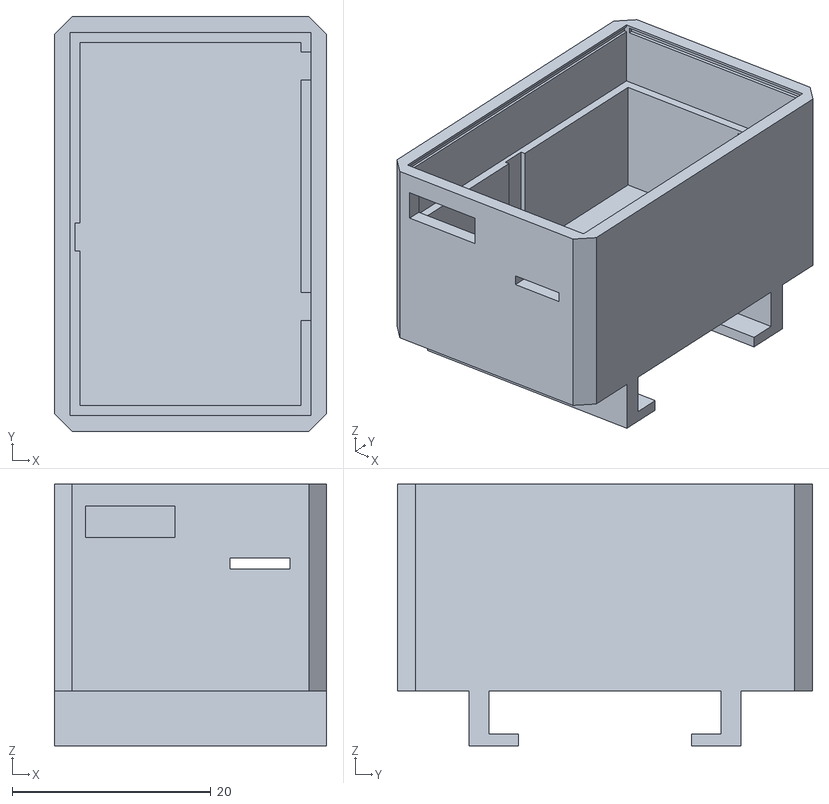
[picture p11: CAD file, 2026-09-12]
research/enclosure/stl/tray90_print.stl
27.4 x 41.8 x 26.3

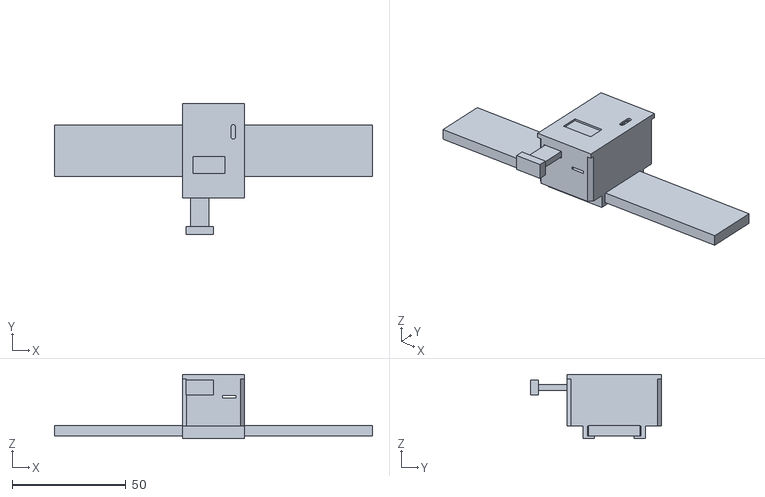
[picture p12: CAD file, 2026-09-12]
research/enclosure/_chk.stl
140.0 x 57.8 x 28.3

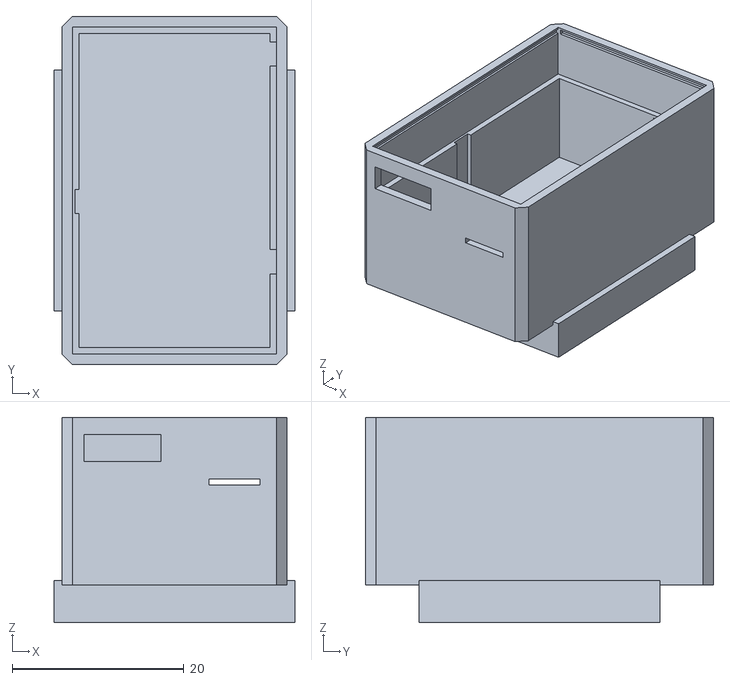
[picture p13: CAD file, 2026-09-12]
research/enclosure/stl/v3_A_slim_tray.stl
28.1 x 40.6 x 23.9

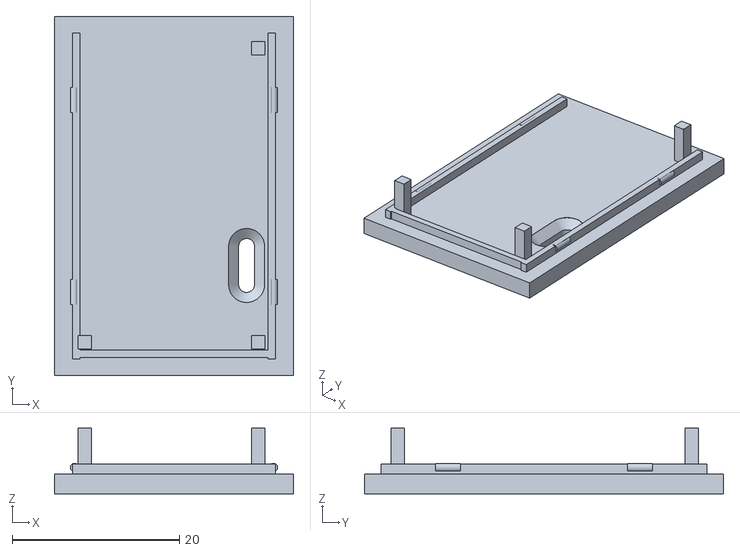
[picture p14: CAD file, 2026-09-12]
research/enclosure/stl/v3_C_robust_lid_print.stl
28.6 x 43.0 x 7.86

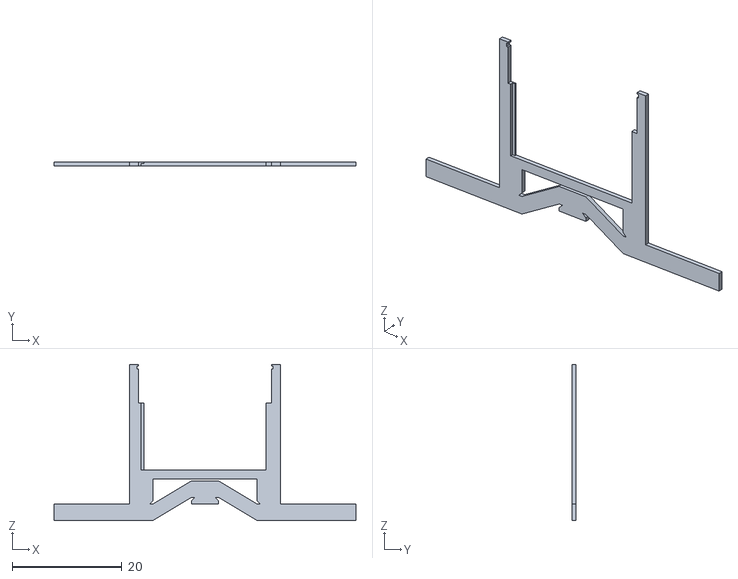
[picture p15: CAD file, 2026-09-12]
research/enclosure/w.stl
55.0 x 0.7 x 28.4

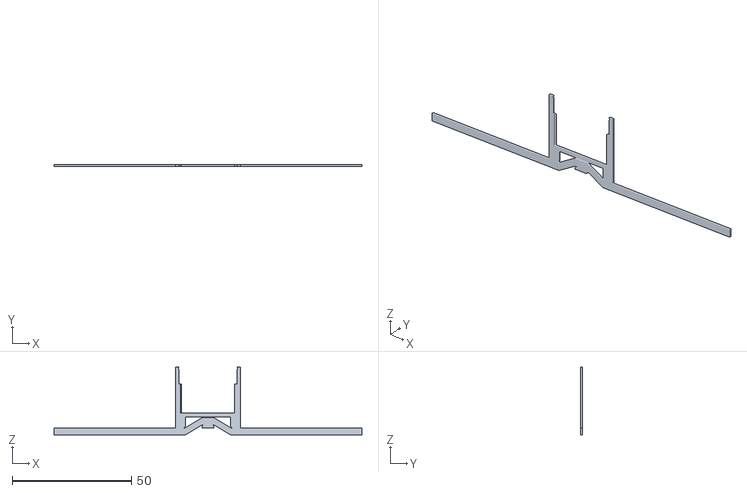
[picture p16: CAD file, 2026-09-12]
research/enclosure/sec_test.stl
129.0 x 0.7 x 28.4

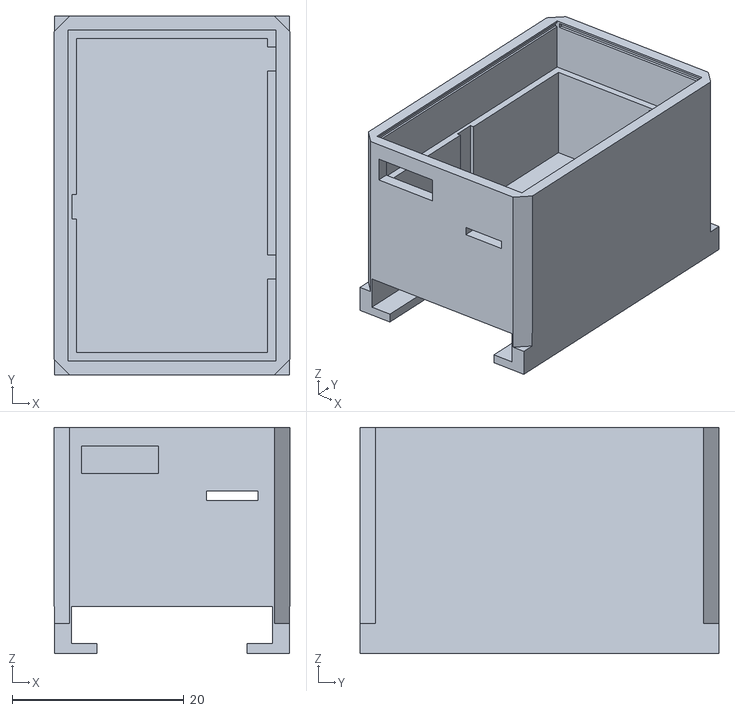
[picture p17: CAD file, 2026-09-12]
research/enclosure/stl/tray.stl
27.4 x 41.8 x 26.3

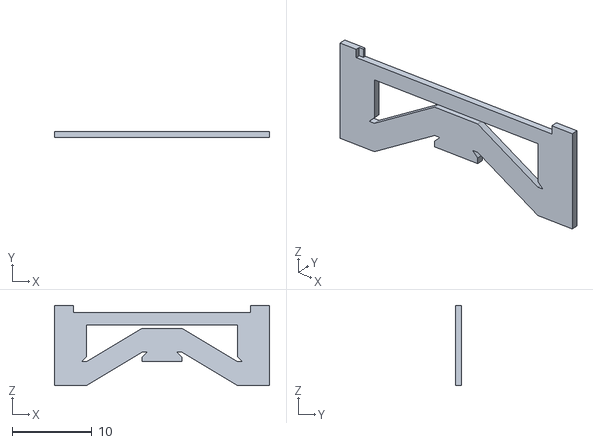
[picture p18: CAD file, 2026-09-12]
research/enclosure/z.stl
27.0 x 0.7 x 10.1

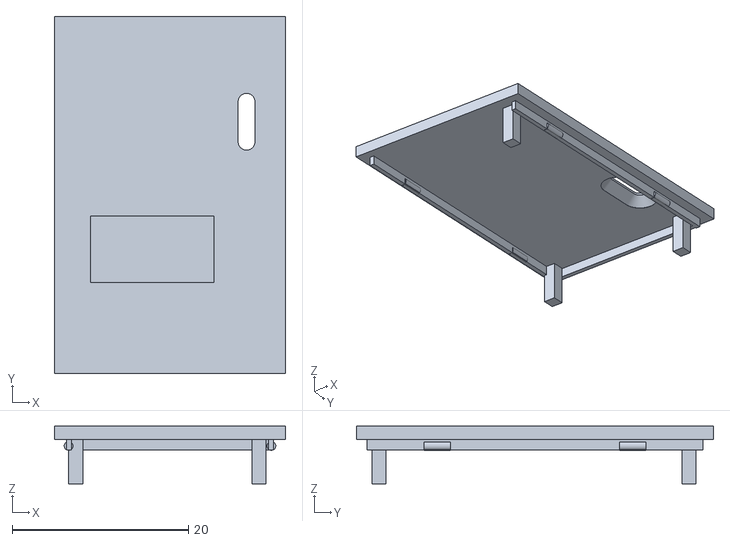
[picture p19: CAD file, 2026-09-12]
research/enclosure/stl/v3_A_slim_lid.stl
26.2 x 40.6 x 6.56

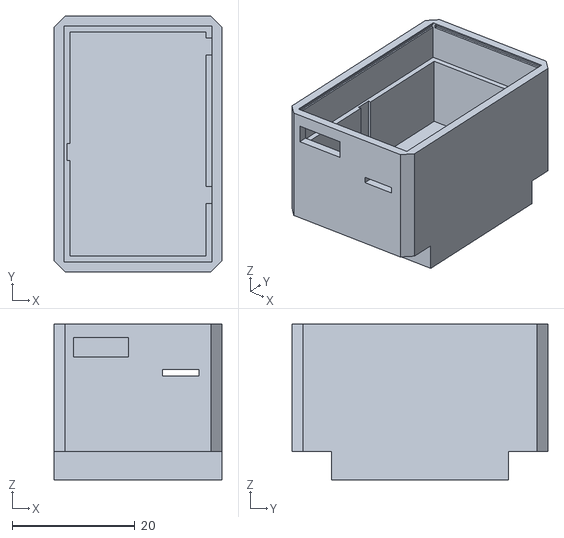
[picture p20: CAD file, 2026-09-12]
research/enclosure/stl/tray90_thread.stl
27.4 x 41.8 x 25.4

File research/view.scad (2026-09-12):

import("C:/Users/MGasc/Documents/antigravity/optimistic-hubble/research/3D_PCB1_2026-09-08.stl", convexity=10);

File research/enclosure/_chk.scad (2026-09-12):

wall=2.0; b3_clr=0.40; b3_plate=1.6;
part = "info";
include <audio_vault_case.scad>;

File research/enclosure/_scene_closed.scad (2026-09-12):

color("SteelBlue") tray("cassette");
color("Gainsboro") lid();

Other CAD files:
research/enclosure/stl/lid_print.stl
research/enclosure/stl/v3_A_slim_lid_print.stl
research/enclosure/stl/tray_print.stl
research/enclosure/_scene_fold.scad
research/enclosure/_scene_open.scad
research/enclosure/audio_vault_case.scad
research/enclosure/render.scad
research/enclosure/stl/tray90.stl
research/enclosure/stl/v3_A_slim_tray_print.stl
research/enclosure/stl/v3_B_standard_lid.stl
research/enclosure/stl/v3_B_standard_lid_print.stl
research/enclosure/stl/v3_B_standard_tray.stl
research/enclosure/stl/v3_B_standard_tray_print.stl
research/enclosure/stl/v3_C_robust_lid.stl
research/enclosure/stl/v3_C_robust_tray.stl
research/enclosure/stl/v3_C_robust_tray_print.stl
research/enclosure/zz.scad

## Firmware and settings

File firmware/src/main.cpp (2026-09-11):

#include <Arduino.h>
#include "config.h"
#include "i2c_scanner.h"
#include "imu_driver.h"
#include "i2s_mic_driver.h"
#include "tap_detector.h"
#include "shake_detector.h"
#include "audio_recorder.h"
#include "storage_manager.h"
#include "ble_manager.h"
#include "wifi_server.h"
#include "wifi_uploader.h"
#include "power_manager.h"
#include "battery_manager.h"
#include "led_indicator.h"
#include "spi_flash_driver.h"

// Global Hardware Modules
static ImuDriver imu;
static I2sMicDriver stereoMic;
static TapDetector tapDetector(TAP_JERK_THRESHOLD_G, TAP_DEBOUNCE_MS, DOUBLE_TAP_WINDOW_MIN_MS, DOUBLE_TAP_WINDOW_MAX_MS);
static ShakeDetector shakeDetector(SHAKE_THRESHOLD_G, SHAKE_WINDOW_MS, SHAKE_REVERSALS_REQUIRED, SHAKE_COOLDOWN_MS);
static LedIndicator leds(PIN_STATUS_LED, PIN_LED_GREEN);
static AudioRecorder recorder(0xFF); // LED indicator managed exclusively by LedIndicator
static StorageManager storage;
static SpiFlashDriver extFlash(PIN_FLASH_SCK, PIN_FLASH_MISO, PIN_FLASH_MOSI, PIN_FLASH_CS);
static BleManager ble(&leds);
static WifiServerManager wifiServer(storage, &leds);
static WifiUploader wifiUploader(storage, &leds);
static PowerManager power;
static BatteryManager battery;
static uint16_t totalTapEvents = 0;

static unsigned long lastTelemetryTime = 0;
static const unsigned long TELEMETRY_INTERVAL_MS = 100; // 10 Hz real-time telemetry stream

static unsigned long lastImuPollTime = 0;
static const unsigned long IMU_POLL_INTERVAL_MS = 20; // 50 Hz tap polling

static unsigned long lastButtonCheckTime = 0;
static bool lastButtonState = HIGH;

void printBanner() {
    Serial.println(F("\n========================================================"));
    Serial.println(F("  Audio Vault (Custom Production PCB V2)"));
    Serial.println(F("  ESP32-C3-MINI-1-N4 * Dual ICS-43434 * LSM6DSL IMU"));
    Serial.println(F("  Winbond W25Q128 16MB SPI Flash * TP4054 / AP2112K"));
    Serial.println(F("========================================================"));
}

void printSystemSummary() {
    printBanner();
    Serial.printf("[SYSTEM] Wake-up Cause: %s\n", power.getWakeupReasonString());
    Serial.printf("  IMU: %s @ 0x%02X\n", imu.getChipName(), imu.getAddress());
    Serial.printf("  Storage: %s (%u MB total) | Clips: %u | Free: %u KB\n",
                  storage.isExternalFlash() ? "External 16MB SPI Flash" : "Internal Flash",
                  (unsigned int)(storage.getTotalBytes() / (1024 * 1024)),
                  (unsigned int)storage.getClipCount(),
                  (unsigned int)((storage.getTotalBytes() - storage.getUsedBytes()) / 1024));
    Serial.printf("  Battery: %u mV (%u%%, %s) | Heap Free: %u bytes\n",
                  battery.getVoltageMilliVolts(), battery.getPercent(),
                  battery.isCharging() ? "Charging" : "Discharging",
                  ESP.getFreeHeap());
    Serial.printf("  BLE: %s | Wi-Fi SoftAP: %s | Service Mode: %s\n",
                  ble.isConnected() ? "Connected" : "Advertising",
                  wifiServer.isActive() ? "ON" : "OFF",
                  power.isSleepPrevented() ? "ENABLED" : "DISABLED");
    Serial.println(F("========================================================"));
    Serial.println(F("  Commands via Serial Monitor:"));
    Serial.println(F("    [r] -> Restart MCU (Software Reset)"));
    Serial.println(F("    [b] -> Reprint this System Summary / Banner"));
    Serial.println(F("    [w] -> Toggle Wi-Fi SoftAP"));
    Serial.println(F("    [s] -> Toggle Recording Start/Stop"));
    Serial.println(F("========================================================\n"));
}

void pushTelemetryUpdate(DeviceState state, uint32_t audioBytes = 0) {
    if (!ble.isConnected()) return;

    ImuMetricData imuMetrics{};
    bool hasImu = imu.readSensorData(imuMetrics);
    float mag = hasImu 
        ? sqrtf(imuMetrics.accelX_g * imuMetrics.accelX_g + 
                imuMetrics.accelY_g * imuMetrics.accelY_g + 
                imuMetrics.accelZ_g * imuMetrics.accelZ_g)
        : 1.0f;

    battery.update(state, power.isUsbConnected());

    ble.sendTelemetry(
        state,
        audioBytes,
        recorder.getSampleRate(),
        battery.getVoltageMilliVolts(),
        battery.getPercent(),
        battery.isCharging(),
        ESP.getFreeHeap(),
        storage.getUsedBytes(),
        storage.getTotalBytes(),
        storage.getClipCount(),
        (int16_t)(imuMetrics.accelX_g * 1000.0f),
        (int16_t)(imuMetrics.accelY_g * 1000.0f),
        (int16_t)(imuMetrics.accelZ_g * 1000.0f),
        (uint16_t)(mag * 1000.0f),
        totalTapEvents
    );
}

void startActiveRecording() {
    power.notifyActivity();

    AudioQuality quality = storage.getQuality();
    uint32_t micRate = (quality == QUALITY_LOW) ? 8000 : AUDIO_SAMPLE_RATE;

    // 1. Start Stereo I2S Microphones on-demand
    if (!stereoMic.isInitialized() || stereoMic.getSampleRate() != micRate) {
        stereoMic.begin(PIN_I2S_SCK, PIN_I2S_WS, PIN_I2S_SD, micRate);
    }

    // 2. Ensure IMU is in normal high-performance mode
    imu.setPowerMode(true);

    // 3. Start Recording Clip and set LED indicator
    uint16_t nextId = storage.getNextClipId();
    storage.recordClipTimestamp(nextId);
    recorder.startRecording(nextId, quality);
    leds.setMode(ble.isConnected() ? LedMode::RECORDING_CONNECTED : LedMode::RECORDING);
    pushTelemetryUpdate(STATE_RECORDING, 0);

    Serial.printf("\n[RECORD START] Clip #%u recording started (Quality: %u, Rate: %u Hz)!\n",
                  nextId, (unsigned int)quality, (unsigned int)micRate);
}

static unsigned long postRecordingGracePeriodEnd = 0;

void handleStopAndSave() {
    recorder.stopRecording();
    
    // Stop I2S to save microphone power
    stereoMic.stop();

    // Prevent immediate return to deep sleep: guarantee 15s awake after recording stops
    postRecordingGracePeriodEnd = millis() + 15000UL;
    power.notifyActivity();

    // Update LED mode according to current connectivity
    leds.setMode(wifiServer.isActive() ? LedMode::WIFI_AP : (ble.isConnected() ? LedMode::BLE_CONNECTED : LedMode::IDLE));

    storage.refresh();
    size_t totalClips = storage.getClipCount();
    uint16_t clipId = recorder.getCurrentClipId();

    Serial.printf("\n[RECORD STOP] Clip #%u saved! Total in Flash: %u (Free: %u KB)\n", 
                  clipId, totalClips, (storage.getTotalBytes() - storage.getUsedBytes()) / 1024);
    Serial.println(F("[POWER] Post-recording 15s stay-awake grace period started."));

    pushTelemetryUpdate(STATE_DONE, 0);
}

void setup() {
    // 1. Boot Power Manager & Inspect Wake-up Reason
    power.begin();
    battery.begin();

    Serial.begin(SERIAL_BAUD_RATE);
    if (power.isUsbConnected()) {
        unsigned long start = millis();
        while (!Serial && (millis() - start < 300)) delay(10);
    }
    delay(20); // Small buffer flush delay for CDC enumeration

    printBanner();
    Serial.printf("[SYSTEM] Wake-up Cause: %s\n", power.getWakeupReasonString());

    // 2. Configure Hardware Pins & Dual Status LEDs
    pinMode(PIN_BOOT_BTN, INPUT_PULLUP);
    pinMode(PIN_IMU_INT, INPUT_PULLDOWN);
    leds.begin();

    // 3. Initialize I2C & IMU (ST LSM6DSL)
    I2cScanner::begin(PIN_I2C_SDA, PIN_I2C_SCL, I2C_FREQUENCY);
    delay(20);
    bool imuOk = imu.begin();
    if (imuOk) {
        Serial.printf("  [PASS] Identified IMU: %s @ 0x%02X\n", imu.getChipName(), imu.getAddress());
        // Clear any latched wake-up / tap interrupts to reset INT1 pin
        imu.clearInterrupts();
    } else {
        Serial.println(F("  [WARN] IMU not found! Tap detection may be inactive."));
    }

    // 4. Initialize External SPI2 Flash Storage (Winbond W25Q128 16MB)
    bool extFlashOk = extFlash.begin();
    if (extFlashOk) {
        Serial.printf("  [PASS] External SPI2 Flash ready: %s (%u MB)\n", 
                      extFlash.getChipName(), (unsigned int)(extFlash.getCapacityBytes() / (1024 * 1024)));
    } else {
        Serial.println(F("  [INFO] External SPI2 Flash not detected or optional."));
    }

    // 5. Initialize Storage (Mount LittleFS on 16MB External Flash if available)
    bool fsOk = storage.begin(&extFlash, true);
    if (fsOk) {
        Serial.printf("  [PASS] %s ready (%u MB). Clips: %u | Free: %u KB\n",
                      storage.isExternalFlash() ? "External 16MB SPI Flash Storage" : "Internal Flash Storage",
                      (unsigned int)(storage.getTotalBytes() / (1024 * 1024)),
                      (unsigned int)storage.getClipCount(),
                      (unsigned int)((storage.getTotalBytes() - storage.getUsedBytes()) / 1024));
    } else {
        Serial.println(F("  [FAIL] Could not mount LittleFS Storage!"));
    }

    // 6. Initialize Audio Recorder
    bool recOk = recorder.begin();
    if (recOk) {
        Serial.println(F("  [PASS] Stream Recorder ready."));
    }

    // 7. Initialize BLE GATT Server
    bool bleOk = ble.begin(BLE_DEVICE_NAME);
    if (bleOk) {
        Serial.printf("  [PASS] BLE advertising active as \"%s\".\n", BLE_DEVICE_NAME);
    }

    // 8. Handle Wake-up Routing & LED Sequence
    if (power.wasWokenByMotion()) {
        ImuMetricData bootImu{};
        bool hasBootImu = imu.readSensorData(bootImu);
        if (hasBootImu) {
            shakeDetector.initializeBaseline(bootImu);
        }
        bool isArmUp = hasBootImu && (bootImu.accelY_g <= IMU_ARM_UP_Y_THRESHOLD_G);

        if (isArmUp) {
            Serial.printf("\n  >>> Woken from Deep Sleep with ARM UP / TILT (Y=%+.2f g)! <<<\n", bootImu.accelY_g);
            Serial.println(F("  >>> Arm-Up / Tilt Wakeup detected -> Red LED blinking for 2 seconds!\n"));
            leds.showTiltFeedback();
        } else {
            Serial.printf("\n  >>> Woken from Deep Sleep with ARM DOWN (Y=%+.2f g). <<<\n", 
                          hasBootImu ? bootImu.accelY_g : 0.0f);
            Serial.println(F("  >>> MCU is now AWAKE (IDLE). Shake with arm UP to START recording."));
            Serial.println(F("  >>> (Device will return to Deep Sleep if idle for 15s)\n"));
        }
        leds.setMode(LedMode::IDLE);
    } else {
        leds.bootSequence();
        leds.setMode(LedMode::IDLE);
        Serial.println(F("\n========================================================"));
        Serial.println(F("  READY:"));
        Serial.println(F("  1. Shake device with ARM DOWN to WAKE from Deep Sleep."));
        Serial.println(F("  2. Shake device with ARM UP (Y-axis ~ -1g) to START recording."));
        Serial.println(F("  3. Shake device in ANY orientation to STOP recording."));
        Serial.println(F("  4. Press BTN button to toggle Wi-Fi, hold 2s for Flash Mode."));
        Serial.println(F("  5. Connect USB to keep permanently awake."));
        Serial.println(F("========================================================\n"));
    }
}

void loop() {
    unsigned long now = millis();

    // 0. Tick LED Indicator Animation/Blinking
    leds.update();

    // 0.1 Handle Serial Input Commands (r = restart, b = summary banner, w = toggle wifi, s = toggle record)
    while (Serial.available() > 0) {
        char ch = (char)Serial.read();
        if (ch == 'r' || ch == 'R') {
            Serial.println(F("\n[SERIAL] Restart command received -> Rebooting ESP32-C3 now..."));
            Serial.flush();
            delay(200);
            ESP.restart();
        } else if (ch == 'b' || ch == 'B' || ch == '?') {
            power.notifyActivity();
            printSystemSummary();
        } else if (ch == 'w' || ch == 'W') {
            power.notifyActivity();
            if (wifiServer.isActive()) {
                Serial.println(F("\n[SERIAL] Stopping Wi-Fi SoftAP..."));
                wifiServer.stop();
                leds.setMode(ble.isConnected() ? LedMode::BLE_CONNECTED : LedMode::IDLE);
                ble.updateState(STATE_IDLE);
            } else {
                Serial.println(F("\n[SERIAL] Starting Wi-Fi SoftAP..."));
                wifiServer.begin(WIFI_AP_SSID, WIFI_AP_PASS, HTTP_SERVER_PORT);
                leds.setMode(LedMode::WIFI_AP);
                ble.updateState(STATE_WIFI_ACTIVE);
            }
        } else if (ch == 's' || ch == 'S') {
            power.notifyActivity();
            if (recorder.isRecording()) {
                Serial.println(F("\n[SERIAL] Stopping recording..."));
                handleStopAndSave();
            } else {
                Serial.println(F("\n[SERIAL] Starting recording..."));
                startActiveRecording();
            }
        }
    }

    // 1. Process Active Real-Time Recording Stream
    if (recorder.isRecording()) {
        bool stillRecording = recorder.processRecording(stereoMic);

        // Check IMU for stop shake gesture at a clean 50 Hz interval
        if (now - lastImuPollTime >= IMU_POLL_INTERVAL_MS) {
            lastImuPollTime = now;

            ImuMetricData imuData;
            if (imu.readSensorData(imuData)) {
                float intensity = 0.0f;
                ShakeEventType shakeEvt = shakeDetector.update(imuData, &intensity);
                if (shakeEvt == ShakeEventType::SHAKE_DETECTED) {
                    totalTapEvents++;
                    Serial.printf("\n[SHAKE DETECTED] Stop trigger! Intensity: %.2f g -> STOPPING RECORDING...\n", intensity);
                    ble.notifyTap(intensity);
                    handleStopAndSave();
                }
            }
        }

        if (!stillRecording) {
            handleStopAndSave();
        }
    }

    // 2. Check Remote BLE Commands
    if (ble.hasPendingCommand()) {
        BleCommand cmd = ble.getPendingCommand();
        power.notifyActivity();

        switch (cmd) {
            case CMD_START_WIFI:
                Serial.printf("\n[BLE CMD] Start Wi-Fi Hotspot requested! (Current SoftAP: %s)\n",
                              wifiServer.isActive() ? "ALREADY RUNNING" : "STARTING");
                if (!wifiServer.isActive()) {
                    wifiServer.begin(WIFI_AP_SSID, WIFI_AP_PASS, HTTP_SERVER_PORT);
                }
                leds.setMode(LedMode::WIFI_AP);
                ble.updateState(STATE_WIFI_ACTIVE);
                break;

            case CMD_STOP_WIFI:
                Serial.printf("\n[BLE CMD] Stop Wi-Fi Hotspot requested! (Current SoftAP: %s)\n",
                              wifiServer.isActive() ? "ACTIVE" : "ALREADY OFF");
                if (wifiServer.isActive()) {
                    wifiServer.stop();
                }
                leds.setMode(ble.isConnected() ? LedMode::BLE_CONNECTED : LedMode::IDLE);
                ble.updateState(STATE_IDLE);
                break;

            case CMD_ENTER_SLEEP:
                Serial.println(F("\n[BLE CMD] Entering Deep Sleep upon user request..."));
                ble.updateState(STATE_SLEEPING);
                leds.turnOffAll();
                delay(100);
                power.enterDeepSleep(imu, &extFlash, IMU_WAKEUP_THRESHOLD_G);
                return;

            case CMD_START_RECORDING:
                if (!recorder.isRecording()) {
                    Serial.println(F("\n[BLE CMD] Start Recording requested..."));
                    startActiveRecording();
                }
                break;

            case CMD_STOP_RECORDING:
                if (recorder.isRecording()) {
                    Serial.println(F("\n[BLE CMD] Stop Recording requested..."));
                    handleStopAndSave();
                }
                break;

            case CMD_CLEAR_STORAGE:
                Serial.println(F("\n[BLE CMD] Clearing all audio clips from Flash..."));
                storage.clearAll();
                storage.refresh();
                ble.updateState(STATE_IDLE);
                break;

            case CMD_START_L2CAP_STREAM:
                Serial.printf("\n[BLE CMD] Start audio stream for clip #%u (Offset: %lu)...\n",
                              ble.getCommandClipId(), ble.getCommandOffset());
                ble.streamAudioFileFromStorage(ble.getCommandClipId(), ble.getCommandOffset());
                break;

            case CMD_CONNECT_HOTSPOT:
            {
                HotspotUploadConfig cfg = ble.getHotspotUploadConfig();
                Serial.printf("\n[BLE CMD] Connecting to Phone Hotspot \"%s\" for High-Speed Audio Upload...\n", cfg.ssid);
                ble.updateState(STATE_TRANSFERRING);
                leds.setMode(LedMode::SYNCING);
                bool uploadOk = wifiUploader.uploadClips(cfg);
                storage.refresh();
                ble.updateState(uploadOk ? STATE_DONE : STATE_IDLE, 0, AUDIO_SAMPLE_RATE);
                delay(100);
                ble.updateState(STATE_IDLE);
                leds.setMode(ble.isConnected() ? LedMode::BLE_CONNECTED : LedMode::IDLE);
                break;
            }

            case CMD_DELETE_CLIP:
            {
                uint16_t clipId = ble.getCommandClipId();
                Serial.printf("\n[BLE CMD] Delete Clip #%u requested from Flash...\n", clipId);
                bool ok = storage.deleteClip(clipId);
                storage.refresh();
                Serial.printf("[BLE CMD] Delete Clip #%u %s. Remaining clips in Flash: %u (Free: %u KB)\n",
                              clipId, ok ? "SUCCESSFUL" : "NOT FOUND",
                              storage.getClipCount(),
                              (storage.getTotalBytes() - storage.getUsedBytes()) / 1024);
                break;
            }

            case CMD_SET_QUALITY:
            {
                AudioQuality newQuality = (AudioQuality)ble.getCommandParam();
                if (newQuality <= QUALITY_LOW) {
                    storage.setQuality(newQuality);
                    const char* qName = (newQuality == QUALITY_HIGH) ? "High (16kHz PCM)" :
                                        ((newQuality == QUALITY_LOW) ? "Low (8kHz ADPCM)" : "Medium (16kHz ADPCM)");
                    Serial.printf("\n[BLE CMD] Audio Recording Quality set to %u (%s)\n",
                                  (unsigned int)newQuality, qName);
                    pushTelemetryUpdate(recorder.isRecording() ? STATE_RECORDING : STATE_IDLE);
                }
                break;
            }

            default:
                break;
        }
    }

    // 3. Check Boot Button (GPIO 9 / BTN) for Wi-Fi Toggle (short press) or Flash Mode (long press >= 2s)
    static unsigned long buttonPressStartTime = 0;
    static bool buttonIsHeld = false;
    static bool longPressHandled = false;

    if (now - lastButtonCheckTime >= 20) {
        lastButtonCheckTime = now;
        bool btnState = digitalRead(PIN_BOOT_BTN);
        if (lastButtonState == HIGH && btnState == LOW) {
            // Button pressed down (Active LOW)
            buttonPressStartTime = now;
            buttonIsHeld = true;
            longPressHandled = false;
            power.notifyActivity();
        } else if (lastButtonState == LOW && btnState == LOW) {
            // Button being held down
            if (buttonIsHeld && !longPressHandled && (now - buttonPressStartTime >= 2000)) {
                longPressHandled = true;
                bool newPrevent = !power.isSleepPrevented();
                power.setPreventSleep(newPrevent);
                Serial.printf("\n[BUTTON] Long press! Service/Flash Mode: %s\n", 
                              newPrevent ? "ACTIVATED (Deep Sleep permanently locked off)" : "DEACTIVATED (Auto Deep Sleep restored)");
                if (newPrevent) {
                    leds.setMode(LedMode::SERVICE_MODE);
                } else {
                    leds.setMode(ble.isConnected() ? LedMode::BLE_CONNECTED : LedMode::IDLE);
                }
            }
        } else if (lastButtonState == LOW && btnState == HIGH) {
            // Button released
            buttonIsHeld = false;
            if (!longPressHandled) {
                // Short press: Toggle Wi-Fi SoftAP
                power.notifyActivity();
                if (wifiServer.isActive()) {
                    Serial.println(F("[BUTTON] Short press: Toggling Wi-Fi OFF..."));
                    wifiServer.stop();
                    leds.setMode(ble.isConnected() ? LedMode::BLE_CONNECTED : (power.isSleepPrevented() ? LedMode::SERVICE_MODE : LedMode::IDLE));
                    ble.updateState(STATE_IDLE);
                } else {
                    Serial.println(F("[BUTTON] Short press: Toggling Wi-Fi ON..."));
                    wifiServer.begin(WIFI_AP_SSID, WIFI_AP_PASS, HTTP_SERVER_PORT);
                    leds.setMode(LedMode::WIFI_AP);
                    ble.updateState(STATE_WIFI_ACTIVE);
                }
            }
        }
        lastButtonState = btnState;
    }

    // 4. IDLE State: Handle WebServer, DNS requests, and SoftAP Watchdog (if Wi-Fi active)
    if (wifiServer.isActive()) {
        wifiServer.handleClient();
        wifiServer.checkWatchdog();
        power.notifyActivity();
    }

    // 5. IDLE State: Monitor IMU for Start Shake Gesture (when not recording and awake)
    if (!recorder.isRecording() && (now - lastImuPollTime >= IMU_POLL_INTERVAL_MS)) {
        lastImuPollTime = now;

        ImuMetricData imuData;
        if (imu.readSensorData(imuData)) {
            float intensity = 0.0f;
            ShakeEventType shakeEvt = shakeDetector.update(imuData, &intensity);
            if (shakeEvt == ShakeEventType::SHAKE_DETECTED) {
                totalTapEvents++;
                power.notifyActivity();
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

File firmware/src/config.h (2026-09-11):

#pragma once
#include <Arduino.h>

// ============================================================================
// Hardware Pinout for ESP32-C3-MINI-1-N4 (V2 Production Design)
// ============================================================================

// I2C Pins for 6-Axis IMU (ST LSM6DSLTR, U3)
#define PIN_I2C_SDA 6 // GPIO 6 (Module Pin 19) + 4.7k Pull-up to 3V3
#define PIN_I2C_SCL 7 // GPIO 7 (Module Pin 20) + 4.7k Pull-up to 3V3
#define I2C_FREQUENCY 400000UL

// IMU Hardware Interrupt Wakeup Pin (RTC GPIO 5) & Push Button (GPIO 9)
#define PIN_IMU_INT 5  // GPIO 5 (Module Pin 18, RTC IO5, Deep Sleep Wakeup from INT1)
#define PIN_BOOT_BTN 9 // GPIO 9 (Module Pin 22, THT BTN Switch against GND)

// I2S Stereo Microphone Pins (TDK InvenSense ICS-43434, U4 & U5)
#define PIN_I2S_SCK 2          // GPIO 2 (Module Pin 5, Bit Clock)
#define PIN_I2S_WS 3           // GPIO 3 (Module Pin 6, Word Select / LRCLK)
#define PIN_I2S_SD 4           // GPIO 4 (Module Pin 17, Serial Data In + 100k Pulldown)
#define I2S_BUFFER_SAMPLES 256 // Number of stereo sample frames per read

// External Status LEDs (D1 Red, D2 Green - Active LOW: Anode to 3V3, Cathode to GPIO via 330R)
#define PIN_STATUS_LED 10 // GPIO 10 (Module Pin 16) = Red Status LED (D1, Recording)
#define PIN_LED_GREEN 8   // GPIO 8  (Module Pin 21) = Green Status LED (D2, System/Wi-Fi)
#define LED_LEVEL_ON  LOW
#define LED_LEVEL_OFF HIGH

// External SPI Flash Pins (Winbond W25Q128JVSIQ 16MB Audio Storage on SPI2 / FSPI)
// Empirically verified on PCB V2 hardware routing:
// CS=GPIO 21, SCK=GPIO 0, MOSI=GPIO 20, MISO=GPIO 1
#define PIN_FLASH_CS 21   // GPIO 21 (Module Pin 28) = /CS (Chip Select)
#define PIN_FLASH_SCK 0   // GPIO 0  (Module Pin 12) = CLK (Clock)
#define PIN_FLASH_MOSI 20 // GPIO 20 (Module Pin 27) = DI (Serial Data In)
#define PIN_FLASH_MISO 1  // GPIO 1  (Module Pin 13) = DO (Serial Data Out)

// Serial Baud Rate
#define SERIAL_BAUD_RATE 115200

// ============================================================================
// Ultra-Low-Power & Deep Sleep Parameters
// ============================================================================
#define INACTIVITY_SLEEP_TIMEOUT_MS 15000UL // 15 seconds of idle inactivity before Deep Sleep
#define WIFI_INACTIVITY_TIMEOUT_MS 120000UL // 2 minutes of idle Wi-Fi -> Stop SoftAP to save ~150 mA
#define IMU_WAKEUP_THRESHOLD_G 1.4f         // Hardware shock acceleration threshold
#define ENABLE_DEEP_SLEEP_AUTO true         // Deep Sleep enabled for battery saving

// ============================================================================
// Audio Recording & Preamp Parameters
// ============================================================================
#define AUDIO_SAMPLE_RATE 16000  // 16 kHz Voice sampling rate
#define MIC_GAIN_MULTIPLIER 8.0f // +18 dB Digital Preamp Gain (Crisp, loud & full-scale voice)

// ============================================================================
// Tap & Double-Tap Detection Parameters
// ============================================================================
#define TAP_JERK_THRESHOLD_G 0.55f    // Shock delta acceleration threshold in g
#define TAP_DEBOUNCE_MS 120           // Minimum time between raw tap triggers (ms)
#define DOUBLE_TAP_WINDOW_MIN_MS 120  // Minimum interval between 1st and 2nd tap (debounce)
#define DOUBLE_TAP_WINDOW_MAX_MS 650  // Maximum interval between 1st and 2nd tap for valid double tap

// ============================================================================
// Shake Gesture Parameters (for Recording Start/Stop)
// ============================================================================
#define SHAKE_THRESHOLD_G 1.60f        // Dynamic acceleration threshold in g
#define SHAKE_WINDOW_MS 650            // Time window for shake reversals (ms)
#define SHAKE_REVERSALS_REQUIRED 2     // Minimum direction reversals to qualify as shake
#define SHAKE_COOLDOWN_MS 1200         // Cooldown after trigger before next shake (ms)

// Orientation Threshold: Y-axis points downwards (-1g Earth gravity) when arm is raised
// Arm raised: accelY_g <= -0.50g
#define IMU_ARM_UP_Y_THRESHOLD_G -0.50f

// ============================================================================
// Wi-Fi High-Speed Audio Server Parameters
// ============================================================================
#define WIFI_AP_SSID "Audio-Vault-Hotspot"
#define WIFI_AP_PASS "audiovault2026" // WPA2 Passphrase (>= 8 chars)
#define HTTP_SERVER_PORT 80
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

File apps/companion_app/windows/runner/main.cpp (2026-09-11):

#include <flutter/dart_project.h>
#include <flutter/flutter_view_controller.h>
#include <windows.h>

#include "flutter_window.h"
#include "utils.h"

int APIENTRY wWinMain(_In_ HINSTANCE instance, _In_opt_ HINSTANCE prev,
                      _In_ wchar_t *command_line, _In_ int show_command) {
  // Attach to console when present (e.g., 'flutter run') or create a
  // new console when running with a debugger.
  if (!::AttachConsole(ATTACH_PARENT_PROCESS) && ::IsDebuggerPresent()) {
    CreateAndAttachConsole();
  }

  // Initialize COM, so that it is available for use in the library and/or
  // plugins.
  ::CoInitializeEx(nullptr, COINIT_APARTMENTTHREADED);

  flutter::DartProject project(L"data");

  std::vector<std::string> command_line_arguments =
      GetCommandLineArguments();

  project.set_dart_entrypoint_arguments(std::move(command_line_arguments));

  FlutterWindow window(project);
  Win32Window::Point origin(10, 10);
  Win32Window::Size size(1280, 800);
  if (!window.Create(L"Audio Vault Companion", origin, size)) {
    return EXIT_FAILURE;
  }
  window.SetQuitOnClose(true);

  ::MSG msg;
  while (::GetMessage(&msg, nullptr, 0, 0)) {
    ::TranslateMessage(&msg);
    ::DispatchMessage(&msg);
  }

  ::CoUninitialize();
  return EXIT_SUCCESS;
}

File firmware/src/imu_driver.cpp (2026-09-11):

#include "imu_driver.h"

// ----------------------------------------------------------------------------
// Register Definitions
// ----------------------------------------------------------------------------

// BMI160
#define BMI160_REG_CHIP_ID      0x00
#define BMI160_CHIP_ID_VAL      0xD8
#define BMI160_REG_DATA_START   0x0C
#define BMI160_REG_ACCEL_RANGE  0x41
#define BMI160_REG_GYRO_RANGE   0x43
#define BMI160_REG_INT_EN_0     0x50
#define BMI160_REG_INT_OUT_CTRL 0x53
#define BMI160_REG_INT_MAP_0    0x55
#define BMI160_REG_INT_MOTION_0 0x5F
#define BMI160_REG_INT_MOTION_1 0x60
#define BMI160_REG_CMD          0x7E

// LSM6DS Series (LSM6DS3 / LSM6DSO / LSM6DSL)
#define LSM6DS_REG_WHO_AM_I     0x0F
#define LSM6DS_REG_CTRL1_XL     0x10 // Accel control
#define LSM6DS_REG_CTRL2_G      0x11 // Gyro control
#define LSM6DS_REG_CTRL6_C      0x15 // Accel low power mode
#define LSM6DS_REG_CTRL10_C     0x19 // Embedded functions (TILT_EN, PEDO_EN, etc.)
#define LSM6DS_REG_WAKE_UP_SRC  0x1B // Wake-up source (reading clears latched WU interrupt)
#define LSM6DS_REG_TAP_SRC      0x1C // Tap source (reading clears latched TAP interrupt)
#define LSM6DS_REG_STATUS_REG   0x1E // Status register
#define LSM6DS_REG_DATA_START   0x22 // Gyro X, Y, Z (0x22-0x27), Accel X, Y, Z (0x28-0x2D)
#define LSM6DS_REG_FUNC_SRC1    0x53 // Embedded function status (TILT_IA)
#define LSM6DS_REG_TAP_CFG      0x58 // Interrupt enable
#define LSM6DS_REG_TAP_CFG0     0x56 // Tap config 0 (LSM6DSO: TAP_X/Y/Z enable, LIR)
#define LSM6DS_REG_TAP_CFG1     0x57 // Tap config 1 (LSM6DSO: TAP_THS_X)
#define LSM6DS_REG_TAP_THS_6D   0x59 // Tap threshold Z / 6D
#define LSM6DS_REG_INT_DUR2     0x5A // Tap durations (DUR, QUIET, SHOCK)
#define LSM6DS_REG_WAKE_UP_THS  0x5B // Wake-up threshold & SINGLE_DOUBLE_TAP
#define LSM6DS_REG_WAKE_UP_DUR  0x5C // Wake-up duration
#define LSM6DS_REG_MD1_CFG      0x5E // Route wake-up to INT1

// MPU-6050
#define MPU_REG_WHO_AM_I        0x75
#define MPU_REG_PWR_MGMT_1      0x6B
#define MPU_REG_PWR_MGMT_2      0x6C
#define MPU_REG_ACCEL_CONFIG    0x1C
#define MPU_REG_GYRO_CONFIG     0x1B
#define MPU_REG_INT_PIN_CFG     0x37
#define MPU_REG_INT_ENABLE      0x38
#define MPU_REG_MOT_THR         0x1F
#define MPU_REG_MOT_DUR         0x20
#define MPU_REG_DATA_START      0x3B // Accel (0x3B-0x40), Temp (0x41-0x42), Gyro (0x43-0x48)

ImuDriver::ImuDriver()
    : _type(IMU_TYPE_NONE), _address(0x00), _chipId(0x00), _initialized(false) {}

bool ImuDriver::writeRegister(uint8_t reg, uint8_t value) {
    Wire.beginTransmission(_address);
    Wire.write(reg);
    Wire.write(value);
    return (Wire.endTransmission() == 0);
}

bool ImuDriver::readRegisters(uint8_t reg, uint8_t* buffer, size_t length) {
    Wire.beginTransmission(_address);
    Wire.write(reg);
    if (Wire.endTransmission(true) != 0) {
        return false;
    }
    size_t received = Wire.requestFrom((int)_address, (int)length, (int)true);
    if (received != length) {
        return false;
    }
    for (size_t i = 0; i < length; ++i) {
        buffer[i] = Wire.read();
    }
    return true;
}

const char* ImuDriver::getChipName() const {
    switch (_type) {
        case IMU_TYPE_BMI160: return "Bosch BMI160";
        case IMU_TYPE_LSM6DS: 
            if (_chipId == 0x69) return "ST LSM6DS3";
            if (_chipId == 0x6C) return "ST LSM6DSO";
            if (_chipId == 0x6A) return "ST LSM6DSL";
            return "ST LSM6DS-Family IMU";
        case IMU_TYPE_MPU6050: return "InvenSense MPU-6050/6500";
        default: return "Unknown / Not Connected";
    }
}

bool ImuDriver::tryInitBmi160(uint8_t addr) {
    _address = addr;
    uint8_t id = 0x00;
    if (!readRegisters(BMI160_REG_CHIP_ID, &id, 1) || id != BMI160_CHIP_ID_VAL) {
        return false;
    }

    _chipId = id;
    writeRegister(BMI160_REG_CMD, 0xB6); // Soft reset
    delay(20);
    writeRegister(BMI160_REG_CMD, 0x11); // Accel normal mode
    delay(10);
    writeRegister(BMI160_REG_CMD, 0x15); // Gyro normal mode
    delay(80);
    writeRegister(BMI160_REG_ACCEL_RANGE, 0x03); // +/- 2g
    writeRegister(BMI160_REG_GYRO_RANGE, 0x00);  // +/- 2000 dps

    _type = IMU_TYPE_BMI160;
    _initialized = true;
    return true;
}
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

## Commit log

2026-08-18 feat: implement auto-detecting IMU driver and verify live sensor stream
2026-08-18 fix: improve Windows Web Bluetooth GATT handshake and connection timing
    [ble_manager.cpp]
2026-08-18 fix: resolve heap exhaustion, enable stable Wi-Fi SoftAP broadcast and safe audio buffering
    [audio_recorder.cpp, config.h, wifi_server.cpp]
2026-08-18 fix: resolve CORS/PNA restrictions with companion proxy server and non-blocking ESP32 web loop
    [main.cpp, wifi_server.cpp]
2026-08-18 fix: resolve high-speed audio playback by adding 4KB flash block caching and deep 16-buffer I2S DMA queue
    [audio_recorder.cpp, main.cpp, wifi_server.cpp]
2026-08-18 fix: eliminate audio cracks and temporal overlap with continuous DMA queue draining and DC-blocking filter
    [audio_recorder.cpp, main.cpp]
2026-08-18 feat: implement discrete 2-channel stereo audio recording and real-time dual-mic DSP noise cancellation engine
    [audio_recorder.cpp, storage_manager.cpp, wifi_server.cpp]
2026-08-18 docs: add comprehensive README with full architecture, REST API and BLE specs, and update PINOUT.md for status LED
2026-08-18 fix: export standard Linear 16-Bit PCM WAV format for universal desktop and mobile playback compatibility
    [wifi_server.cpp]
2026-08-18 feat: optimize pipeline for 8 KB/s mono storage with on-chip dual-mic beamforming noise suppression
    [audio_recorder.cpp, storage_manager.cpp, wifi_server.cpp]
2026-08-19 docs: add W25Q128 SPI-Flash expansion details and recording time comparisons
2026-08-19 feat(hardware): add modular Python KiCad schematic generator, netlist and BOM
    [esp32c3_voice_device.kicad_sch, esp32c3_voice_device_bom.csv]
2026-08-19 feat(hardware): implement complete KiCad 8 project generator with wired schematics, net labels and layout blocks
    [xiao_voice_recorder.kicad_pcb, xiao_voice_recorder.kicad_sch, xiao_voice_recorder_bom.csv]
2026-08-19 feat(hardware): structure separate output folders for KiCad and EasyEDA with 1-click import zip and JLCPCB BOM
    [xiao_voice_recorder.kicad_pcb, xiao_voice_recorder.kicad_sch, xiao_voice_recorder_bom.csv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]
2026-08-19 fix(hardware): resolve inherited ancestor symbols in schematic to fix KiCad loading error
    [xiao_voice_recorder.kicad_sch]
2026-08-19 fix(hardware): fully flatten all extended symbols to eliminate KiCad parent loading errors
    [xiao_voice_recorder.kicad_sch]
2026-08-19 chore: ignore kicad lock files
2026-08-19 fix(hardware): extract clean short library names from SKiDL objects for KiCad 8 schematic symbols
    [xiao_voice_recorder.kicad_sch]
2026-08-20 feat(power): implement ultra-low-power deep sleep with IMU shock wake-up and on-demand peripherals
2026-08-20 fix(firmware): resolve deep sleep heap assertion panic and optimize IMU wakeup
    [ble_manager.cpp, imu_driver.cpp, main.cpp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]
2026-08-20 fix(ble): resolve connection handshake race condition and implement real-time telemetry stream
    [audio_recorder.cpp, ble_manager.cpp, config.h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]
2026-08-20 fix(webserver): resolve 'request handler not found' error and captive portal redirection loops
    [config.h, wifi_server.cpp]
2026-08-20 fix(ble): ensure reliable BLE characteristic write handling for Wi-Fi and remote control commands
    [ble_manager.cpp, main.cpp]
2026-08-21 feat(sync): implement Tiered Adaptive Hybrid Audio Sync on ESP32-C3 and Flutter companion app
2026-08-21 fix(sync, imu): enable real-time 10Hz IMU streaming during recording and reactive BLE clip discovery
    [main.cpp]
2026-08-21 fix(ui, sync): resolve header overlaps, fix clip deduplication, and enhance IMU motion visualizer
    [imu_driver.cpp, main.cpp]
2026-08-21 fix(sync, imu): bind android process to softap network, bypass dialog if connected, and revert imu design
    [wifi_server.cpp]
2026-08-21 chore(hardware): remove KiCad and SKiDL schematic generator files and exports
    [esp32c3_voice_device.kicad_sch, esp32c3_voice_device_bom.csv, xiao_voice_recorder.kicad_pcb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]
2026-08-21 fix(sync): implement direct BLE GATT high-throughput audio streaming to avoid Android L2CAP socket blockage
    [ble_manager.cpp, main.cpp]
2026-08-22 feat(sync): implement 2-stage Plaud Note transfer architecture with WiFi Fast Transfer
2026-08-22 fix(firmware): resolve wifi un-init timeout and prevent duplicate BLE command callback execution
    [ble_manager.cpp, wifi_server.cpp]
2026-08-22 feat(sync): implement phone-hosted local-only hotspot and ESP32 audio upload sync
2026-08-22 fix(sync): enable Wi-Fi modem sleep for BLE coex and resolve hotspot gateway IP
    [wifi_server.cpp, wifi_uploader.cpp]
2026-08-22 fix(audio): integrate audioplayers, fix file manager opening, and add local & MCU clip deletion
    [config.h, main.cpp]
2026-08-22 feat(ble): add auto-connect to nearest xiao device with rssi proximity selection
2026-08-22 fix(recordings): connect refresh button to on-demand inventory fetch with progress indicator
2026-08-23 feat(telemetry): fix live IMU data stream and hardware tap simulation
2026-08-23 feat(scripts): add run_flutter_device.bat for running Flutter on connected device
2026-08-23 fix(ui): restore original compact Test Tap button label
2026-08-23 feat(telemetry): increase IMU telemetry rate to 50 Hz and clean up IMU card UI
2026-08-23 fix(ui): remove top WiFi Fast Transfer chip and revert telemetry rate to 10 Hz
    [main.cpp]
2026-08-23 refactor: remove legacy web prototype and start_app batch file in favor of flutter app
2026-08-24 docs: update solder pads to THT through-holes for battery and switch
2026-09-09 docs(hardware): update BOM, schematic and pinouts for ESP32-C3-MINI-1 V2
    [BOM_V2_ESP32C3_MINI1.xlsx]
2026-09-09 feat(firmware): adapt firmware to V2 production hardware (ESP32-C3-MINI-1, SPI2 flash, active-low dual LEDs)
2026-09-10 feat(sync): add refresh action and complete ESP32 hardware audio sync in companion app
2026-09-10 feat(firmware): add blinking red LED on connected recording and alternating sync blink
2026-09-10 feat(audio): add audio sharing for WhatsApp, remove redundant detail header, and adapt 16MB SPI flash storage UI
2026-09-10 feat(power): lock out deep sleep permanently whenever USB host is connected
2026-09-10 feat(firmware): implement shake-to-wake with arm orientation detection and post-recording grace period
2026-09-10 fix(sync): resolve hardware clip collision and blocking on repeated sessions
    [storage_manager.cpp]
2026-09-10 fix(firmware): mount 16MB SPI flash, prevent audio corruption, and add quality settings
    [audio_recorder.cpp, ble_manager.cpp, config.h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]
2026-09-10 feat(power): implement dynamic battery manager and clean up legacy Xiao references for Custom PCB V2
2026-09-11 fix(storage): resolve 16MB SPI flash mount on MCU and update settings screen capacity
    [spi_flash_driver.cpp, storage_manager.cpp]
2026-09-11 refactor: standardize on Custom Production PCB V2 and remove Seeed Studio Xiao references
2026-09-11 fix(storage): fix 16MB SPI flash mount and protect against audio corruption
    [audio_recorder.cpp, ble_manager.cpp, config.h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]
2026-09-11 fix(storage): resolve 16MB SPI flash init and prevent WAV corruption
    - Add bit-bang CS/SCK pin stabilization, DP wakeup (0xAB), and soft reset (0x66/0x99) before SPI2 driver init to prevent ROM bootloader UART0 glitches from locking Winbond W25Q128
    - Synchronize _extChip->size with probed chip size to fix esp_partition_register_external ESP_ERR_INVALID_SIZE failure
    - Add automatic LittleFS partition formatting when mounting external flash on first boot
    - Increase MIN_FREE_STORAGE_BYTES to 256KB to reserve safe COW copy-on-write margin during WAV header finalize
    - Replace static 40s GATT streaming timeout in Flutter companion app with rolling 15s inactivity watchdog timer
    - Increase BLE GATT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
    [ble_manager.cpp, config.h, esp32c3_hw_test.ino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]
2026-09-11 fix(flash): correct SPI2 pin routing and resolve I2S MCK collision on GPIO 0
    [config.h, spi_flash_driver.cpp, storage_manager.cpp]
2026-09-11 docs: add future roadmap to-do for Wi-Fi antenna exposure to README
2026-09-11 feat(firmware): restrict shake record start to arm-up, add asymmetric LED patterns and gesture feedback placeholders
2026-09-11 fix(power): ensure deep sleep wake-up strictly requires verified shake gesture
    [imu_driver.cpp, main.cpp]
